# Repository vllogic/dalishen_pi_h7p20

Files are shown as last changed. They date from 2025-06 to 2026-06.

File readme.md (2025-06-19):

# 一、简介
#### &emsp;&emsp;大力神派是一款真●开源的FPGA开发板，在设计初期即以`Git`的方式公开项目进度及软硬件资料，期待与志同道合的同学们共同掌握FPGA应用方法，成长为全栈电子工程师。<br/>
#### &emsp;&emsp;在五毛钱单片机大行其道的今天，大力神派完全摒弃简易外设，仅针对USB2.0高速、RGMII千兆以太网、MIPI<sup>1</sup> 三个应用方向。通过板载下载器、USB Sniffer等功能实现开发、工具两用化。
* [1] 硬件接口预留，需FPGA原厂提供Demo

# 二、特色功能
#### &emsp;&emsp;下载器、开发板一体，割断JTAG相关短接点后，下载器可独立使用，支持京微齐力最新版本Fuxi及其绝大多数芯片
#### &emsp;&emsp;支持顶对顶连接20元包邮的`EZ-USB CY7A68013A板`，下载`examples/dalishen_pi_h7p20.ataradov.usb_sniffer`固件，即可变成USB2.0协议分析仪

# 三、板载芯片介绍
### [京微齐力 H7P20N0L128-M3H1](https://hercules-micro.com/index/index/core?id=16)
* 20K Logic cells
* LUT6架构
* 1152Kb EMB
* 内置ARM Cortex-M3 268MHz主频
* 2304KB SRAM
* 合封128Mb pSRAM
* LQFP128封装

### [爱科微 AIC8800FC](https://www.aicsemi.com/)
* 用于高速下载器/调试器
* 预留对外接口，限定3.3V电平

### YT8531C
* RGMII千兆PHY

### USB3343
* ULPI USB2.0高速PHY

# 四、接口介绍
### EZ-USB CY7A68013A对接口
* 用于连接EZ-USB CY7A68013A板，20元左右 [购买连接](https://item.taobao.com/item.htm?id=620955124878)

### MIPI DSI 40P连接器
* 用于连接5.0寸720*1280液晶显示屏，型号`D500C930SV0`带触摸，65元 [购买连接](https://item.taobao.com/item.htm?id=707705009617)
* 注意：MIPI接口当前仅预留，需后续开发支持

### MIPI CSI 24P连接器
* 用于连接OV5640 MIPI摄像头，规格`*-23AF`20元左右 [购买连接](https://item.taobao.com/item.htm?id=816198271497)
* 注意：MIPI接口当前仅预留，需后续开发支持

# 五、硬件
* 绘制中，尚未打样及测试
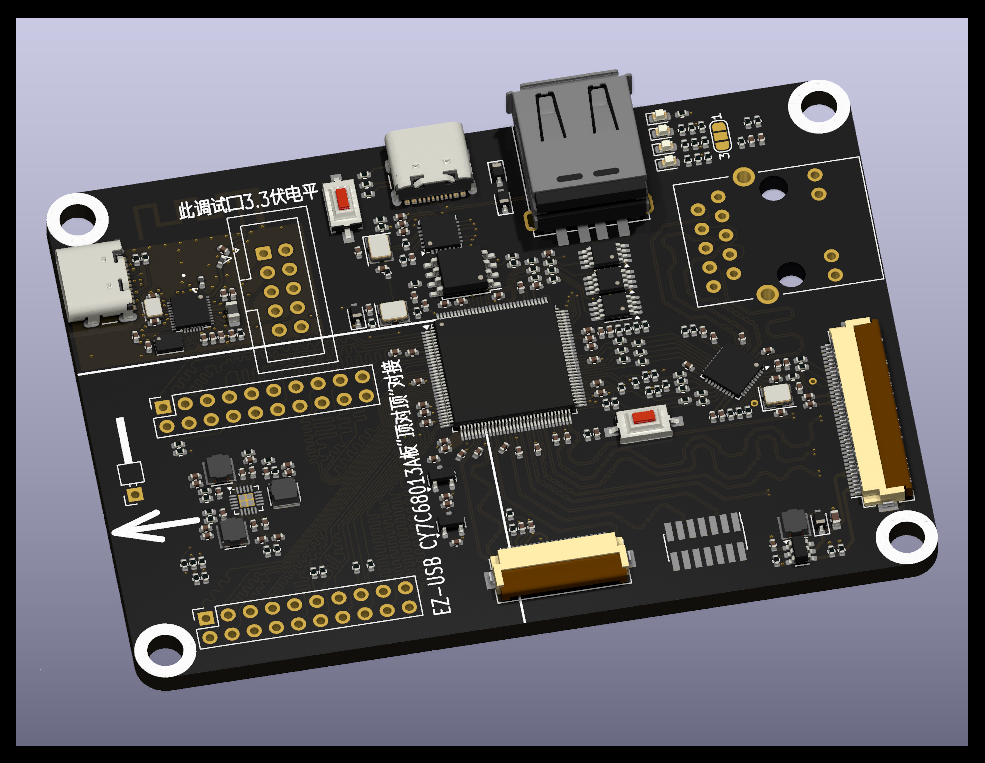
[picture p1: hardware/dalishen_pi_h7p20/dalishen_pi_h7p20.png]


# 六、例程
* [详细说明](./examples/readme.md)

# 七、交流群
* QQ群：635683631

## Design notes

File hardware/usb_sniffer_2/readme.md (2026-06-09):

___
# English
# I. Introduction
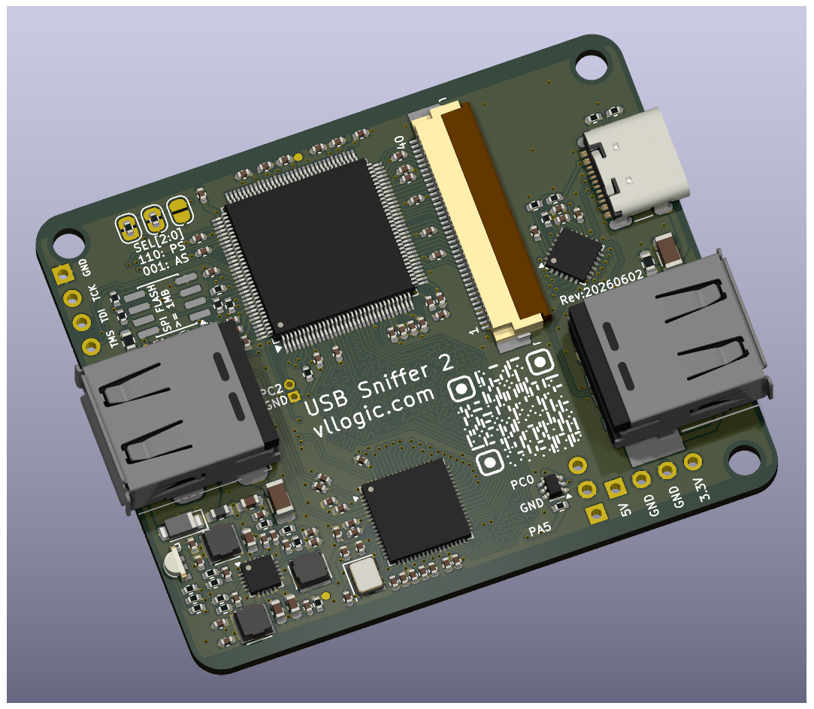
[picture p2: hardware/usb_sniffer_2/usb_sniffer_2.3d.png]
3D
* 
* Hardware design format: KiCad 9.0.6
* The CH32H417 serves as a USB 3.0 forwarder, with a unidirectional communication speed of up to 400MB/s, breaking the speed bottleneck of the 68013.
* 10 pairs of LVDS are broken out via an FFC connector, making it convenient to use as a USB 3.0 + FPGA expansion board.
* Default is PS mode, with reserved SPI FLASH pads. It supports adjustment to AS mode to facilitate secondary development.
# II. Main Components
1. [HME H7P20N0L128-M3H1](https://hercules-micro.com/index/index/core?id=16)
2. [WCH CH32H417WEU6](https://www.wch-ic.com/products/CH32H417.html)
3. [Microchip USB3343-CP-TR](https://www.microchip.com/en-us/product/usb3343)
# III. Schematic
* [Full PDF](https://www.google.com/search?q=./usb_sniffer_2.pdf)
___
# 中文
## 一、简介
* 3D
* 硬件图纸格式：Kicad 9.0.6
* CH32H417作为USB3.0转发器，单向通信速率可达400MB/S，解除68013的速率瓶颈
* 通过FFC连接器引出10对LVDS，方便作为USB3.0 + FPGA拓展板
* 默认PS模式，预留SPI FLASH焊盘，支持调整为AS模式，方便二次开发
## 二、主要器件
1. [HME H7P20N0L128-M3H1](https://hercules-micro.com/index/index/core?id=16)
2. [WCH CH32H417WEU6](https://www.wch-ic.com/products/CH32H417.html)
3. [Microchip USB3343-CP-TR](https://www.microchip.com/en-us/product/usb3343)
## 三、原理图
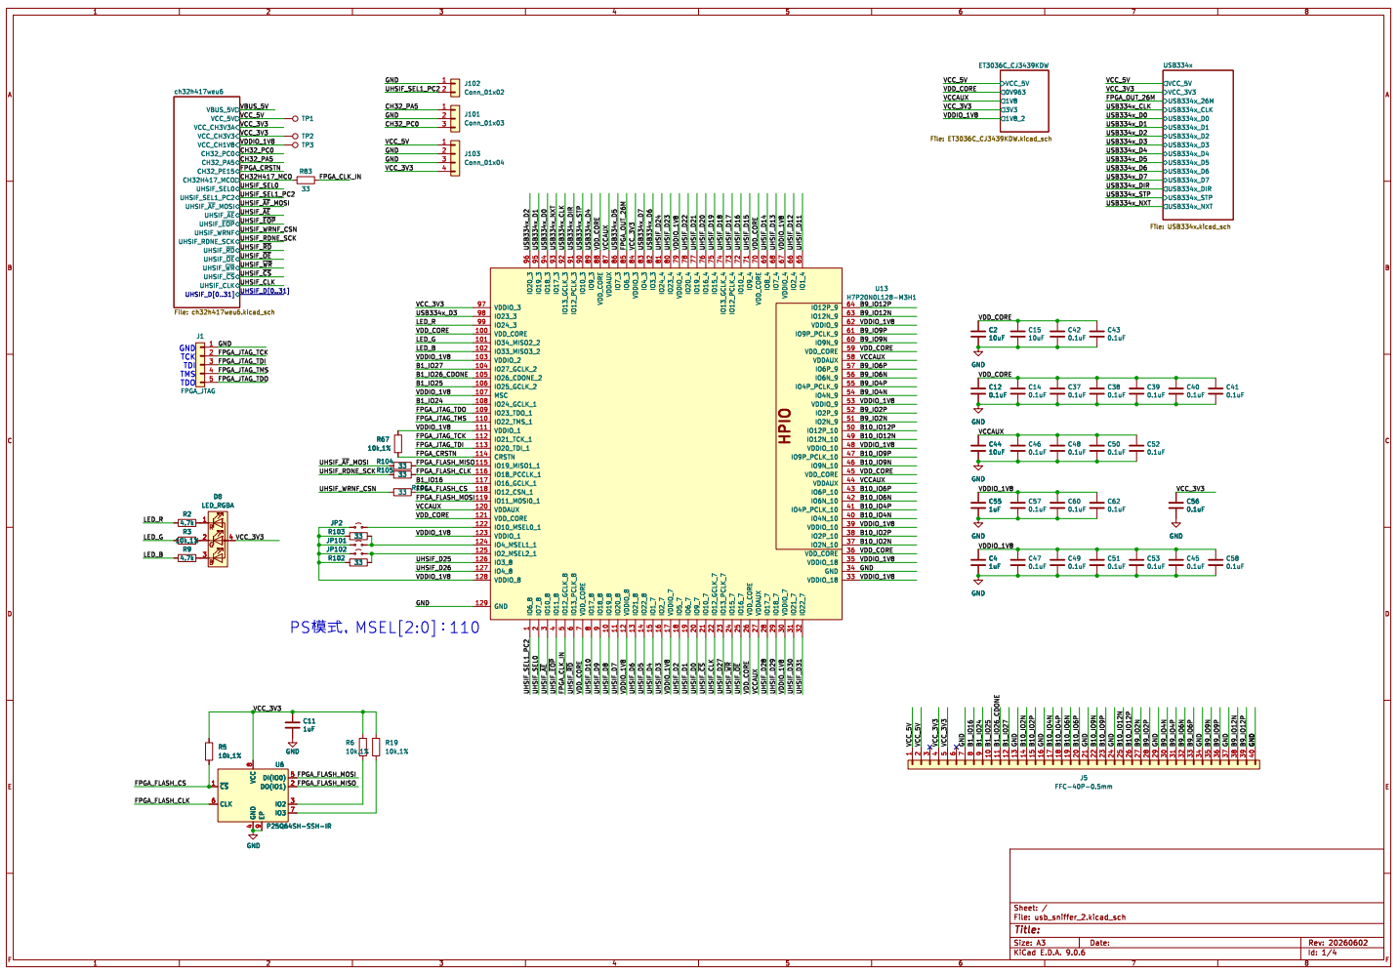
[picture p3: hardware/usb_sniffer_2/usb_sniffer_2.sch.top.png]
* 
* [完整PDF](./usb_sniffer_2.pdf)
___

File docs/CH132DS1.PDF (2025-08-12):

# CH132 数据手册

V2.2

概述

CH132 是 ULPI 接口的高速 USB 收发器芯片（USB PHY、High Speed Transceiver)，兼容 USB 2.0

协议规范和 UTMI+ Low Pin Interface（ULPI）1.1 协议规范。支持 USB2.0 高速 480Mbps、全速 12Mbps

和低速 1.5Mbps 数据发送和接收，可用于为具有 ULPI 接口的 MCU 或 FPGA 扩展 USB 主机口或者设备口。

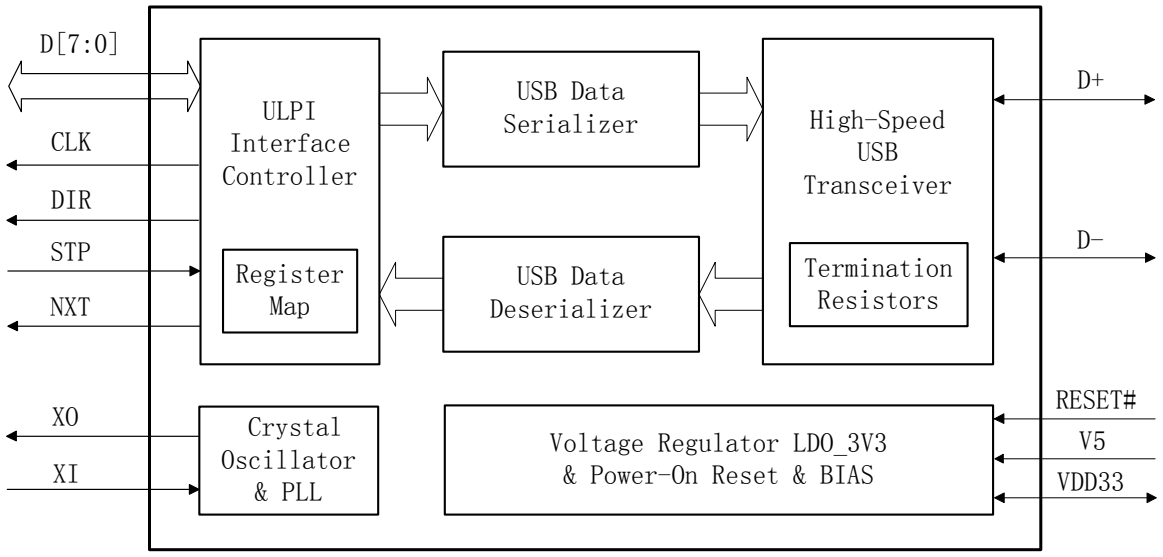
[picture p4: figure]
ULPI Interface Controller; Register Map; USB Data Serializer; USB Data Deserializer; High-Speed USB Transceiver; Termination Resistors; NXT; STP; DIR; CLK; Voltage Regulator LDO_3V3 & Power-On Reset & BIAS; Crystal Oscillator & PLL; RESET# V5 VDD33

特点

- 兼容 USB 2.0 协议规范
- 兼容 UTMI+ Low Pin Interface（ULPI）1.1 协议规范
- 12 Pin 的 ULPI 接口，1.8V～3.3V IO 电平，60MHz 时钟
- 支持 USB host 主机和 USB device 设备
- 支持 USB 高速 High Speed、全速 Full Speed 和低速 Low Speed
- 支持 3 线或 6 线的全速或低速串行模式
- 支持 D+和 D-信号线交换模式
- 内置 3.3V 低压差线性稳压器，支持 3.3V 或 5V 供电输入
- 内置上电复位电路、内置时钟振荡器和 PLL
- 内置阻抗匹配电阻，内置振荡电容，外围电路精简
- 支持 ULPI 输入时钟和输出时钟模式
- USB 引脚具有 6KV 增强 ESD 性能
- 工业级温度范围：-40～85℃
- 提供 QFN24 和 QFN32 等多种封装形式

## 第 1 章 引脚信息

## 1.1 引脚排列

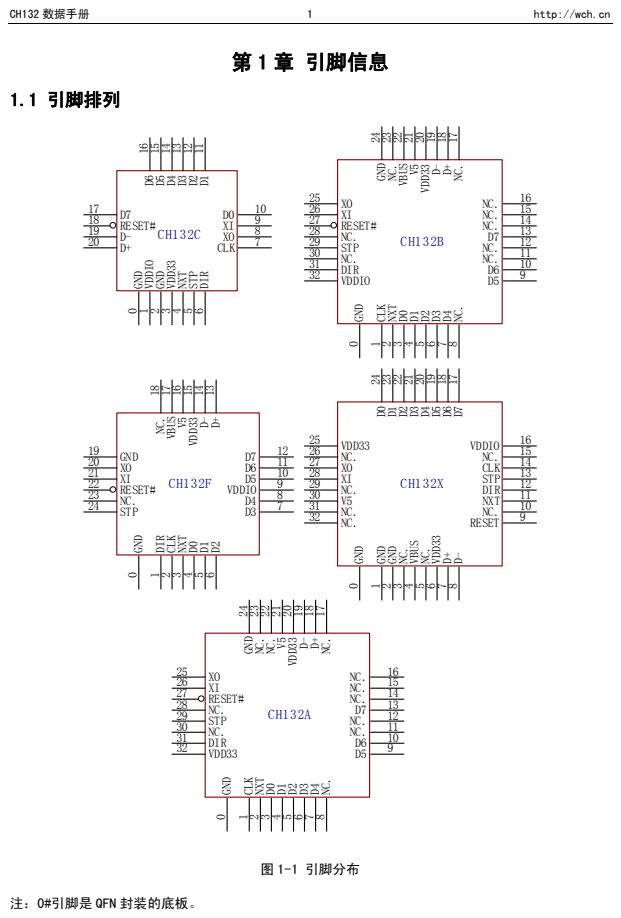
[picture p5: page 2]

CH132 数据手册 | 2 | http://wch.cn

## 1.2 封装

表 1-1 封装说明

封装形式 | 塑体宽度 | 引脚节距 | 封装说明 | 订货型号
QFN20C_2x2 | 2*2mm | | 0.32mm | 12.6mil | WCH 四边无引线 20 脚 | CH132C
QFN24_4x4 | 4*4mm | | 0.5mm | 19.7mil | 四边无引线 24 脚 | CH132F
QFN32_5x5 | 5*5mm | | 0.5mm | 19.7mil | 四边无引线 32 脚 | CH132B
QFN32_5x5 | 5*5mm | | 0.5mm | 19.7mil | 四边无引线 32 脚 | CH132A
QFN32_5x5 | 5*5mm | | 0.5mm | 19.7mil | 四边无引线 32 脚 | CH132X

注：CH132B 基于 CH132A 升级，增加了 VDDIO 引脚，向前兼容 CH132A 引脚。

新设计可用 CH132C/F/B/X，优选小体积的 CH132C。

## 1.3 引脚描述

表 1-2 引脚定义

引脚号 | 引脚 名称 | 类型 | 功能描述
132C | 132F | 132A | 132B | 132X
20 | 13 | 18 | 18 | 7 | D+ | USB | USB2.0 高速差分信号线 DP
19 | 14 | 19 | 19 | 8 | D- | USB | USB2.0 高速差分信号线 DM
- | - | 1 | - | - | CLK | O | ULPI 60MHz 时钟信号输出
7 | 2 | - | 1 | 14 | CLK | I/O | ULPI 60MHz 时钟信号输出或 60MHz 时钟信号输入
4 | 3 | 2 | 2 | 11 | NXT | O | ULPI Next 信号输出
6 | 1 | 31 | 31 | 12 | DIR | O | ULPI Direction 信号输出
5 | 24 | 29 | 29 | 13 | STP | I | ULPI Stop 信号输入，内置可控上拉电流
10 | 4 | 3 | 3 | 24 | D0 | I/O | ULPI 双向数据线 DATA0，内置弱下拉电阻
11 | 5 | 4 | 4 | 23 | D1 | I/O | ULPI 双向数据线 DATA1，内置弱下拉电阻
12 | 6 | 5 | 5 | 22 | D2 | I/O | ULPI 双向数据线 DATA2，内置弱下拉电阻
13 | 7 | 6 | 6 | 21 | D3 | I/O | ULPI 双向数据线 DATA3，内置弱下拉电阻
14 | 8 | 7 | 7 | 20 | D4 | I/O | ULPI 双向数据线 DATA4，内置弱下拉电阻
15 | 10 | 9 | 9 | 19 | D5 | I/O | ULPI 双向数据线 DATA5，内置弱下拉电阻
16 | 11 | 10 | 10 | 18 | D6 | I/O | ULPI 双向数据线 DATA6，内置弱下拉电阻
17 | 12 | 13 | 13 | 17 | D7 | I/O | ULPI 双向数据线 DATA7，内置弱下拉电阻
- | - | 26 | - | - | XI | IL | 晶振输入端，外接 12MHz 晶体一端，或外部时钟输入

CH132 数据手册 | 3 | http://wch.cn
9 | 21 | - | 26 | 27 | XI | IL | 晶振输入端，外接 12MHz 晶体一端，或外部时钟输入， 或短接 GND 则选择从 CLK 引脚输入 ULPI 时钟模式
8 | 20 | 25 | 25 | 28 | XO | OL | 晶振反相输出端，需外接 12MHz 晶体另一端
18 | 22 | 27 | 27 | - | RESET# | I | 复位信号输入，低电平有效，内置上拉电阻
- | - | - | - | 9 | RESET | I | 复位信号输入，高电平有效，内置下拉电阻
- | 17 | - | 22 | 4 | VBUS | I | VBUS 检测输入，高电平有效，内置上拉电阻， 部分型号或批号不支持 VBUS，建议悬空或短接 VDD33
- | 16 | 21 | 21 | 30 | V5 | P | 5V 或 3.3V 电源输入，外接 1uF～10uF 退耦电容
- | 15 | 20 | 20 | 6 | VDD33 | P | LDO 输出及 3.3V 电源输入，外接 0.1uF 并联 1uF～10uF 退耦电容
3 | - | 32 | - | 25 | VDD33 | P | 3.3V 电源输入
1 | 9 | - | 32 | 16 | VDDIO | P | ULPI 接口 I/O 信号电源电压，支持 1.8V、2.5V、3.3V 电压，外接 0.1uF 或 1uF 退耦电容
2 | 19 | 24 | 24 | 1, 2 | GND | P | 公共接地端，可选但建议连接 GND
0 | 0 | 0 | 0 | 0 | GND | P | 公共接地端（QFN 底板），必要连接
- | 18, 23 | 8, 11, 12, 14, 15, 16, 17, 22, 23, 28, 30 | 8, 11, 12, 14, 15, 16, 17, 23, 28, 30 | 3, 5, 10, 15, 26, 29, 31, 32 | NC. | - | 空脚或保留引脚，禁止连接

引脚类型：

(1) I：对于 CH132A 是 3.3V 信号输入，对于 CH132C/F/B/X 是 VDDIO 电压的信号输入。
(2) O：对于 CH132A 是 3.3V 信号输出，对于 CH132C/F/B/X 是 VDDIO 电压的信号输出。
(3) IL：额定 1.2V 电压的信号输入，支持 1.2V～1.4V 电压的信号输入。
(4) OL：额定 1.2V 电压的信号输出。
(5) P：电源或地。
(6) USB：USB 信号。

CH132 数据手册 | 4 | http://wch.cn

## 第 2 章 基本功能

## 2.1 时钟和复位

### 2.1.1 时钟源

CH132 需要 12MHz 时钟源，可以从 XI 引脚输入时钟并保持 XO 悬空，或者将外部 12MHz 晶体连接

在 XI 和 XO 引脚上通过内部振荡器产生时钟源。CH132 再通过 PLL 产生芯片所需的多个时钟：

- USB 低速数据传输使用的 1.5MHz 时钟
- USB 全速数据传输使用的 12MHz 时钟
- USB 高速数据传输使用的 480MHz 时钟
- ULPI 接口控制器使用的 60MHz 时钟
- 其它内部数据处理时需要的时钟

默认情况下为输出 ULPI 时钟模式，从 CLK 引脚向 ULPI 链接器 LINK 输出 60MHz 时钟。

CH132C/F/B/X 还支持输入 ULPI 时钟模式，上电复位期间，如果 CH132 检测到 XI 引脚短接 GND，

则 CLK 引脚为时钟输入，由 ULPI 链接器 LINK 提供 60MHz 时钟，CH132 再由此产生所需的各时钟。

### 2.1.2 上电复位

CH132 内置了上电复位模块，一般无需外部提供复位信号，当电源上电时，芯片内部 POR 上电复

位模块会产生上电复位时序，并延时 Trpor 以等待电源稳定。在运行过程中，当电源电压低于 Vlvr时，

芯片内部 LVR 低压复位模块会产生低压复位直到电压回升，并延时以等待电源稳定。图 2-1 为上电复

位过程以及低压复位过程。

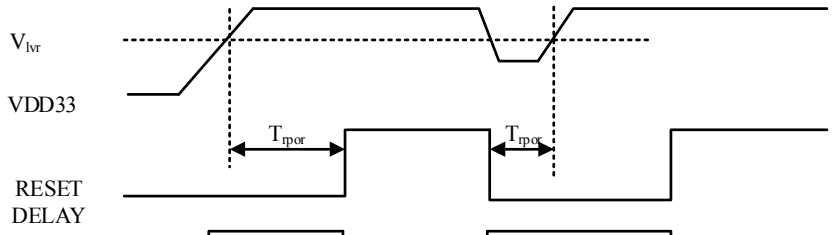
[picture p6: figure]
Vlvr; VDD33; RESET DELAY; Trpor

INTERNAL
RESET

图 2-1 上电复位

### 2.1.3 外部复位

外部复位输入引脚 RESET#内置约 24KΩ上拉电阻，如果外部需要对芯片进行复位，那么可以将该

引脚驱动为低电平（建议开漏驱动），复位的低电平脉宽至少 Twreset。建议不要再外接上拉电阻。

CH132X 的外部复位输入引脚 RESET 内置下拉电阻，驱动该引脚为高电平将复位芯片。

## 2.2 电源

CH132 数据手册 | 5 | http://wch.cn

CH132 内置了低压差线性稳压器 LDO。默认为 3.3V 电源，也支持 5V 电源。

对于 3.3V 供电系统，3.3V 电源同时输入 VDD33 引脚和 V5 引脚，用于内部模拟电路。

对于 5V 供电系统，5V 电源输入 V5 引脚，内部 LDO 在 VDD33 引脚产生 3.3V 电源用于内部模拟电

路。CH132C 没有 V5 引脚，不支持 5V 供电。

两种方式下，VDD33 和 V5 引脚都需要外接退耦电容，VDD33 建议 0.1uF 并联 10uF 或 4.7uF。

避免将 VBUS 的 5V 电源直接输入 V5 引脚，建议在 VBUS 与 V5 引脚之间加入过压保护电路。

对于 CH132C/F/B/X，VDDIO 引脚用于 I/O 电路供电，支持 1.8V、2.5V、3.3V 电压。对于 CH132A，

VDD33 引脚兼用于 I/O 电路供电，仅支持 3.3V 电压。

## 2.3 USB 收发器

CH132 的 USB 收发器承担了 USB 高速、全速和低速数据收发任务。收发器 Transceiver 包括进行

USB 高速、全速和低速数据发送必需的差分驱动电路，承担 USB 高速、全速和低速数据接收的差分和

单端接受器，探测高速总线活动性的电路，探测高速总线断开的电路。USB 端口内置了多种匹配电阻，

包括阻抗匹配电阻、设备上拉电阻、主机下拉电阻等。

关于寄存器和 USB 端口模式的详细关系可以见下表 2-1。

表 2-1 寄存器设置和端口模式关系

USB 端口模式 | 寄存器设置
XCVR SELECT[1:0] | TERM SELECT | OP MODE[1:0] | DP_ PULLDOWN | DM_ PULLDOWN
三态驱动 | xxb | x | 01b | x | x
主机 Chirp | 00b | 0 | 10b | 1 | 1
主机高速 | 00b | 0 | 00b | 1 | 1
主机全速 | x1b | 1 | 00b | 1 | 1
主机高速或全速挂起 | 01b | 1 | 00b | 1 | 1
主机高速或全速恢复 | 01b | 1 | 10b | 1 | 1
主机低速 | 10b | 1 | 00b | 1 | 1
主机低速挂起 | 10b | 1 | 00b | 1 | 1
主机低速恢复 | 10b | 1 | 10b | 1 | 1
主机发送 J 信号/K 信号 | 00b | 0 | 10b | 1 | 1
从机 Chirp | 00b | 1 | 10b | 0 | 0
从机高速 | 00b | 0 | 00b | 0 | 0
从机全速 | 01b | 1 | 00b | 0 | 0
从机高速或全速挂起 | 01b | 1 | 00b | 0 | 0
从机高速或全速恢复 | 01b | 1 | 10b | 0 | 0
从机发送 J 信号或 K 信号 | 00b | 0 | 10b | 0 | 0

## 2.4 ULPI 接口控制器

CH132 数据手册 | 6 | http://wch.cn

CH132 提供了兼容 ULPI（UTMI+ Low Pin Interface）1.1 协议的 12 Pin 接口，这个接口应该连

接到 ULPI 链接器 LINK 的 ULPI 接口上，链接器另一端是 USB 控制器。

此 ULPI 接口控制器具有以下功能：

- ULPI 协议兼容的接口和寄存器设置
- 允许通过 USB 主机或从机设备进行功能性控制
- 解析 USB 发送或接收的数据
- 确定 USB 数据发送、数据接收、中断和寄存器操作优先级
- 3 线串行模式
- 6 线串行模式

## 2.5 ULPI RX CMD 数据

表 2-2 RXCMD 数据位格式

位 | 名称 | 默认值 | 描述
[1:0] | LineState | 00b | 对应 UTMI+ LineState 两个信号： LineState[0]对应接收 DP 的单端数据， LineState[1]对应接收 DM 的单端数据
[3:2] | Reserved | 00b | 保留，总是 00
[5:4] | RxEvent | 00b | UTMI 事件信号编码：
数值 | RxActive | RxError | HostDisconnect
00 | 0 | 0 | 0
01 | 1 | 0 | 0
11 | 1 | 1 | 0
10 | X | X | 1
6 | Reserved | 0 | 保留，总是 0
7 | Reserved | 0 | 保留，数据需忽略

## 2.6 3 线和 6 线串行模式

CH132 提供了 3 线或 6 线串行模式，根据需要选择 3 线或 6 线接口的串行模式以传输全速或低速

USB 包。3 线串行模式接口映射如表 2-3 所示，6 线串行模式接口映射如表 2-4 所示。

进入或退出 3 线或 6 线串行模式可以参考 R8_INTF_CTRL 寄存器中关于 3PIN_FSLS_SERIAL 或

6PIN_FSLS_SERIAL 位的描述。

表 2-3 3 线串行接口 ULPI 映射表

信号 | 对应 ULPI 接口 | 方向 | 描述

CH132 数据手册 | 7 | http://wch.cn
信号 | 对应 ULPI 接口 | 方向 | 描述
TX_ENABLE | DATA0 | I | 模式选择，发送使能，高电平有效 0：接收数据； 1：发送数据
DAT | DATA1 | I/O | TX_ENABLE = 1 时，发送 DP 和 DM 的差分数据； TX_ENABLE = 0 时，接收 DP 和 DM 的差分数据
SE0 | DATA2 | I/O | TX_ENABLE = 1 时，发送 DP 和 DM 的 SE0 数据； TX_ENABLE = 0 时，接收 DP 和 DM 的 SE0 数据
Reserved | DATA3 | O, PD | 保留，CH132 引脚输出数据需忽略
Reserved[7:4] | DATA[7:4] | O, PD | 保留，CH132 引脚提供下拉电阻或输出低电平

表 2-4 6 线串行接口 ULPI 映射表

信号 | 对应 ULPI 接口 | 方向 | 描述
TX_ENABLE | DATA0 | I | 发送使能，高电平有效
TX_DAT | DATA1 | I | 发送 DP 和 DM 的差分数据。
TX_SE0 | DATA2 | I | 发送 DP 和 DM 的 SE0 数据。
Reserved | DATA3 | O, PD | 保留，CH132 引脚输出数据需忽略
RX_DP | DATA4 | O | 接收 DP 的单端数据
RX_DM | DATA5 | O | 接收 DM 的单端数据
RX_RCV | DATA6 | O | 接收 DP 和 DM 的差分数据
Reserved | DATA7 | O, PD | 保留，CH132 引脚提供下拉电阻或输出低电平

CH132 数据手册 | 8 | http://wch.cn

## 第 3 章 ULPI 寄存器

## 3.1 寄存器描述

本手册中在对寄存器进行描述时可能使用了下列缩写：

寄存器位属性 | 属性描述
RO | 只读属性，数据由硬件生成和改变。
WO | 只写属性（不可读，读值不确定）
RW | 可读，可写。

CH132 系列芯片 ULPI 接口操作相关寄存器描述，默认基于 CH132B 和 CH132C/F/X。其它型号例

如 CH132A，如果存在部分不同则特别加注。本手册不适用于 CH132H。

表 3-1 CH132 ULPI 寄存器表

名称 | 地址（6 bit） | 描述 | 复位值
Read | Write | Set | Clear
R8_VENDOR_ID_L | 0x00 | - | - | - | 厂商 ID 寄存器的低字节 | 0x86 [注 10]
R8_VENDOR_ID_H | 0x01 | - | - | - | 厂商 ID 寄存器的高字节 | 0x1A [注 11]
R8_PRODUCT_ID_L | 0x02 | - | - | - | 产品 ID 寄存器的低字节 | 0x32 [注 12]
R8_PRODUCT_ID_H | 0x03 | - | - | - | 产品 ID 寄存器的高字节 | 0x01 [注 13]
R8_FUNC_CTRL | 0x04–0x06 | 0x04 | 0x05 | 0x06 | 功能控制寄存器 | 0x41
R8_INTF_CTRL | 0x07–0x09 | 0x07 | 0x08 | 0x09 | 接口控制寄存器 | 0x00
R8_OTG_CTRL | 0x0A–0x0C | 0x0A | 0x0B | 0x0C | OTG 控制寄存器 | 0x06
R8_USB_INTR_EN_R | 0x0D–0x0F | 0x0D | 0x0E | 0x0F | USB 上升中断使能寄存器 | 0x01
R8_USB_INTR_EN_F | 0x10–0x12 | 0x10 | 0x11 | 0x12 | USB 下降中断使能寄存器 | 0x01
R8_USB_INTR_STAT | 0x13 | - | - | - | USB 中断状态寄存器 | 0x00
R8_USB_INTR_L | 0x14 | - | - | - | USB 中断锁存寄存器 | 0x00
R8_SCRATCH | 0x16–0x18 | 0x16 | 0x17 | 0x18 | 测试寄存器 | 0x00
R8_USB_IO_SWAP | 0x39–0x3B | 0x39 | 0x3A | 0x3B | USB I/O 引脚交换寄存器 | 0x00 [注 14]
| 其它 | | | | 保留 | 0x00

（1）R：Read，可读寄存器，如果没有对应的 W/S/C 则说明是只读寄存器。

（2）W：Write，寄存器写入，操作时新的数据将直接覆盖此寄存器原有的数据。

（3）S：Set，寄存器按位置 1，操作时新的数据将与此寄存器原数据按位或运算后写入。

（4）C：Clear，寄存器按位清 0，操作时新的数据将与此寄存器原数据按位与运算后写入。

注 10、注 11、注 12、注 13：对于 CH132A 为 0x00。

注 14：CH132A 不支持此寄存器。

建议：每次上电或复位后向 R8_FUNC_CTRL 和 R8_OTG_CTRL 寄存器中设置目标参数，不管原值；

无需操作和使用 R8_USB_INTR_*各寄存器，可以用 RXCMD 中的 RxEvent/LineState 状态实现。

CH132 数据手册 | 9 | http://wch.cn

功能控制寄存器（R8_FUNC_CTRL, Address R = 04h/05h/06h,W = 04h,S = 05h,C = 06h）

位 | 名称 | 访问 | 描述 | 复位值
7 | Reserved | RO | 保留 | 0
6 | SUSPENDM | RW | 芯片挂起： 进入低功耗模式，低有效。ULPI 链接器可以通过 STP 退 出低功耗模式。当芯片退出低功耗模式自动置 1 此位。 0：低功耗模式； 1：正常。 | 1
5 | RESET | RW | 内部复位： 高有效。此复位不复位 ULPI 接口和寄存器。 当复位结束后，芯片将解除 DIR 并自动清零此位。 0：正常； 1：使能复位。 | 0
[4:3] | OP MODE | RW | 操作模式：选择传输过程中的位编码方式。 00：正常； 01：不驱动； 10：关闭位插入和 NRZI 编码； 11：保留 | 00b
2 | TERM SELECT | RW | 端口电阻选项： 控制端口上拉下拉电阻和高速传输匹配电阻，取决于 XCVR SELECT、OP MODE、DP_PULLDOWN 和 DM_PULLDOWN。 详见表 2-1 | 0
[1:0] | XCVR SELECT | RW | 收发器速度选择： 00：使能高速收发器； 01：使能全速收发器； 10：使能低速收发器； 11：使能全速收发器，收发低速包（自动加全速包前缀） | 01b

接口控制寄存器（R8_INTF_CTRL, Address R = 07h/08h/09h,W = 07h,S = 08h,C = 09h）

位 | 名称 | 访问 | 描述 | 复位值
7 | INTF_PROT_DIS | RW | 关闭接口保护： 当 ULPI 链接器不向 STP 和 DATA[7:0]输出时，控制芯片内 置的 ULPI 接口保护电路。 0：使能 ULPI 接口保护电路，STP 提供弱上拉。 1：关闭 ULPI 保护电路，关闭 STP 的弱上拉 | 0
[6:2] | Reserved | RO | 保留 | 00000b
1 | 3PIN_FSLS_SERIAL | RW | 3 线全速低速串行模式： 将 ULPI 接口变为 3 位串行接口，在退出 3 线串行模式时芯 | 0

CH132 数据手册 | 10 | http://wch.cn
| | | 片自动清零此位。 0：关闭 3 线串行模式，全速低速包通过 ULPI 并口传输； 1：使能 3 线串行模式，全速低速包通过 3 线接口传输
0 | 6PIN_FSLS_SERIAL | RW | 6 线全速低速串行模式： 将 ULPI 接口变为 6 位串行接口，在退出 6 线串行模式时芯 片自动清零此位。 0：关闭 6 线串行模式，全速低速包通过 ULPI 并口传输； 1：使能 6 线串行模式，全速低速包通过 6 线接口传输 | 0

OTG 控制寄存器（R8_OTG_CTRL, Address R = 0Ah/0Bh/0Ch,W = 0Ah,S = 0Bh,C = 0Ch）

位 | 名称 | 访问 | 描述 | 复位值
[7:3] | Reserved | RO | 保留 | 00000b
2 | DM_PULLDOWN | RW | 使能 DM 的主机下拉电阻： 0：关闭 DM 的下拉电阻； 1：使能 DM 的下拉电阻 | 1
1 | DP_PULLDOWN | RW | 使能 DP 的主机下拉电阻： 0：关闭 DP 的下拉电阻； 1：使能 DP 的下拉电阻 | 1
0 | Reserved | RO | 保留 | 0

USB 上升中断使能寄存器（R8_USB_INTR_EN_R, Address R = 0Dh/0Eh/0Fh,W = 0Dh,S = 0Eh,C = 0Fh）

位 | 名称 | 访问 | 描述 | 复位值
[7:1] | Reserved | RO | 保留 | 0000000b
0 | HOST_DISCON_R | RW | 主机端口断开中断使能： 使能当 HOST_DISCON 从 0 到 1，即断开时产生中断 | 1

USB 下降中断使能寄存器（R8_USB_INTR_EN_F, Address R = 10h/11h/12h,W = 10h,S = 11h,C = 12h）

位 | 名称 | 访问 | 描述 | 复位值
[7:1] | Reserved | RO | 保留 | 0000000b
0 | HOST_DISCON_F | RW | 主机端口断开中断使能： 使能当 HOST_DISCON 从 1 到 0，即连接时产生中断 | 1

USB 中断状态寄存器（R8_USB_INTR_STAT, Address R = 13h）

位 | 名称 | 访问 | 描述 | 复位值

CH132 数据手册 | 11 | http://wch.cn
位 | 名称 | 访问 | 描述 | 复位值
[7:1] | Reserved | RO | 保留 | 0000000b
0 | HOST_DISCON | RO | 主机端口断开状态： 提供 UTMI+主机端口断开状态值。 0：已连接，主机端口检测到 USB 设备； 1：已断开，没有检测到 USB 设备连接。 只支持高速 USB 断开检测，不支持全速和低速断开检测 | 0

USB 中断锁存寄存器（R8_USB_INTR_L, Address R = 14h）

位 | 名称 | 访问 | 描述 | 复位值
[7:1] | Reserved | RO | 保留 | 0000000b
0 | HOST_DISCON | RO | 锁存主机端口断开状态： 当一个未屏蔽的 HOST_DISCON 事件发生时，此位置 1，读 取时自动清零 | 0

测试寄存器（R8_SCARTCH, Address R = 16h）

位 | 名称 | 访问 | 描述 | 复位值
[7:0] | SCARTCH | RW | 测试使用的寄存器，可读可写，不影响芯片功能 | 00000000b

USB I/O 引脚交换寄存器（R8_USB_IO_SWAP, Address R = 39h/3Ah/3Bh,W = 39h,S = 3Ah,C = 3Bh）

位 | 名称 | 访问 | 描述 | 复位值
[7:2] | Reserved | RO | 保留 | 000000b
1 | USB_IO_SWAP | RW | 交换 USB 信号引脚使能： 0：不交换 D+和 D-引脚； 1：交换 D+和 D-引脚 | 0
0 | Reserved | RO | 保留 | 0

CH132 数据手册 | 12 | http://wch.cn

## 第 4 章 参数

### 4.1 绝对最大值（临界或者超过绝对最大值将可能导致芯片工作不正常甚至损坏）

名称 | 参数说明 | 最小值 | 最大值 | 单位
TA | 工作时的环境温度 | -40 | 85 | ℃
TS | 储存时的环境温度 | -55 | 150 | ℃
V5 | LDO 输入电源电压（V5 引脚接电源，GND 引脚接地） | -0.4 | 5.5 | V
VDD33 | 3.3V 电源电压（VDD33 引脚接电源，GND 引脚接地） | -0.4 | 3.8 | V
VDDIO | VDDIO 引脚的 ULPI 接口 I/O 电源电压 | -0.4 | 3.8 | V
VUSB | USB 信号引脚上的电压 | -0.4 | VDD33+0.4 | V
VIO | 其它输入或者输出引脚上的电压（不含 XI 和 XO） | -0.4 | VDD33+0.4 VDDIO+0.4 | V
VXI | XI 引脚上的电压 | -0.3 | 1.5 | V
VESD | USB 引脚上的 HBM 人体模型 ESD 耐压 | 6K | | V

### 4.2 电气参数（测试条件：TA=25℃，V5=VDD33=3.3V，VDDIO=3.3V，不含 USB 信号引脚）

名称 | 参数说明 | 最小值 | 典型值 | 最大值 | 单位
V5 | CH132F/B/X | LDO 输入电源电压， 启用内部 LDO | 3.8 | 5.0 | 5.25 | V
| CH132A | | 4.5 | 5.0 | 5.25
| 外供电源电压 | 无需内部 LDO | 3.15 | 3.3 | 3.45
VDD33 | LDO 输出电压 | 启用内部 LDO | 3.15 | 3.3 | 3.45 | V
| 外供 3.3V 电压 | 无需内部 LDO | 3.15 | 3.3 | 3.45
VDDIO | ULPI 接口 I/O 信号电源电压 | | 1.7 | 3.3 | 3.6 | V
ILDO | 内部电源调节器 LDO 对外负载能力 | | | | 30 | mA
ICC | 高速 USB 传输时的工作电流 | | | 27 | | mA
ICC0 | 高速空闲状态下的工作电流 | | | 19 | | mA
ISLP | 低功耗模式的电源电流（主要是内部 LDO） | | | 0.13 | 0.4 | mA
VILXI | XI 引脚低电平输入电压 | | 0 | | 0.3 | V
VIHXI | XI 引脚高电平输入电压 | | 0.9 | | 1.2 | V
RPD | D7～D0 引脚的下拉电阻 | | 50 | 70 | 100 | KΩ
Vlvr | VDD33 电源低压复位的电压门限 | | 2.5 | 2.9 | 3.15 | V

CH132 数据手册 | 13 | http://wch.cn

VDDIO=3.3V

VIL33 | ULPI 接口 I/O 引脚低电平输入电压 | 0 | | 0.8 | V
VIH33 | ULPI 接口 I/O 引脚高电平输入电压 | 1.9 | | VDDIO | V
VOL33 | I/O 引脚低电平输出电压 @吸入 12mA 电流 | | 0.4 | 0.6 | V
VOH33 | I/O 引脚高电平输出电压 @输出 12mA 电流 | VDDIO-0.6 | VDDIO-0.4 | | V
IPU33 | STP 引脚的上拉电流 | 20 | 40 | 80 | uA

VDDIO=1.8V

VIL18 | ULPI 接口 I/O 引脚低电平输入电压 | 0 | | 0.5 | V
VIH18 | ULPI 接口 I/O 引脚高电平输入电压 | 1.2 | | VDDIO | V
VOL18 | I/O 引脚低电平输出电压 @吸入 5mA 电流 | | 0.4 | 0.6 | V
VOH18 | I/O 引脚高电平输出电压 @输出 5mA 电流 | VDDIO-0.6 | VDDIO-0.4 | | V
IPU18 | STP 引脚的上拉电流 | 7 | 15 | 30 | uA

### 4.3 时序参数（测试条件：TA=25℃，V5=VDD33=3.3V，VDDIO=3.3V）

名称 | 参数说明 | 最小值 | 典型值 | 最大值 | 单位
Fxi | XI 输入时钟频率、XI 外接晶体频率 | 11.995 | 12 | 12.005 | MHz
Dutyxi | XI 输入时钟的占空比 | 35 | 50 | 65 | %
Fstart | 初始状态下 ULPI 的 CLK 时钟频率 | 55 | 60 | 65 | MHz
Fsteady | 稳定状态下 ULPI 的 CLK 时钟频率 | 59.97 | 60 | 60.03 | MHz
Dutycko | ULPI 的 CLK 时钟的占空比 | 45 | 50 | 55 | %
Tsteady | XI 或 CLK 输入时钟稳定到 PLL 稳定的时间 | | 0.5 | 1.5 | mS
Tstart | 退出低功耗模式到 PLL 稳定的时间 | | 2 | 4 | mS
Trpor | 电源上电或低压复位到正常工作的时间 | 10 | 14 | 17 | mS
Twreset | RESET#引脚输入复位的低电平脉宽 | 2 | | | uS
| RESET 引脚输入复位的高电平脉宽 | 2 | | | uS
Trreset | 引脚输入复位到正常工作的时间 | 10 | 13 | 15 | mS

输出 ULPI 时钟模式

TSC | STP 输入建立时间 | | 6 | nS
THC | STP 输入保持时间 | 0 | | nS
TSD | 数据 D0～D7 输入建立时间 | | 6 | nS

CH132 数据手册 | 14 | http://wch.cn
THD | 数据 D0～D7 输入保持时间 | 0 | | nS
TDC | DIR 或 NXT 输出有效的延时 | 0.8 | 6 | nS
TDD | 数据 D0～D7 输出有效的延时 | 0.8 | 8 | nS

输入 ULPI 时钟模式

TSC | STP 输入建立时间 | | 2.5 | nS
THC | STP 输入保持时间 | 1 | | nS
TSD | 数据 D0～D7 输入建立时间 | | 2.5 | nS
THD | 数据 D0～D7 输入保持时间 | 1 | | nS
TDC | DIR 或 NXT 输出有效的延时 | 1.5 | 6.5 | nS
TDD | 数据 D0～D7 输出有效的延时 | 1.5 | 7 | nS

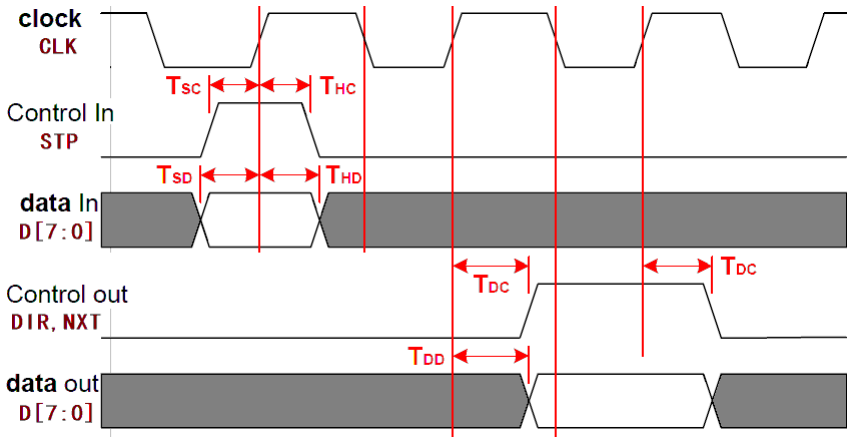
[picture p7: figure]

## 第 5 章 封装

## 5.1 QFN20C_2x2

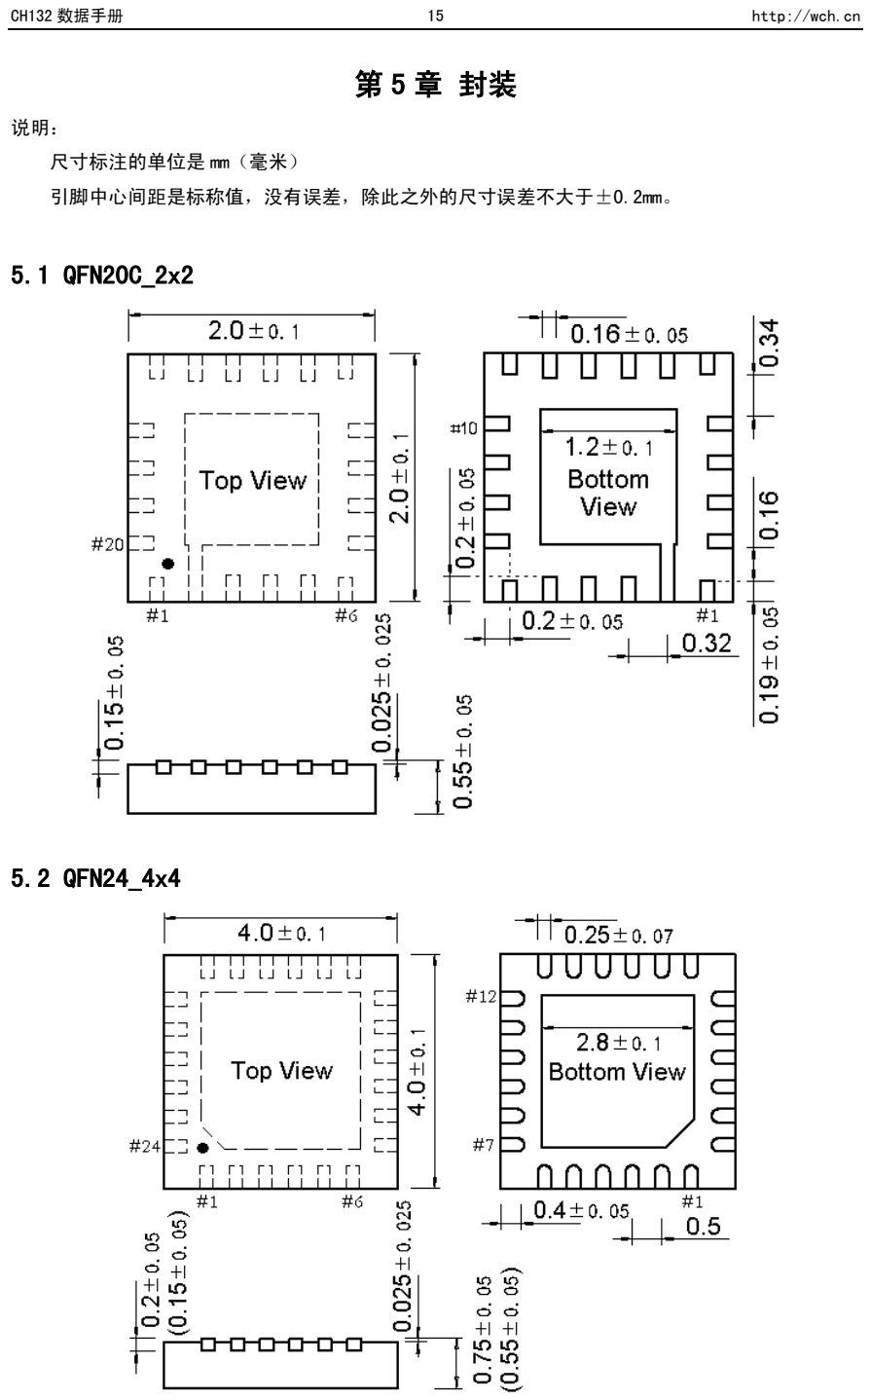
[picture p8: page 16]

CH132 数据手册 | 15 | http://wch.cn

说明：

尺寸标注的单位是 mm（毫米）

引脚中心间距是标称值，没有误差，除此之外的尺寸误差不大于±0.2mm。

## 5.2 QFN24_4x4

CH132 数据手册 | 16 | http://wch.cn

## 5.3 QFN32_5x5

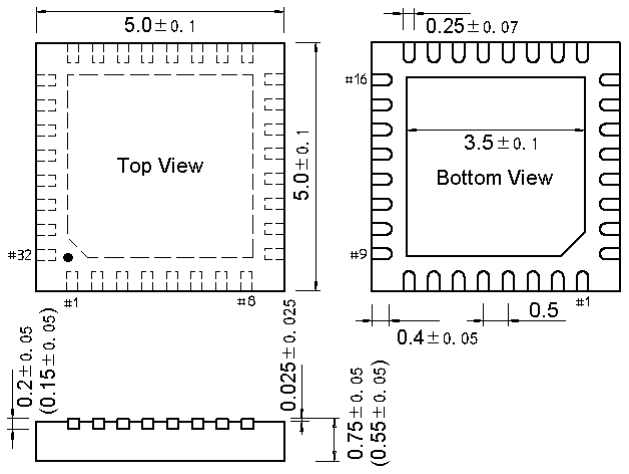
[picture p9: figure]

## 第 6 章 应用

## 6.1 最小系统

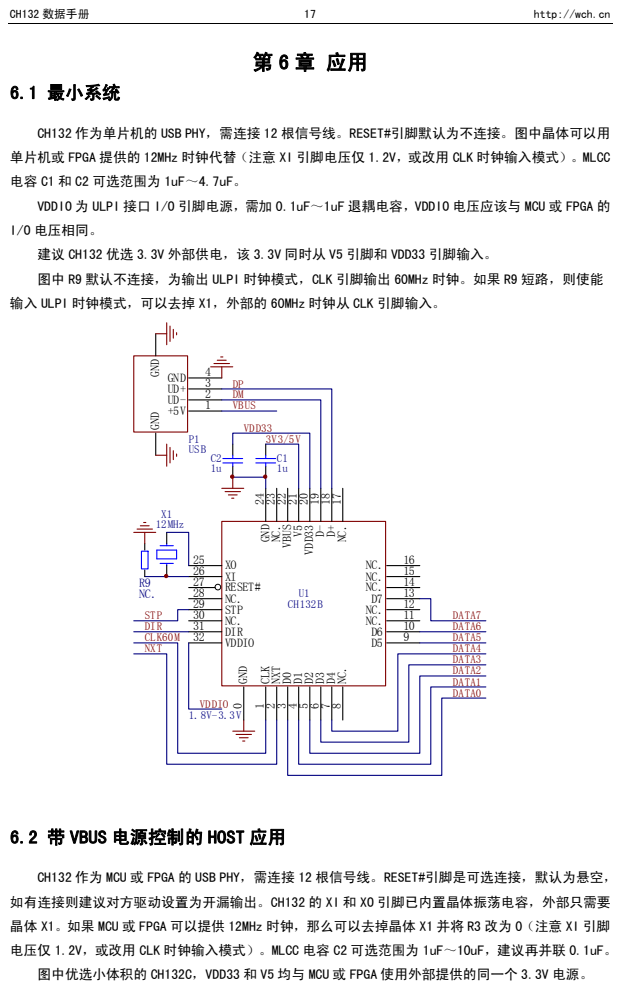
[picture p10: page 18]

CH132 作为单片机的 USB PHY，需连接 12 根信号线。RESET#引脚默认为不连接。图中晶体可以用
单片机或 FPGA 提供的 12MHz 时钟代替（注意 XI 引脚电压仅 1.2V，或改用 CLK 时钟输入模式）。MLCC
电容 C1 和 C2 可选范围为 1uF～4.7uF。
VDDIO 为 ULPI 接口 I/O 引脚电源，需加 0.1uF～1uF 退耦电容，VDDIO 电压应该与 MCU 或 FPGA 的
I/O 电压相同。
建议 CH132 优选 3.3V 外部供电，该 3.3V 同时从 V5 引脚和 VDD33 引脚输入。
图中 R9 默认不连接，为输出 ULPI 时钟模式，CLK 引脚输出 60MHz 时钟。如果 R9 短路，则使能
输入 ULPI 时钟模式，可以去掉 X1，外部的 60MHz 时钟从 CLK 引脚输入。

6.2 带 VBUS 电源控制的 HOST 应用

CH132 作为 MCU 或 FPGA 的 USB PHY，需连接 12 根信号线。RESET#引脚是可选连接，默认为悬空，
如有连接则建议对方驱动设置为开漏输出。CH132 的 XI 和 XO 引脚已内置晶体振荡电容，外部只需要
晶体 X1。如果 MCU 或 FPGA 可以提供 12MHz 时钟，那么可以去掉晶体 X1 并将 R3 改为 0（注意 XI 引脚
电压仅 1.2V，或改用 CLK 时钟输入模式）。MLCC 电容 C2 可选范围为 1uF～10uF，建议再并联 0.1uF。
图中优选小体积的 CH132C，VDD33 和 V5 均与 MCU 或 FPGA 使用外部提供的同一个 3.3V 电源。

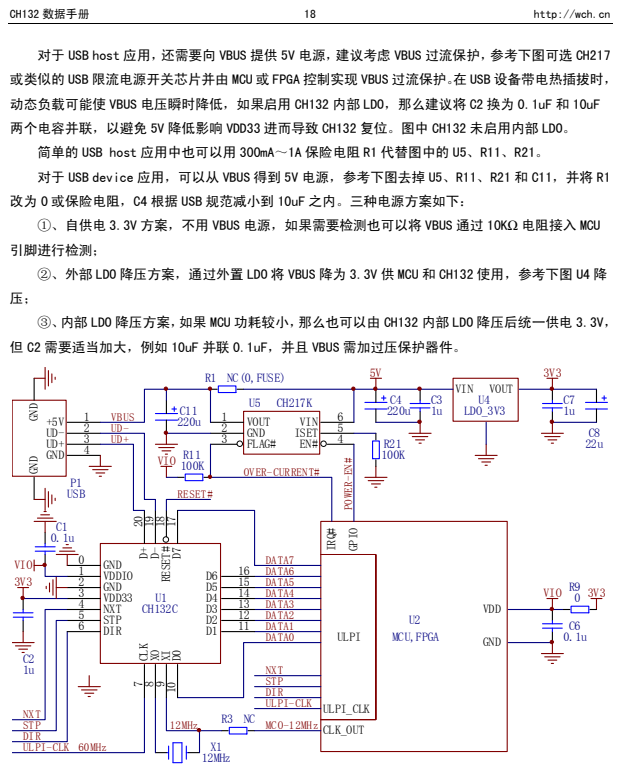
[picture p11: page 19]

对于 USB host 应用，还需要向 VBUS 提供 5V 电源，建议考虑 VBUS 过流保护，参考下图可选 CH217
或类似的 USB 限流电源开关芯片并由 MCU 或 FPGA 控制实现 VBUS 过流保护。在 USB 设备带电热插拔时，
动态负载可能使 VBUS 电压瞬时降低，如果启用 CH132 内部 LDO，那么建议将 C2 换为 0.1uF 和 10uF
两个电容并联，以避免 5V 降低影响 VDD33 进而导致 CH132 复位。图中 CH132 未启用内部 LDO。
简单的 USB host 应用中也可以用 300mA～1A 保险电阻 R1 代替图中的 U5、R11、R21。
对于 USB device 应用，可以从 VBUS 得到 5V 电源，参考下图去掉 U5、R11、R21 和 C11，并将 R1
改为 0 或保险电阻，C4 根据 USB 规范减小到 10uF 之内。三种电源方案如下：
①、自供电 3.3V 方案，不用 VBUS 电源，如果需要检测也可以将 VBUS 通过 10KΩ 电阻接入 MCU
引脚进行检测；
②、外部 LDO 降压方案，通过外置 LDO 将 VBUS 降为 3.3V 供 MCU 和 CH132 使用，参考下图 U4 降
③、内部 LDO 降压方案，如果 MCU 功耗较小，那么也可以由 CH132 内部 LDO 降压后统一供电 3.3V，
但 C2 需要适当加大，例如 10uF 并联 0.1uF，并且 VBUS 需加过压保护器件。

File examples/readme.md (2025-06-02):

# 例程目录

## 一、ataradov.usb_sniffer
* 状态：未测试
* 简介：实现USB2.0 480M逻辑分析仪
* 来源：[usb-sniffer](https://github.com/ataradov/usb-sniffer)
* 版权：`BSD-3-Clause license`
* 移植者：`Vllogic`
* 硬件版本：无要求
* 硬件变动：需焊好排母，并顶对顶接上`EZ-USB CY7C68013A`板

## 二、ultraembedded.core_usb_cdc
* 状态：未测试
* 简介：实现USB2.0 480M CDC设备，通过`USB3343`芯片
* 来源：[core_usb_cdc](https://github.com/ultraembedded/core_usb_cdc)
* 版权：`LGPL-2.1 license`
* 移植者：`Vllogic`
* 硬件版本：无要求
* 硬件变动：无

## 三、udp_over_rgmii
* 状态：未测试
* 简介：基于千兆以太网的UDP测试
* 来源：`TODO`
* 版权：`TODO`
* 移植者：`Vllogic`
* 硬件版本：无要求
* 硬件变动：无

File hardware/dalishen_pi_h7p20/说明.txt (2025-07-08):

1. 由于JTAG口在LQFP128封装上无法作为IO使用，故移除SE0，J, K状态电路

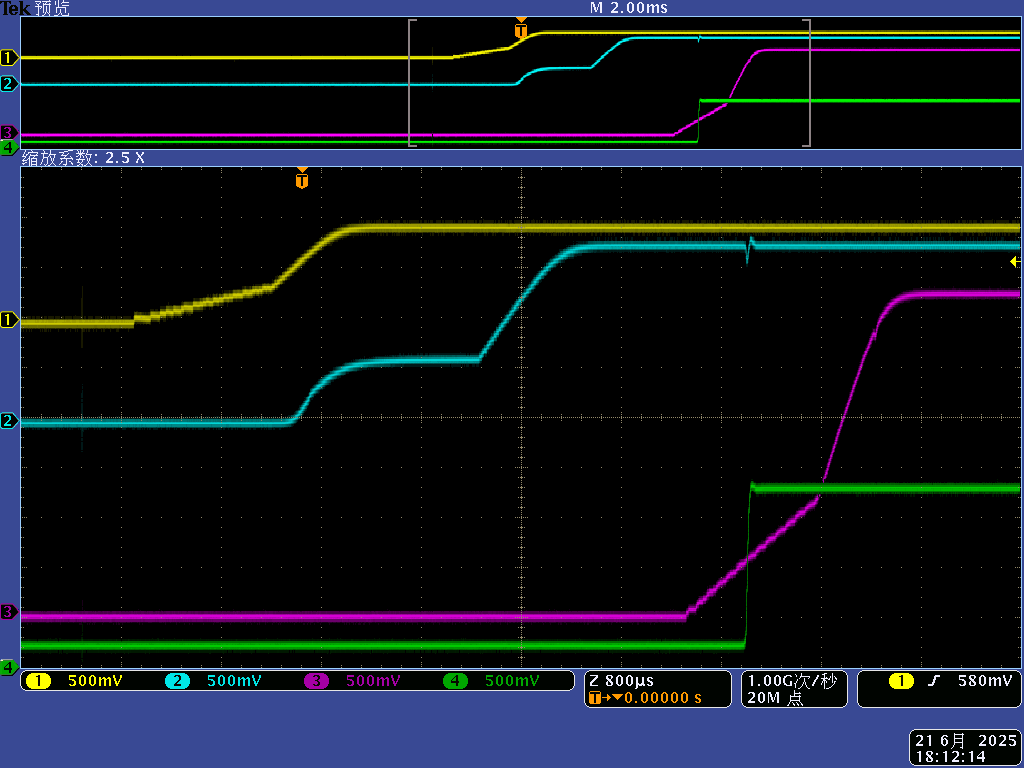
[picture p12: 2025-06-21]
hardware/usb_sniffer_h7p20/上电时序.png

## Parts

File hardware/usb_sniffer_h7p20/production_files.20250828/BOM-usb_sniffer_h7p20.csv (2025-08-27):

Comment | Designator | Footprint | LCSC | Quantity
Trigger | J6 | PinHeader_1x02_P2.54mm_Vertical |  | 1
0.1uF | C50 | C_0402_1005Metric |  | 1
5.1k,1% | R13 | R_0402_1005Metric |  | 1
33k,1% | R38 | R_0402_1005Metric |  | 1
4.7k,1% | R9 | R_0402_1005Metric |  | 1
0.1uF | C53 | C_0402_1005Metric |  | 1
0.1uF | C18 | C_0402_1005Metric |  | 1
10uF | C25 | C_0402_1005Metric |  | 1
20k,1% | R35 | R_0402_1005Metric |  | 1
0.1uF | C41 | C_0402_1005Metric |  | 1
USB_C_Receptacle_USB2.0_16P | J4 | USB_C_Receptacle_16P |  | 1
TestPoint | TP15 | PinHeader_1x01_P1.00mm_Vertical |  | 1
GSV332-MR | U2 | MSOP-8_3x3mm_P0.65mm |  | 1
1uF | C38 | C_0402_1005Metric |  | 1
TestPoint | TP16 | TestPoint_Pad_D0.3mm |  | 1
LED_ABGR | D3 | LED_RGB_Everlight_EASV3015RGBA0_Horizontal |  | 1
0.1uF | C51 | C_0402_1005Metric |  | 1
4.7k | R17 | R_0402_1005Metric |  | 1
150k,1% | R32 | R_0402_1005Metric |  | 1
0.1uF | C52 | C_0402_1005Metric |  | 1
NC | C54 | C_0402_1005Metric |  | 1
CY7C68013A-56LTX | U7 | QFN-56-1EP_8x8mm_P0.5mm_EP4.5x5.2mm |  | 1
TestPoint | TP21 | TestPoint_Pad_D0.3mm |  | 1
0.1uF | C61 | C_0402_1005Metric |  | 1
8.06k,1% | R30 | R_0402_1005Metric |  | 1
TestPoint | TP18 | TestPoint_Pad_D0.3mm |  | 1
0.1uF | C60 | C_0402_1005Metric |  | 1
1uF | C36 | C_0402_1005Metric |  | 1
24M | Y2 | OSC_3225 |  | 1
10k,1% | R12 | R_0402_1005Metric |  | 1
10uF | C13 | C_0402_1005Metric |  | 1
20k,1% | R40 | R_0402_1005Metric |  | 1
24C32 | U8 | SOP-8_3.9x4.9mm_P1.27mm |  | 1
4.7uH,MPL2012S4R7MHT | L3 | L_0805_2012Metric |  | 1
H7P20N0L128-M3H1 | U1 | LQFP-128_14x14mm_P0.4mm_pad |  | 1
20k,1% | R37 | R_0402_1005Metric |  | 1
10uF | C37 | C_0402_1005Metric |  | 1
220pF | C23 | C_0402_1005Metric |  | 1
0.1uF | C59 | C_0402_1005Metric |  | 1
0.1uF | C43 | C_0402_1005Metric |  | 1
0.1uF | C3 | C_0402_1005Metric |  | 1
33k,1% | R33 | R_0402_1005Metric |  | 1
USB_C_Receptacle_USB2.0_16P | J2 | USB_C_Receptacle_16P |  | 1
CJ3439KDW | U9 | SOT-363_SC-70-6 |  | 1
10k,1% | R5 | R_0402_1005Metric |  | 1
4.7k | R23 | R_0402_1005Metric |  | 1
TestPoint | TP17 | TestPoint_Pad_D0.3mm |  | 1
0.1uF | C14 | C_0402_1005Metric |  | 1
USB_A | J3 | USB-AF_YIJIAN |  | 1
0.1uF | C58 | C_0402_1005Metric |  | 1
10uF | C27 | C_0402_1005Metric |  | 1
10uF | C12 | C_0402_1005Metric |  | 1
10uF | C22 | C_0402_1005Metric |  | 1
1uF | C6 | C_0402_1005Metric |  | 1
4.7k,1% | R8 | R_0402_1005Metric |  | 1
0.1uF | C28 | C_0402_1005Metric |  | 1
10uF | C20 | C_0402_1005Metric |  | 1
0.1uF | C15 | C_0402_1005Metric |  | 1
TestPoint | TP20 | TestPoint_Pad_D0.3mm |  | 1
1uF | C9 | C_0402_1005Metric |  | 1
GSV332-MR | U3 | MSOP-8_3x3mm_P0.65mm |  | 1
0.1uF | C49 | C_0402_1005Metric |  | 1
1uF | C26 | C_0402_1005Metric |  | 1
4.7k | R16 | R_0402_1005Metric |  | 1
0.1uF | C34 | C_0402_1005Metric |  | 1
1uF | C10 | C_0402_1005Metric |  | 1
0.1uF | C47 | C_0402_1005Metric |  | 1
0.1uF | C46 | C_0402_1005Metric |  | 1
P25Q64SH-SSH-IR | U6 | SOP-8_3.9x4.9mm_P1.27mm |  | 1
0.1uF | C42 | C_0402_1005Metric |  | 1
10uF | C24 | C_0402_1005Metric |  | 1
SMD0805B100TFT | F1 | Fuse_0805_2012Metric |  | 1
TestPoint | TP2 | PinHeader_1x01_P1.00mm_Vertical |  | 1
5.1k,1% | R26 | R_0402_1005Metric |  | 1
NC | C56 | C_0402_1005Metric |  | 1
10uF | C39 | C_0402_1005Metric |  | 1
CESD5V0D5 | D1 | D_SOD-523 |  | 1
33k,1% | R39 | R_0402_1005Metric |  | 1
0.1uF | C44 | C_0402_1005Metric |  | 1
1.5uH | L5 | L_NR2520xx |  | 1
10k,1% | R6 | R_0402_1005Metric |  | 1
0.1uF | C8 | C_0402_1005Metric |  | 1
5.1k,1% | R3 | R_0402_1005Metric |  | 1
0.1uF | C55 | C_0402_1005Metric |  | 1
10uF | C17 | C_0402_1005Metric |  | 1
10k,1% | R20 | R_0402_1005Metric |  | 1
TestPoint | TP4 | PinHeader_1x01_P1.00mm_Vertical |  | 1
5.1k,1% | R25 | R_0402_1005Metric |  | 1
4.7uH,MPL2012S4R7MHT | L2 | L_0805_2012Metric |  | 1
5.1k,1% | R4 | R_0402_1005Metric |  | 1
220pF | C21 | C_0402_1005Metric |  | 1
FPGA_JTAG | J1 | PinHeader_1x05_P2.54mm_Vertical |  | 1
4.7k | R22 | R_0402_1005Metric |  | 1
0.1uF | C45 | C_0402_1005Metric |  | 1
10k,1% | R28 | R_0402_1005Metric |  | 1
1uF | C2 | C_0402_1005Metric |  | 1
470 | R7 | R_0402_1005Metric |  | 1
USB3343 | U5 | QFN-24-1EP_4x4mm_P0.5mm_EP2.6x2.6mm |  | 1
0.1uF | C33 | C_0402_1005Metric |  | 1
EA3036C | U11 | QFN-20-1EP_3x3mm_P0.4mm_EP1.65x1.65mm |  | 1
5.1k,1% | R18 | R_0402_1005Metric |  | 1
TestPoint | TP14 | PinHeader_1x01_P1.00mm_Vertical |  | 1
12pF | C31 | C_0402_1005Metric |  | 1
10uF | C62 | C_0402_1005Metric |  | 1
TestPoint | TP1 | PinHeader_1x01_P1.00mm_Vertical |  | 1
TestPoint | TP5 | TestPoint_Pad_D0.3mm |  | 1
0.1uF | C29 | C_0402_1005Metric |  | 1
0.1uF | C16 | C_0402_1005Metric |  | 1
10k,1% | R19 | R_0402_1005Metric |  | 1
0.1uF | C4 | C_0402_1005Metric |  | 1
NC | C19 | C_0402_1005Metric |  | 1
4.7k | R15 | R_0402_1005Metric |  | 1
TestPoint | TP3 | PinHeader_1x01_P1.00mm_Vertical |  | 1
1uF | C11 | C_0402_1005Metric |  | 1
0.1uF | C57 | C_0402_1005Metric |  | 1
TestPoint | TP6 | TestPoint_Pad_D0.3mm |  | 1
0.1uF | C48 | C_0402_1005Metric |  | 1
GSV332-MR | U4 | MSOP-8_3x3mm_P0.65mm |  | 1
0.1uF | C35 | C_0402_1005Metric |  | 1
10k,1% | R24 | R_0402_1005Metric |  | 1
5.1k,1% | R2 | R_0402_1005Metric |  | 1
33k,1% | R21 | R_0402_1005Metric |  | 1
12pF | C32 | C_0402_1005Metric |  | 1
220pF | C30 | C_0402_1005Metric |  | 1
10k,1% | R31 | R_0402_1005Metric |  | 1
10k,1% | R34 | R_0402_1005Metric |  | 1
TestPoint | TP7 | TestPoint_Pad_D0.75mm |  | 1
FFC-40P-0.5mm,NC | J5 | TE_4-1734839-0_1x40-1MP_P0.5mm_Horizontal |  | 1
SolderJumper_2_Bridged | JP2 | SolderJumper-2_P1.3mm_Bridged_RoundedPad1.0x1.5mm |  | 1
SolderJumper_2_Open | JP4 | SolderJumper-2_P1.3mm_Open_RoundedPad1.0x1.5mm |  | 1
TestPoint | TP12 | TestPoint_Pad_D0.75mm |  | 1
TestPoint | TP11 | TestPoint_Pad_D0.75mm |  | 1
TestPoint | TP13 | TestPoint_Pad_D0.75mm |  | 1
TestPoint | TP19 | TestPoint_Pad_D0.75mm |  | 1
TestPoint | TP9 | TestPoint_Pad_D0.75mm |  | 1
TestPoint | TP10 | TestPoint_Pad_D0.75mm |  | 1
TestPoint | TP8 | TestPoint_Pad_D0.75mm |  | 1
SolderJumper_2_Open | JP3 | SolderJumper-2_P1.3mm_Open_RoundedPad1.0x1.5mm |  | 1
0.1uF | C1 | C_0402_1005Metric |  | 1

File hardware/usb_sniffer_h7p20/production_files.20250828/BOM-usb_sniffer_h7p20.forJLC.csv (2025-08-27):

Comment | Designator | Footprint | LCSC | Quantity
Trigger | J6 | PinHeader_1x02_P2.54mm_Vertical |  | 1
0.1uF | C50 | 0402 |  | 1
5.1k,1% | R13 | 0402 |  | 1
33k,1% | R38 | 0402 |  | 1
4.7k,1% | R9 | 0402 |  | 1
0.1uF | C53 | 0402 |  | 1
0.1uF | C18 | 0402 |  | 1
10uF | C25 | 0402 |  | 1
20k,1% | R35 | 0402 |  | 1
0.1uF | C41 | 0402 |  | 1
USB_C_Receptacle_USB2.0_16P | J4 | USB_C_Receptacle_16P |  | 1
TestPoint | TP15 | PinHeader_1x01_P1.00mm_Vertical |  | 1
GSV332-MR | U2 | MSOP-8_3x3mm_P0.65mm |  | 1
1uF | C38 | 0402 |  | 1
TestPoint | TP16 | TestPoint_Pad_D0.3mm |  | 1
LED_ABGR | D3 | LED_RGB_Everlight_EASV3015RGBA0_Horizontal |  | 1
0.1uF | C51 | 0402 |  | 1
4.7k | R17 | 0402 |  | 1
150k,1% | R32 | 0402 |  | 1
0.1uF | C52 | 0402 |  | 1
NC | C54 | 0402 |  | 1
CY7C68013A-56LTX | U7 | QFN-56-1EP_8x8mm_P0.5mm_EP4.5x5.2mm |  | 1
TestPoint | TP21 | TestPoint_Pad_D0.3mm |  | 1
0.1uF | C61 | 0402 |  | 1
8.06k,1% | R30 | 0402 |  | 1
TestPoint | TP18 | TestPoint_Pad_D0.3mm |  | 1
0.1uF | C60 | 0402 |  | 1
1uF | C36 | 0402 |  | 1
24M | Y2 | OSC_3225 |  | 1
10k,1% | R12 | 0402 |  | 1
10uF | C13 | 0402 |  | 1
20k,1% | R40 | 0402 |  | 1
24C32 | U8 | SOP-8_3.9x4.9mm_P1.27mm |  | 1
4.7uH,MPL2012S4R7MHT | L3 | L_0805_2012Metric |  | 1
H7P20N0L128-M3H1 | U1 | LQFP-128_14x14mm_P0.4mm_pad |  | 1
20k,1% | R37 | 0402 |  | 1
10uF | C37 | 0402 |  | 1
220pF | C23 | 0402 |  | 1
0.1uF | C59 | 0402 |  | 1
0.1uF | C43 | 0402 |  | 1
0.1uF | C3 | 0402 |  | 1
33k,1% | R33 | 0402 |  | 1
USB_C_Receptacle_USB2.0_16P | J2 | USB_C_Receptacle_16P |  | 1
CJ3439KDW | U9 | SOT-363_SC-70-6 |  | 1
10k,1% | R5 | 0402 |  | 1
4.7k | R23 | 0402 |  | 1
TestPoint | TP17 | TestPoint_Pad_D0.3mm |  | 1
0.1uF | C14 | 0402 |  | 1
USB_A | J3 | USB-AF_YIJIAN |  | 1
0.1uF | C58 | 0402 |  | 1
10uF | C27 | 0402 |  | 1
10uF | C12 | 0402 |  | 1
10uF | C22 | 0402 |  | 1
1uF | C6 | 0402 |  | 1
4.7k,1% | R8 | 0402 |  | 1
0.1uF | C28 | 0402 |  | 1
10uF | C20 | 0402 |  | 1
0.1uF | C15 | 0402 |  | 1
TestPoint | TP20 | TestPoint_Pad_D0.3mm |  | 1
1uF | C9 | 0402 |  | 1
GSV332-MR | U3 | MSOP-8_3x3mm_P0.65mm |  | 1
0.1uF | C49 | 0402 |  | 1
1uF | C26 | 0402 |  | 1
4.7k | R16 | 0402 |  | 1
0.1uF | C34 | 0402 |  | 1
1uF | C10 | 0402 |  | 1
0.1uF | C47 | 0402 |  | 1
0.1uF | C46 | 0402 |  | 1
P25Q64SH-SSH-IR | U6 | SOP-8_3.9x4.9mm_P1.27mm |  | 1
0.1uF | C42 | 0402 |  | 1
10uF | C24 | 0402 |  | 1
SMD0805B100TFT | F1 | Fuse_0805_2012Metric |  | 1
TestPoint | TP2 | PinHeader_1x01_P1.00mm_Vertical |  | 1
5.1k,1% | R26 | 0402 |  | 1
NC | C56 | 0402 |  | 1
10uF | C39 | 0402 |  | 1
CESD5V0D5 | D1 | D_SOD-523 |  | 1
33k,1% | R39 | 0402 |  | 1
0.1uF | C44 | 0402 |  | 1
1.5uH | L5 | L_NR2520xx |  | 1
10k,1% | R6 | 0402 |  | 1
0.1uF | C8 | 0402 |  | 1
5.1k,1% | R3 | 0402 |  | 1
0.1uF | C55 | 0402 |  | 1
10uF | C17 | 0402 |  | 1
10k,1% | R20 | 0402 |  | 1
TestPoint | TP4 | PinHeader_1x01_P1.00mm_Vertical |  | 1
5.1k,1% | R25 | 0402 |  | 1
4.7uH,MPL2012S4R7MHT | L2 | L_0805_2012Metric |  | 1
5.1k,1% | R4 | 0402 |  | 1
220pF | C21 | 0402 |  | 1
FPGA_JTAG | J1 | PinHeader_1x05_P2.54mm_Vertical |  | 1
4.7k | R22 | 0402 |  | 1
0.1uF | C45 | 0402 |  | 1
10k,1% | R28 | 0402 |  | 1
1uF | C2 | 0402 |  | 1
470 | R7 | 0402 |  | 1
USB3343 | U5 | QFN-24-1EP_4x4mm_P0.5mm_EP2.6x2.6mm |  | 1
0.1uF | C33 | 0402 |  | 1
EA3036C | U11 | QFN-20-1EP_3x3mm_P0.4mm_EP1.65x1.65mm |  | 1
5.1k,1% | R18 | 0402 |  | 1
TestPoint | TP14 | PinHeader_1x01_P1.00mm_Vertical |  | 1
12pF | C31 | 0402 |  | 1
10uF | C62 | 0402 |  | 1
TestPoint | TP1 | PinHeader_1x01_P1.00mm_Vertical |  | 1
TestPoint | TP5 | TestPoint_Pad_D0.3mm |  | 1
0.1uF | C29 | 0402 |  | 1
0.1uF | C16 | 0402 |  | 1
10k,1% | R19 | 0402 |  | 1
0.1uF | C4 | 0402 |  | 1
NC | C19 | 0402 |  | 1
4.7k | R15 | 0402 |  | 1
TestPoint | TP3 | PinHeader_1x01_P1.00mm_Vertical |  | 1
1uF | C11 | 0402 |  | 1
0.1uF | C57 | 0402 |  | 1
TestPoint | TP6 | TestPoint_Pad_D0.3mm |  | 1
0.1uF | C48 | 0402 |  | 1
GSV332-MR | U4 | MSOP-8_3x3mm_P0.65mm |  | 1
0.1uF | C35 | 0402 |  | 1
10k,1% | R24 | 0402 |  | 1
5.1k,1% | R2 | 0402 |  | 1
33k,1% | R21 | 0402 |  | 1
12pF | C32 | 0402 |  | 1
220pF | C30 | 0402 |  | 1
10k,1% | R31 | 0402 |  | 1
10k,1% | R34 | 0402 |  | 1
TestPoint | TP7 | TestPoint_Pad_D0.75mm |  | 1
FFC-40P-0.5mm,NC | J5 | TE_4-1734839-0_1x40-1MP_P0.5mm_Horizontal |  | 1
SolderJumper_2_Bridged | JP2 | SolderJumper-2_P1.3mm_Bridged_RoundedPad1.0x1.5mm |  | 1
SolderJumper_2_Open | JP4 | SolderJumper-2_P1.3mm_Open_RoundedPad1.0x1.5mm |  | 1
TestPoint | TP12 | TestPoint_Pad_D0.75mm |  | 1
TestPoint | TP11 | TestPoint_Pad_D0.75mm |  | 1
TestPoint | TP13 | TestPoint_Pad_D0.75mm |  | 1
TestPoint | TP19 | TestPoint_Pad_D0.75mm |  | 1
TestPoint | TP9 | TestPoint_Pad_D0.75mm |  | 1
TestPoint | TP10 | TestPoint_Pad_D0.75mm |  | 1
TestPoint | TP8 | TestPoint_Pad_D0.75mm |  | 1
SolderJumper_2_Open | JP3 | SolderJumper-2_P1.3mm_Open_RoundedPad1.0x1.5mm |  | 1
0.1uF | C1 | 0402 |  | 1

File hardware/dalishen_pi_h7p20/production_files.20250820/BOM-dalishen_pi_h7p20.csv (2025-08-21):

Comment | Designator | Footprint | LCSC | Quantity
10uF | C30 | C_0402_1005Metric |  | 1
47k | R1003 | R_0402_1005Metric |  | 1
NC | R7 | R_0402_1005Metric |  | 1
33 | R86 | R_0402_1005Metric |  | 1
SW_DIP_x03 | SW3 | SW_DIP_SPSTx03_Slide_6.7x9.18mm_W8.61mm_P2.54mm_LowProfile |  | 1
2.49k | R16 | R_0402_1005Metric |  | 1
2.49k | R55 | R_0402_1005Metric |  | 1
0.1uF | C52 | C_0402_1005Metric |  | 1
0R | C78 | C_0402_1005Metric |  | 1
1.5uH | L4 | L_NR2520xx |  | 1
0.1uF | C10 | C_0402_1005Metric |  | 1
0.1uF | C21 | C_0402_1005Metric |  | 1
4.7k | R41 | R_0402_1005Metric |  | 1
33 | R75 | R_0402_1005Metric |  | 1
LED_GREEN | D3 | LED_0603_1608Metric |  | 1
0.1uF | C20 | C_0402_1005Metric |  | 1
NC | C79 | C_0402_1005Metric |  | 1
10k,1% | R5 | R_0402_1005Metric |  | 1
10uF | C47 | C_0402_1005Metric |  | 1
5.1k | R1002 | R_0402_1005Metric |  | 1
XC6206-2.8 | U5 | SOT-23 |  | 1
0R | L1001 | L_0402_1005Metric |  | 1
5.1k | R69 | R_0402_1005Metric |  | 1
33 | R8 | R_0402_1005Metric |  | 1
1uF | C13 | C_0402_1005Metric |  | 1
1uF | C34 | C_0402_1005Metric |  | 1
RJ45_HR911130A | J10 | RJ45_HR911130A |  | 1
33 | R9 | R_0402_1005Metric |  | 1
SW_Push | SW2 | SW-3x6mm_Hxx_SMD |  | 1
10uF | C68 | C_0402_1005Metric |  | 1
1uF | C71 | C_0402_1005Metric |  | 1
5.1k | R21 | R_0402_1005Metric |  | 1
10uH | L1 | L_NR3015 |  | 1
Conn_02x05_Odd_Even | J1 | PinHeader_2x05_P1.27mm_Vertical_SMD |  | 1
0.1uF | C6 | C_0402_1005Metric |  | 1
1uF | C73 | C_0402_1005Metric |  | 1
20k,1% | R29 | R_0402_1005Metric |  | 1
0.1uF | C64 | C_0402_1005Metric |  | 1
OV5640 | J7 | Hirose_FH12-24S-0.5SH_1x24-1MP_P0.50mm_Horizontal |  | 1
NC | X1 | OSC_3225 |  | 1
0.1uF | C11 | C_0402_1005Metric |  | 1
220pF | C28 | C_0402_1005Metric |  | 1
1uF | C50 | C_0402_1005Metric |  | 1
YT8531C | U1 | QFN-40-1EP_5x5mm_P0.4mm_EP3.6x3.6mm |  | 1
1uF | C1012 | C_0402_6mil |  | 1
1.5uH | L3 | L_NR2520xx |  | 1
0.1uF | C48 | C_0402_1005Metric |  | 1
NC | R52 | R_0402_1005Metric |  | 1
8.06k | R89 | R_0402_1005Metric |  | 1
XC6206-1.5 | U8 | SOT-23 |  | 1
2.49k | R56 | R_0402_1005Metric |  | 1
33 | R74 | R_0402_1005Metric |  | 1
4.3pF | C14 | C_0402_6mil |  | 1
5.1k | R1001 | R_0402_1005Metric |  | 1
0 | R6 | R_0402_1005Metric |  | 1
10,1% | R65 | R_0402_1005Metric |  | 1
Antenna_Shield | AE1001 | Texas_SWRA117D_2.4GHz_Left |  | 1
0.1uF | C9 | C_0402_1005Metric |  | 1
5.1k | R62 | R_0402_1005Metric |  | 1
5.1k | R54 | R_0402_1005Metric |  | 1
USB_C_Receptacle_USB2.0_16P | J2 | USB_C_Receptacle_16P |  | 1
33 | R70 | R_0402_1005Metric |  | 1
USB_C_Receptacle_USB2.0_16P | J1001 | USB_C_Receptacle_GCT_USB4105-xx-A_16P_TopMnt_Horizontal |  | 1
5.1k | R68 | R_0402_1005Metric |  | 1
10k | R80 | R_0402_1005Metric |  | 1
10uF | C4 | C_0402_1005Metric |  | 1
5.1k | R40 | R_0402_1005Metric |  | 1
1N5819(S4) | D8 | D_SOD-323_BAT60 |  | 1
10uF | C27 | C_0402_1005Metric |  | 1
4.7uH,MPL2012S4R7MHT | L2 | L_0805_2012Metric |  | 1
33k,1% | R30 | R_0402_1005Metric |  | 1
5.1k | R48 | R_0402_1005Metric |  | 1
10uF | C31 | C_0402_1005Metric |  | 1
NC | C1002 | C_0402_1005Metric |  | 1
1uF | C40 | C_0402_1005Metric |  | 1
5.1k | R43 | R_0402_1005Metric |  | 1
10uF | C37 | C_0402_1005Metric |  | 1
0.1uF | C18 | C_0402_1005Metric |  | 1
10uF | C33 | C_0402_1005Metric |  | 1
33 | R87 | R_0402_1005Metric |  | 1
Conn_02x10_Odd_Even | CY_J2 | PinSocket_2x10_P2.54mm_Vertical |  | 1
33 | R83 | R_0402_1005Metric |  | 1
1uF | C70 | C_0402_1005Metric |  | 1
5.1k | R77 | R_0402_1005Metric |  | 1
0.1uF | C66 | C_0402_1005Metric |  | 1
NC | C1011 | C_0402_6mil |  | 1
5.1k | R61 | R_0402_1005Metric |  | 1
33 | R85 | R_0402_1005Metric |  | 1
26M | Y1 | OSC_2016 |  | 1
SW_Push | SW4 | SW-3x6mm_Hxx_SMD |  | 1
1uF | C1008 | C_0402_1005Metric |  | 1
10uF | C41 | C_0402_1005Metric |  | 1
SY7201ABC | U4 | SOT-23-6 |  | 1
5.1k | R50 | R_0402_1005Metric |  | 1
0.1uF | C63 | C_0402_1005Metric |  | 1
0.1uF | C59 | C_0402_1005Metric |  | 1
5.1k | R20 | R_0402_1005Metric |  | 1
0.1uF | C42 | C_0402_1005Metric |  | 1
0.1uF | C23 | C_0402_1005Metric |  | 1
NC | Y2 | OSC_3225 |  | 1
220pF | C25 | C_0402_1005Metric |  | 1
1uF | C16 | C_0402_1005Metric |  | 1
H7P20N0L128-M3H1 | U3 | LQFP-128_14x14mm_P0.4mm_pad |  | 1
33k,1% | R36 | R_0402_1005Metric |  | 1
5.1k | R42 | R_0402_1005Metric |  | 1
5.1k | R18 | R_0402_1005Metric |  | 1
TestPoint | TP1 | PinHeader_1x01_P1.00mm_Vertical |  | 1
0.1uF | C19 | C_0402_1005Metric |  | 1
0.1uF | C43 | C_0402_1005Metric |  | 1
26M, 10PPM | Y1001 | OSC_2016 |  | 1
33 | R11 | R_0402_1005Metric |  | 1
2.49k | R38 | R_0402_1005Metric |  | 1
LED_YELLOW | D4 | LED_0603_1608Metric |  | 1
10uF | C57 | C_0402_1005Metric |  | 1
10uF | C1009 | C_0402_1005Metric |  | 1
4.3pF | C12 | C_0402_6mil |  | 1
10uF | C58 | C_0402_1005Metric |  | 1
4.3pF | C1003 | C_0402_1005Metric |  | 1
10uF | C32 | C_0402_1005Metric |  | 1
5.1k | R47 | R_0402_1005Metric |  | 1
10uF | C1005 | C_0402_1005Metric |  | 1
0R | L1003 | L_0402_1005Metric |  | 1
AIC8800FC | U1001 | QFN-36-1EP_4x4mm_P0.35mm_EP2.5x2.5mm |  | 1
220pF | C35 | C_0402_1005Metric |  | 1
0.1uF | C62 | C_0402_1005Metric |  | 1
33k,1% | R34 | R_0402_1005Metric |  | 1
33 | R71 | R_0402_1005Metric |  | 1
33 | R72 | R_0402_1005Metric |  | 1
P25Q80H/P25Q64H/P25Q128HA | U1002 | USON-8-1EP_3x2mm_P0.5mm_EP1.6x02mm |  | 1
CJ3439KDW | U9 | SOT-363_SC-70-6 |  | 1
1uF | C75 | C_0402_1005Metric |  | 1
2.49k | R39 | R_0402_1005Metric |  | 1
10k,1% | R79 | R_0402_1005Metric |  | 1
0.1uF | C7 | C_0402_1005Metric |  | 1
10uF | C1010 | C_0402_6mil |  | 1
1.5uH | L5 | L_NR2520xx |  | 1
10,1% | R64 | R_0402_1005Metric |  | 1
4.7uH,MPL2012S4R7MHT | L1004 | L_0805_2012Metric |  | 1
5.1k | R49 | R_0402_1005Metric |  | 1
20k,1% | R35 | R_0402_1005Metric |  | 1
1uF | C46 | C_0402_1005Metric |  | 1
0.1uF | C45 | C_0402_1005Metric |  | 1
USB_A | J3 | USB-AF_YIJIAN |  | 1
2.49k | R57 | R_0402_1005Metric |  | 1
0.1uF | C53 | C_0402_1005Metric |  | 1
0.1uF | C15 | C_0402_1005Metric |  | 1
USB3343 | U20 | QFN-24-1EP_4x4mm_P0.5mm_EP2.6x2.6mm |  | 1
0.1uF | C17 | C_0402_1005Metric |  | 1
10k,1% | R15 | R_0402_1005Metric |  | 1
5.1k | R76 | R_0402_1005Metric |  | 1
10uF | C24 | C_0402_1005Metric |  | 1
0.1uF | C5 | C_0402_1005Metric |  | 1
1uF,50V | C69 | C_0603_1608Metric |  | 1
10uF | C26 | C_0402_1005Metric |  | 1
10k,1% | R44 | R_0402_1005Metric |  | 1
10k,1% | R90 | R_0402_1005Metric |  | 1
10k | R63 | R_0402_1005Metric |  | 1
SW_Push | SW1 | SW-3x6mm_Hxx_SMD |  | 1
P25Q64SH-SSH-IR | U7 | SOIC-8_P1.27mm_Common |  | 1
10uF | C44 | C_0402_1005Metric |  | 1
Conn_02x10_Odd_Even | CY_J1 | PinSocket_2x10_P2.54mm_Vertical |  | 1
1uF | C39 | C_0402_1005Metric |  | 1
TestPoint | TP2 | PinHeader_1x01_P1.00mm_Vertical |  | 1
1uF | C49 | C_0402_1005Metric |  | 1
1uF | C77 | C_0402_1005Metric |  | 1
NC | R53 | R_0402_1005Metric |  | 1
0.1uF | C55 | C_0402_1005Metric |  | 1
5.1k | R22 | R_0402_1005Metric |  | 1
0.1uF | C8 | C_0402_1005Metric |  | 1
10uF | C38 | C_0402_1005Metric |  | 1
1uF | C76 | C_0402_1005Metric |  | 1
1uF | C1007 | C_0402_1005Metric |  | 1
4.3pF | C1006 | C_0402_1005Metric |  | 1
20k,1% | R31 | R_0402_1005Metric |  | 1
0.1uF | C60 | C_0402_1005Metric |  | 1
0.1uF | C22 | C_0402_1005Metric |  | 1
NC | R51 | R_0402_1005Metric |  | 1
0.1uF | C61 | C_0402_1005Metric |  | 1
1uF | C72 | C_0402_1005Metric |  | 1
33 | R91 | R_0402_1005Metric |  | 1
0.1uF | C54 | C_0402_1005Metric |  | 1
150k,1% | R33 | R_0402_1005Metric |  | 1
5V | J6 | PinSocket_1x01_P2.54mm_Vertical |  | 1
1M | R78 | R_0402_1005Metric |  | 1
D500C930SV0 | J9 | Hirose_FH12-40S-0.5SH_1x40-1MP_P0.50mm_Horizontal |  | 1
0.1uF | C65 | C_0402_1005Metric |  | 1
0.1uF | C67 | C_0402_1005Metric |  | 1
NC | 2x5_2.54.1001 | IDC-Header_2x05_P2.54mm_Vertical |  | 1
5.1k | R46 | R_0402_1005Metric |  | 1
SW_Push | SW5 | SW-3x6mm_Hxx_SMD |  | 1
33 | R84 | R_0402_1005Metric |  | 1
33 | R73 | R_0402_1005Metric |  | 1
0 | R4 | R_0402_1005Metric |  | 1
10uF | C29 | C_0402_1005Metric |  | 1
LED_RED | D1 | LED_0603_1608Metric |  | 1
10k | R81 | R_0402_1005Metric |  | 1
2.49k | R45 | R_0402_1005Metric |  | 1
0.1uF | C56 | C_0402_1005Metric |  | 1
1uF | C1013 | C_0402_6mil |  | 1
NC | C2 | C_0402_1005Metric |  | 1
EA3036C | U6 | QFN-20-1EP_3x3mm_P0.4mm_EP1.65x1.65mm |  | 1
0.1uF | C51 | C_0402_1005Metric |  | 1
10k | R82 | R_0402_1005Metric |  | 1
0.1uF | C74 | C_0402_1005Metric |  | 1
10k,1% | R32 | R_0402_1005Metric |  | 1
10uF | C36 | C_0402_1005Metric |  | 1
LED_BLUE | D2 | LED_0603_1608Metric |  | 1
10k,1% | R19 | R_0402_1005Metric |  | 1
SolderJumper_2_Bridged | JP2 | SolderJumper-2_P1.3mm_Bridged2Bar_RoundedPad1.0x1.5mm |  | 1
SolderJumper_2_Bridged | JP6 | SolderJumper-2_P1.3mm_Bridged_RoundedPad1.0x1.5mm |  | 1
SolderJumper_2_Bridged | JP4 | SolderJumper-2_P1.3mm_Bridged_RoundedPad1.0x1.5mm |  | 1
SolderJumper_2_Bridged | JP7 | SolderJumper-2_P1.3mm_Bridged_RoundedPad1.0x1.5mm |  | 1
TestPoint | TP1005 | TestPoint_Pad_D0.75mm |  | 1
TestPoint | TP1006 | TestPoint_Pad_D0.75mm |  | 1
TestPoint | TP1001 | TestPoint_Pad_D0.75mm |  | 1
SolderJumper_2_Bridged | JP5 | SolderJumper-2_P1.3mm_Bridged_RoundedPad1.0x1.5mm |  | 1
TestPoint | TP1007 | TestPoint_Pad_D0.75mm |  | 1
SolderJumper_2_Bridged | JP3 | SolderJumper-2_P1.3mm_Bridged_RoundedPad1.0x1.5mm |  | 1
SolderJumper_2_Bridged | JP8 | SolderJumper-2_P1.3mm_Bridged_RoundedPad1.0x1.5mm |  | 1
SolderJumper_2_Bridged | JP9 | SolderJumper-2_P1.3mm_Bridged_RoundedPad1.0x1.5mm |  | 1
TestPoint | TP1003 | TestPoint_Pad_D0.75mm |  | 1
TestPoint | TP1002 | TestPoint_Pad_D0.75mm |  | 1
TestPoint | TP1004 | TestPoint_Pad_D0.75mm |  | 1

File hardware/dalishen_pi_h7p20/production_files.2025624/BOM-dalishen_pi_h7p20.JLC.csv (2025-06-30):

Comment | Designator | Footprint | LCSC | Quantity
10uF | C30 | 0402 |  | 1
47k | R1003 | 0402 |  | 1
NC | R7 | 0402 |  | 1
33 | R86 | 0402 |  | 1
SW_DIP_x03 | SW3 | SW_DIP_SPSTx03_Slide_6.7x9.18mm_W8.61mm_P2.54mm_LowProfile |  | 1
2.49k | R16 | 0402 |  | 1
2.49k | R55 | 0402 |  | 1
0.1uF | C52 | 0402 |  | 1
NC | C78 | 0402 |  | 1
1.5uH | L4 | L_NR3015 |  | 1
0.1uF | C10 | 0402 |  | 1
0.1uF | C21 | 0402 |  | 1
4.7k | R41 | 0402 |  | 1
33 | R75 | 0402 |  | 1
LED_GREEN | D3 | LED_0603_1608Metric |  | 1
0.1uF | C20 | 0402 |  | 1
NC | C79 | 0402 |  | 1
10k,1% | R5 | 0402 |  | 1
10uF | C47 | 0402 |  | 1
5.1k | R1002 | 0402 |  | 1
XC6206-2.8 | U5 | SOT-23 |  | 1
0R | L1001 | L_0402_1005Metric |  | 1
5.1k | R69 | 0402 |  | 1
33 | R8 | 0402 |  | 1
1uF | C13 | 0402 |  | 1
1uF | C34 | 0402 |  | 1
RJ45_HR911130A | J10 | RJ45_HR911130A |  | 1
10k,1% | R1 | 0402 |  | 1
33 | R9 | 0402 |  | 1
SW_Push | SW2 | SW-3x6mm_Hxx_SMD |  | 1
10uF | C68 | 0402 |  | 1
1uF | C71 | 0402 |  | 1
5.1k | R21 | 0402 |  | 1
10uH | L1 | L_NR3015 |  | 1
Conn_02x05_Odd_Even | J1 | PinHeader_2x05_P1.27mm_Vertical_SMD |  | 1
0.1uF | C6 | 0402 |  | 1
1uF | C73 | 0402 |  | 1
20k,1% | R29 | 0402 |  | 1
0.1uF | C64 | 0402 |  | 1
OV5640 | J7 | Hirose_FH12-24S-0.5SH_1x24-1MP_P0.50mm_Horizontal |  | 1
NC | X1 | OSC_3225 |  | 1
0.1uF | C11 | 0402 |  | 1
220pF | C28 | 0402 |  | 1
1uF | C50 | 0402 |  | 1
YT8531C | U1 | QFN-40-1EP_5x5mm_P0.4mm_EP3.6x3.6mm |  | 1
1uF | C1012 | 0402 |  | 1
1.5uH | L3 | L_NR3015 |  | 1
0.1uF | C48 | 0402 |  | 1
NC | R52 | 0402 |  | 1
8.06k | R89 | 0402 |  | 1
XC6206-1.5 | U8 | SOT-23 |  | 1
2.49k | R56 | 0402 |  | 1
33 | R74 | 0402 |  | 1
4.3pF | C14 | 0402 |  | 1
5.1k | R1001 | 0402 |  | 1
0 | R6 | 0402 |  | 1
4.7k | R3 | 0402 |  | 1
10,1% | R65 | 0402 |  | 1
Antenna_Shield | AE1001 | Texas_SWRA117D_2.4GHz_Left |  | 1
0.1uF | C9 | 0402 |  | 1
5.1k | R62 | 0402 |  | 1
33k | R2 | 0402 |  | 1
5.1k | R54 | 0402 |  | 1
USB_C_Receptacle_USB2.0_16P | J2 | USB_C_Receptacle_16P |  | 1
33 | R70 | 0402 |  | 1
USB_C_Receptacle_USB2.0_16P | J1001 | USB_C_Receptacle_GCT_USB4105-xx-A_16P_TopMnt_Horizontal |  | 1
5.1k | R68 | 0402 |  | 1
10k | R80 | 0402 |  | 1
10uF | C4 | 0402 |  | 1
5.1k | R40 | 0402 |  | 1
1N5819(S4) | D8 | D_SOD-323_BAT60 |  | 1
10uF | C27 | 0402 |  | 1
0.1uF | C1 | 0402 |  | 1
33k,1% | R30 | 0402 |  | 1
5.1k | R48 | 0402 |  | 1
10uF | C31 | 0402 |  | 1
NC | C1002 | 0402 |  | 1
1uF | C40 | 0402 |  | 1
5.1k | R43 | 0402 |  | 1
10uF | C37 | 0402 |  | 1
0.1uF | C18 | 0402 |  | 1
2.49k | R24 | 0402 |  | 1
10uF | C33 | 0402 |  | 1
33 | R87 | 0402 |  | 1
Conn_02x10_Odd_Even | CY_J2 | PinSocket_2x10_P2.54mm_Vertical |  | 1
33 | R83 | 0402 |  | 1
1uF | C70 | 0402 |  | 1
5.1k | R77 | 0402 |  | 1
0.1uF | C66 | 0402 |  | 1
NC | C1011 | 0402 |  | 1
5.1k | R61 | 0402 |  | 1
33 | R85 | 0402 |  | 1
26M | Y1 | OSC_2016 |  | 1
SW_Push | SW4 | SW-3x6mm_Hxx_SMD |  | 1
1uF | C1008 | 0402 |  | 1
10uF | C41 | 0402 |  | 1
SY7201ABC | U4 | SOT-23-6 |  | 1
5.1k | R50 | 0402 |  | 1
0.1uF | C63 | 0402 |  | 1
0.1uF | C59 | 0402 |  | 1
5.1k | R20 | 0402 |  | 1
0.1uF | C42 | 0402 |  | 1
0.1uF | C23 | 0402 |  | 1
NC | Y2 | OSC_3225 |  | 1
220pF | C25 | 0402 |  | 1
1uF | C16 | 0402 |  | 1
H7P20N0L128-M3H1 | U3 | LQFP-128_14x14mm_P0.4mm_pad |  | 1
33k,1% | R36 | 0402 |  | 1
5.1k | R42 | 0402 |  | 1
5.1k | R18 | 0402 |  | 1
TestPoint | TP1 | PinHeader_1x01_P1.00mm_Vertical |  | 1
0.1uF | C19 | 0402 |  | 1
0.1uF | C43 | 0402 |  | 1
26M, 10PPM | Y1001 | OSC_2016 |  | 1
33 | R11 | 0402 |  | 1
2.49k | R38 | 0402 |  | 1
LED_YELLOW | D4 | LED_0603_1608Metric |  | 1
10uF | C57 | 0402 |  | 1
10uF | C1009 | 0402 |  | 1
4.3pF | C12 | 0402 |  | 1
10uF | C58 | 0402 |  | 1
4.3pF | C1003 | 0402 |  | 1
10uF | C32 | 0402 |  | 1
5.1k | R47 | 0402 |  | 1
10uF | C1005 | 0402 |  | 1
0R | L1003 | L_0402_1005Metric |  | 1
AIC8800FC | U1001 | QFN-36-1EP_4x4mm_P0.35mm_EP2.5x2.5mm |  | 1
220pF | C35 | 0402 |  | 1
0.1uF | C62 | 0402 |  | 1
33k,1% | R34 | 0402 |  | 1
33 | R71 | 0402 |  | 1
33 | R72 | 0402 |  | 1
P25Q80H/P25Q64H/P25Q128HA | U1002 | USON-8-1EP_3x2mm_P0.5mm_EP1.6x02mm |  | 1
2.49k | R23 | 0402 |  | 1
CJ3439KDW | U9 | SOT-363_SC-70-6 |  | 1
1uF | C75 | 0402 |  | 1
2.49k | R39 | 0402 |  | 1
10k,1% | R79 | 0402 |  | 1
0.1uF | C7 | 0402 |  | 1
10uF | C1010 | 0402 |  | 1
1.5uH | L5 | L_NR3015 |  | 1
10,1% | R64 | 0402 |  | 1
4.7uH,MPL2012S4R7MHT | L1004 | L_0805_2012Metric |  | 1
5.1k | R49 | 0402 |  | 1
20k,1% | R35 | 0402 |  | 1
1uF | C46 | 0402 |  | 1
0.1uF | C45 | 0402 |  | 1
USB_A | J3 | USB-AF_YIJIAN |  | 1
2.49k | R57 | 0402 |  | 1
0.1uF | C53 | 0402 |  | 1
0.1uF | C15 | 0402 |  | 1
USB3343 | U20 | QFN-24-1EP_4x4mm_P0.5mm_EP2.6x2.6mm |  | 1
0.1uF | C17 | 0402 |  | 1
LM2903A-VR | U18 | MSOP-8_3x3mm_P0.65mm |  | 1
10k,1% | R15 | 0402 |  | 1
5.1k | R76 | 0402 |  | 1
10uF | C24 | 0402 |  | 1
0.1uF | C5 | 0402 |  | 1
1uF,50V | C69 | 0603 |  | 1
10uF | C26 | 0402 |  | 1
LM2903A-VR | U2 | MSOP-8_3x3mm_P0.65mm |  | 1
10k,1% | R44 | 0402 |  | 1
10k,1% | R90 | 0402 |  | 1
10k | R63 | 0402 |  | 1
SW_Push | SW1 | SW-3x6mm_Hxx_SMD |  | 1
P25Q64SH-SSH-IR | U7 | SOIC-8_P1.27mm_Common |  | 1
10uF | C44 | 0402 |  | 1
Conn_02x10_Odd_Even | CY_J1 | PinSocket_2x10_P2.54mm_Vertical |  | 1
1uF | C39 | 0402 |  | 1
TestPoint | TP2 | PinHeader_1x01_P1.00mm_Vertical |  | 1
1uF | C49 | 0402 |  | 1
1uF | C77 | 0402 |  | 1
NC | R53 | 0402 |  | 1
0.1uF | C55 | 0402 |  | 1
5.1k | R22 | 0402 |  | 1
0.1uF | C8 | 0402 |  | 1
2.49k | R27 | 0402 |  | 1
10uF | C38 | 0402 |  | 1
4.7k | R10 | 0402 |  | 1
1uF | C76 | 0402 |  | 1
1uF | C1007 | 0402 |  | 1
4.3pF | C1006 | 0402 |  | 1
20k,1% | R31 | 0402 |  | 1
0.1uF | C60 | 0402 |  | 1
0.1uF | C22 | 0402 |  | 1
NC | R51 | 0402 |  | 1
0.1uF | C61 | 0402 |  | 1
1uF | C72 | 0402 |  | 1
33 | R91 | 0402 |  | 1
0.1uF | C54 | 0402 |  | 1
2.49k | R25 | 0402 |  | 1
150k,1% | R33 | 0402 |  | 1
5V | J6 | PinHeader_1x01_P2.54mm_Horizontal |  | 1
1M | R78 | 0402 |  | 1
D500C930SV0 | J9 | Hirose_FH12-40S-0.5SH_1x40-1MP_P0.50mm_Horizontal |  | 1
0.1uF | C65 | 0402 |  | 1
0.1uF | C67 | 0402 |  | 1
2.49k | R28 | 0402 |  | 1
NC | 2x5_2.54.1001 | IDC-Header_2x05_P2.54mm_Vertical |  | 1
5.1k | R46 | 0402 |  | 1
SW_Push | SW5 | SW-3x6mm_Hxx_SMD |  | 1
33 | R84 | 0402 |  | 1
LM2903A-VR | U19 | MSOP-8_3x3mm_P0.65mm |  | 1
33 | R73 | 0402 |  | 1
0 | R4 | 0402 |  | 1
10uF | C29 | 0402 |  | 1
LED_RED | D1 | LED_0603_1608Metric |  | 1
10k | R81 | 0402 |  | 1
2.49k | R26 | 0402 |  | 1
2.49k | R45 | 0402 |  | 1
0.1uF | C56 | 0402 |  | 1
1uF | C1013 | 0402 |  | 1
NC | C2 | 0402 |  | 1
EA3036C | U6 | QFN-20-1EP_3x3mm_P0.4mm_EP1.65x1.65mm |  | 1
0.1uF | C51 | 0402 |  | 1
10k | R82 | 0402 |  | 1
0.1uF | C74 | 0402 |  | 1
10k,1% | R32 | 0402 |  | 1
10uF | C36 | 0402 |  | 1
LED_BLUE | D2 | LED_0603_1608Metric |  | 1
10k,1% | R19 | 0402 |  | 1
SolderJumper_2_Bridged | JP2 | SolderJumper-2_P1.3mm_Bridged2Bar_RoundedPad1.0x1.5mm |  | 1
SolderJumper_2_Bridged | JP6 | SolderJumper-2_P1.3mm_Bridged_RoundedPad1.0x1.5mm |  | 1
SolderJumper_2_Open | JP10 | SolderJumper-2_P1.3mm_Open_RoundedPad1.0x1.5mm |  | 1
SolderJumper_2_Bridged | JP4 | SolderJumper-2_P1.3mm_Bridged_RoundedPad1.0x1.5mm |  | 1
TestPoint | TP1005 | TestPoint_Pad_D0.75mm |  | 1
TestPoint | TP1006 | TestPoint_Pad_D0.75mm |  | 1
TestPoint | TP1001 | TestPoint_Pad_D0.75mm |  | 1
SolderJumper_2_Bridged | JP5 | SolderJumper-2_P1.3mm_Bridged_RoundedPad1.0x1.5mm |  | 1
TestPoint | TP1007 | TestPoint_Pad_D0.75mm |  | 1
SolderJumper_2_Bridged | JP3 | SolderJumper-2_P1.3mm_Bridged_RoundedPad1.0x1.5mm |  | 1
SolderJumper_2_Bridged | JP9 | SolderJumper-2_P1.3mm_Bridged_RoundedPad1.0x1.5mm |  | 1
TestPoint | TP1003 | TestPoint_Pad_D0.75mm |  | 1
SolderJumper_2_Open | JP1 | SolderJumper-2_P1.3mm_Open_RoundedPad1.0x1.5mm |  | 1
TestPoint | TP1002 | TestPoint_Pad_D0.75mm |  | 1
TestPoint | TP1004 | TestPoint_Pad_D0.75mm |  | 1

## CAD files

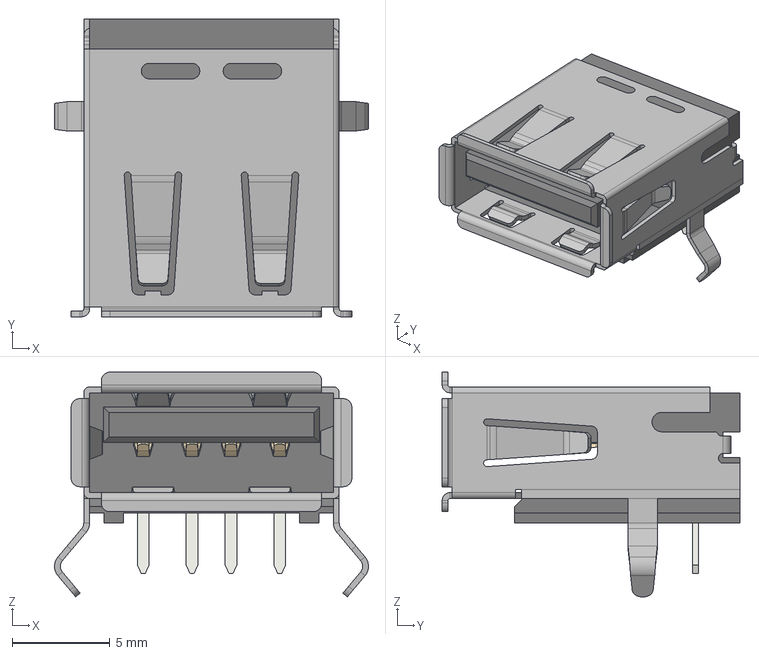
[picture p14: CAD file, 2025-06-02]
hardware/usb_sniffer_2/USB_A_Molex_67643_Horizontal.step
16.1 x 15.3 x 11.5 mm

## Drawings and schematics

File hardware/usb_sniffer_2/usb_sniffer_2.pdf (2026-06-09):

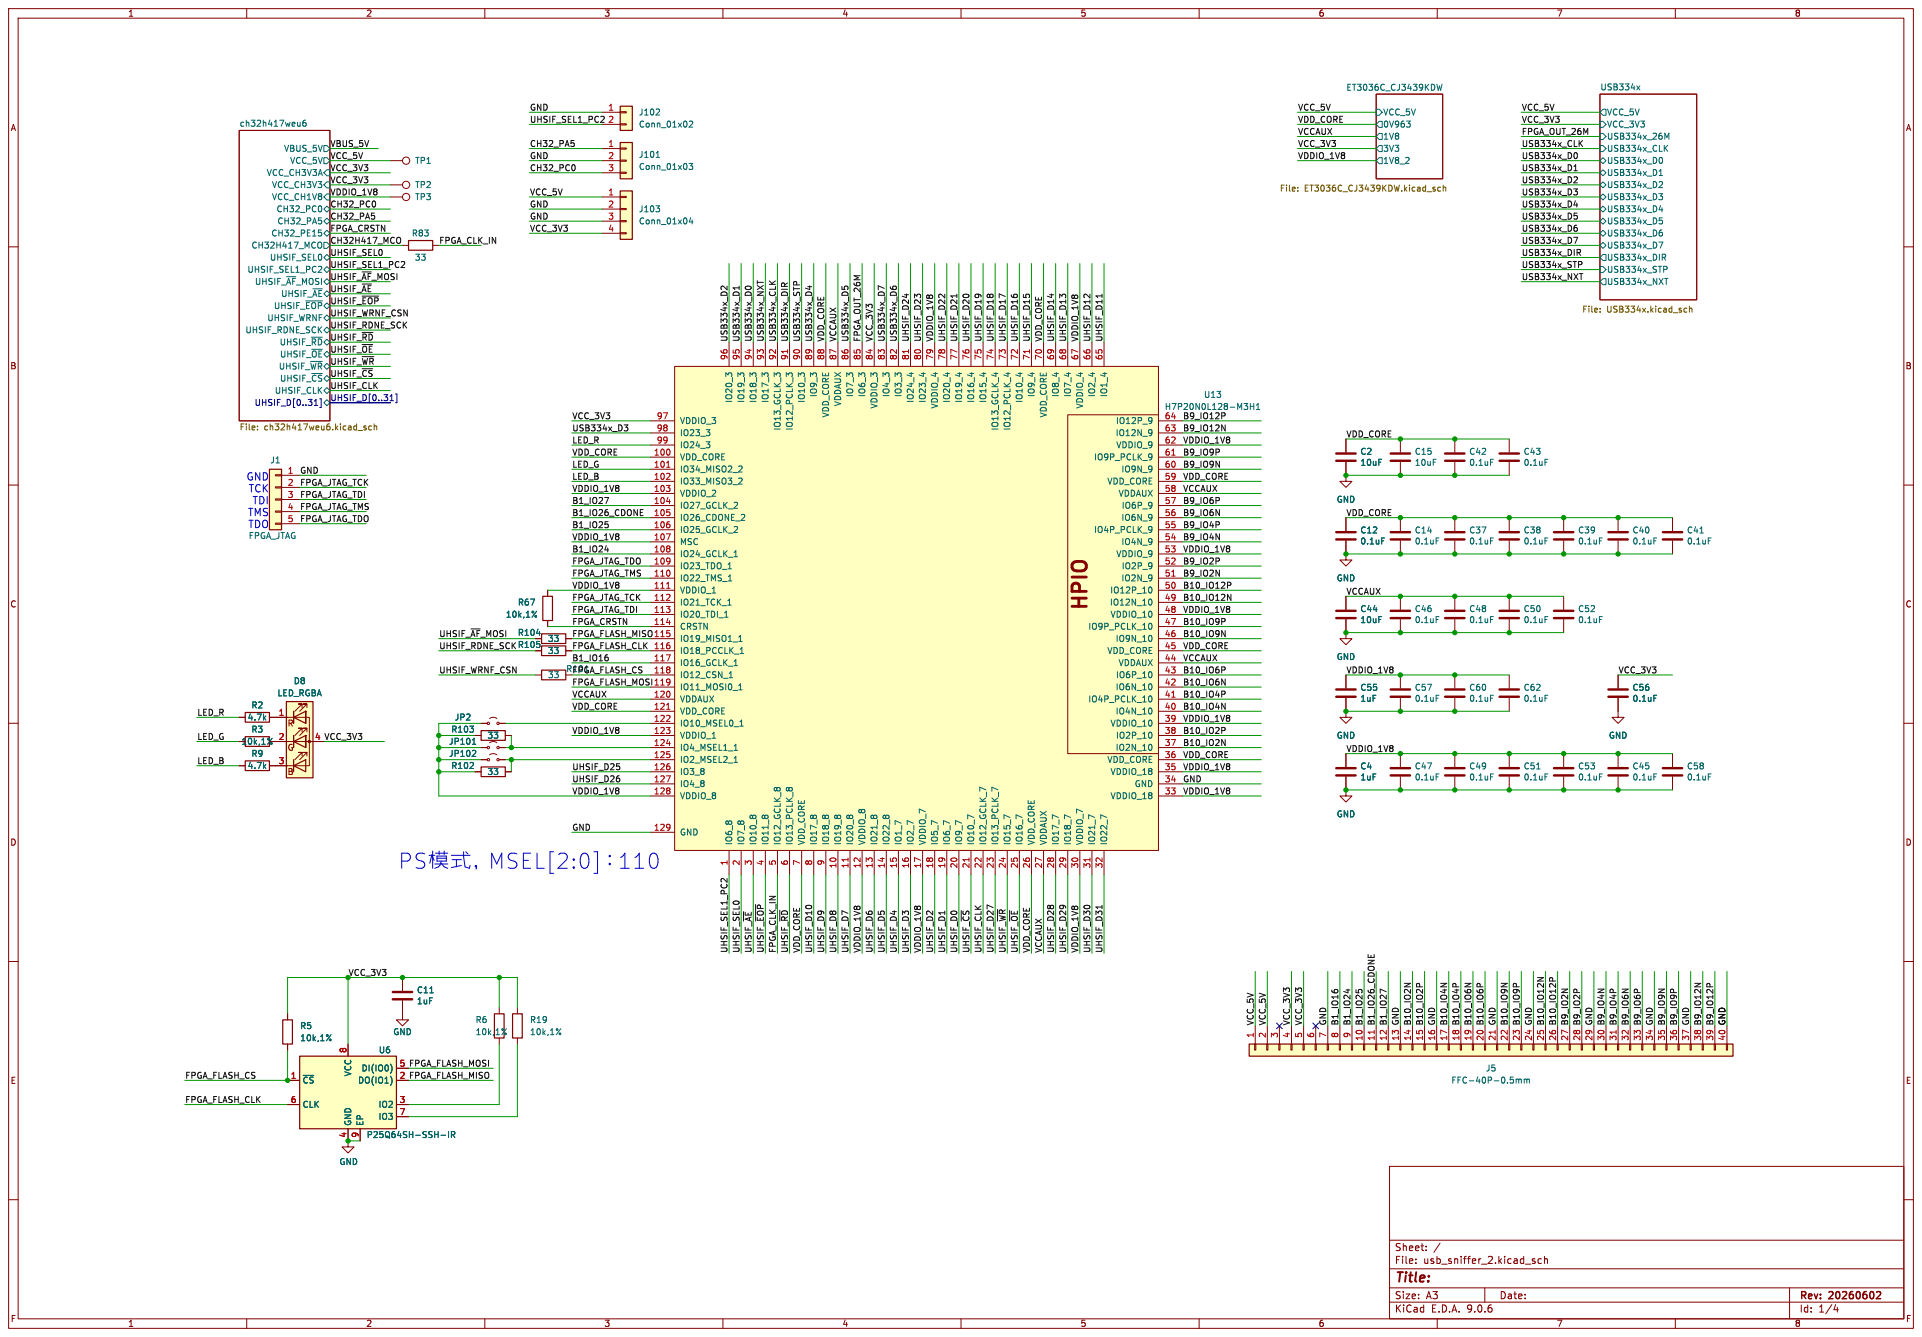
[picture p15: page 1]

Id: 1/4 Title: File: usb_sniffer_2.kicad_sch Sheet: /

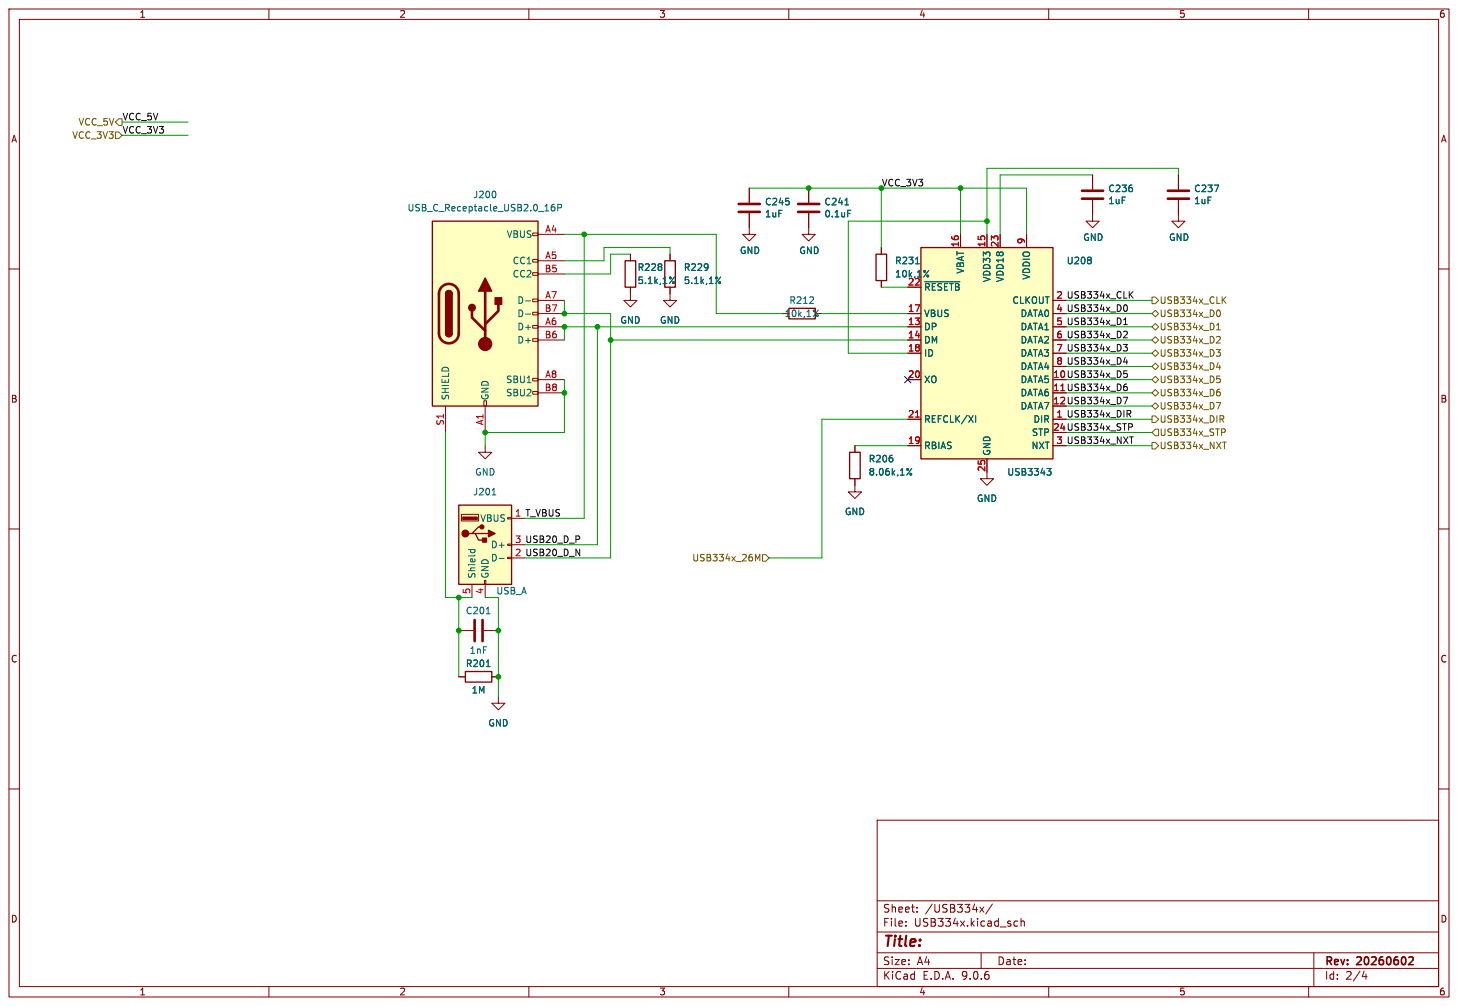
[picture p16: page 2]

9 CLKOUT 2 DATA0 4 DATA1 5 DATA2 6 DATA3 7 DATA4 8 DATA5 10 DATA6 11 DATA7 12 DIR 1 STP 24 NXT 3 GND

9 CLKOUT 2 DATA0 4 DATA1 5 DATA2 6 DATA3 7 DATA4 8 DATA5 10 DATA6 11 DATA7 12 DIR 1 STP 24 NXT 3 U208 USB3343 GND

Id: 2/4 Title: File: USB334x.kicad_sch Sheet: /USB334x/

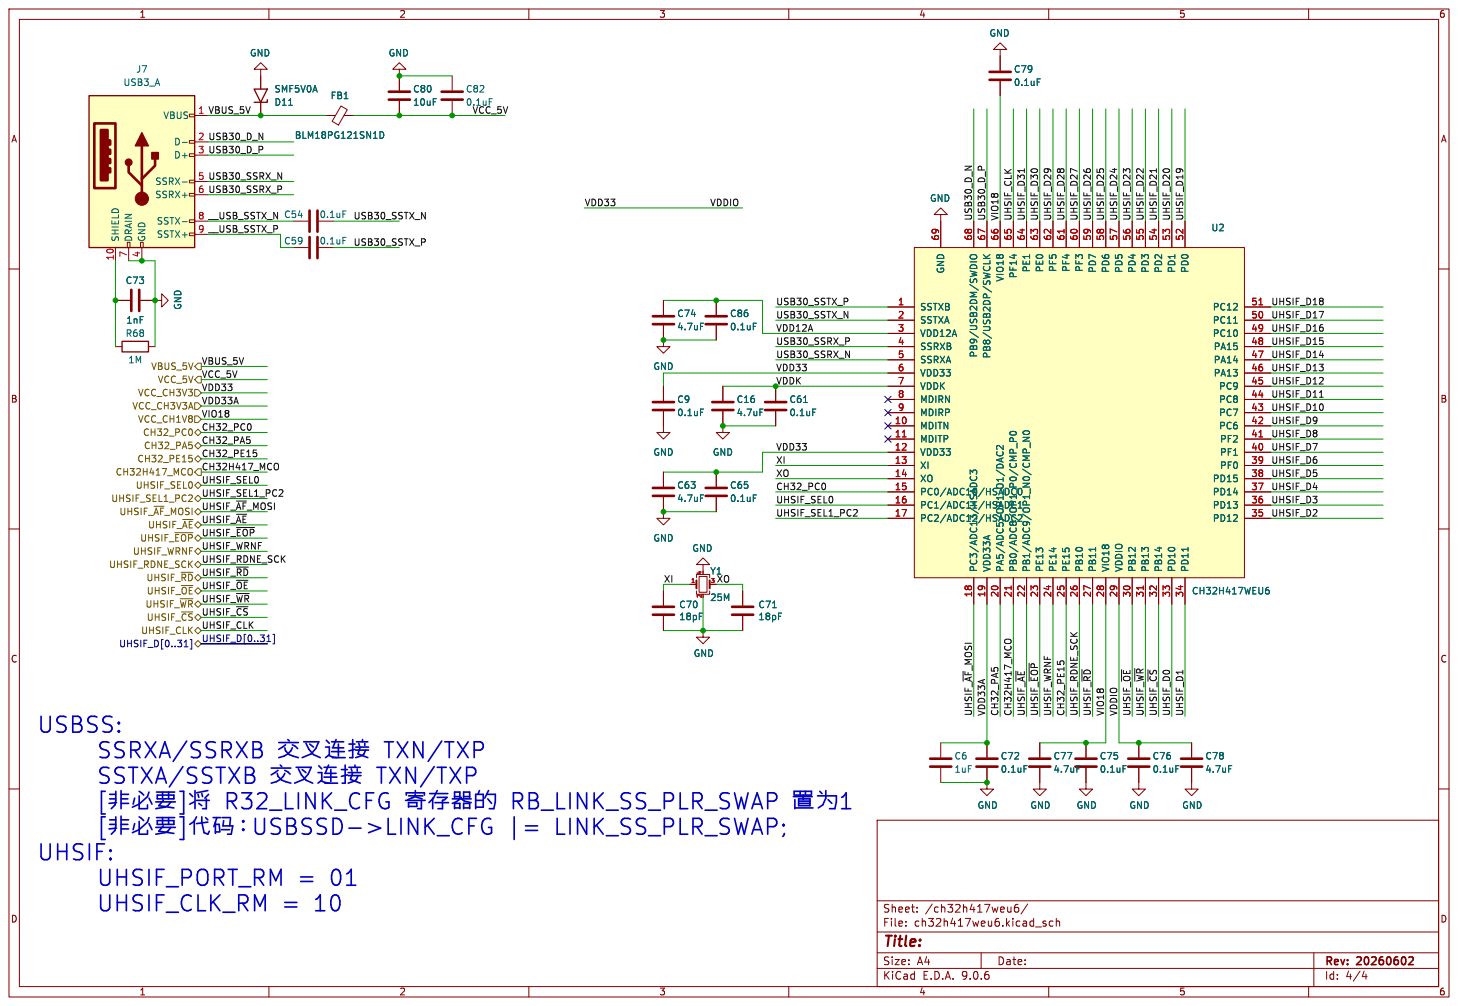
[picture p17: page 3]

4 VBUS 1 D- 2 D+ 3 SSRX- 5 SSRX+ 6 SSTX- 8 SSTX+ 9

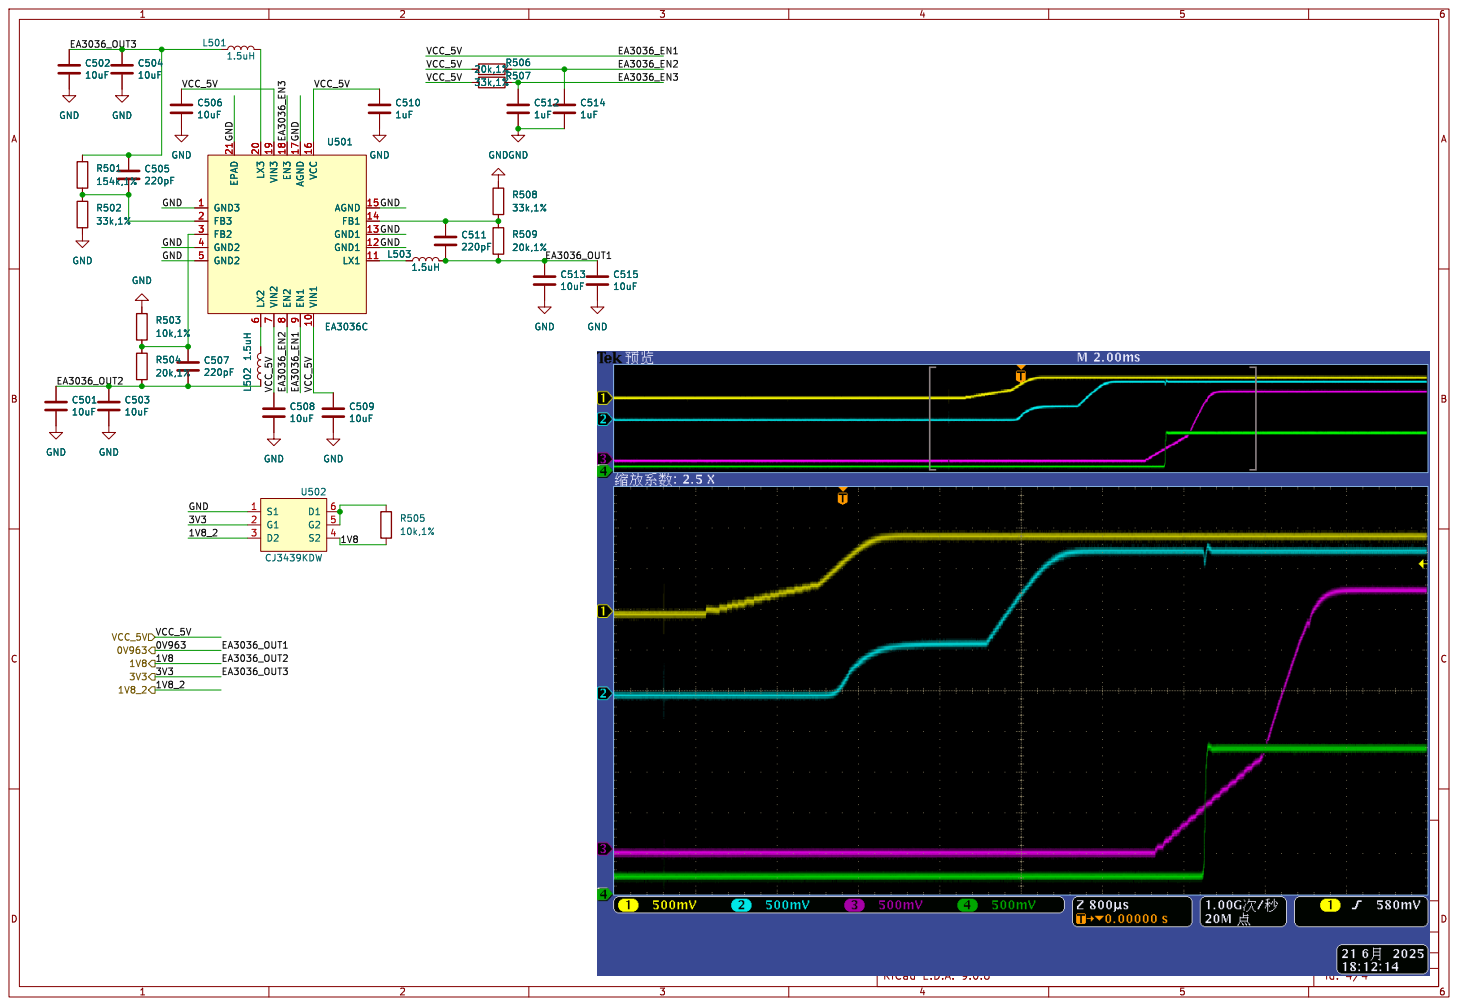
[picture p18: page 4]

Id: 4/4 Title: File: ET3036C_CJ3439KDW.kicad_sch Sheet: /ET3036C_CJ3439KDW/ L502 1.5uH

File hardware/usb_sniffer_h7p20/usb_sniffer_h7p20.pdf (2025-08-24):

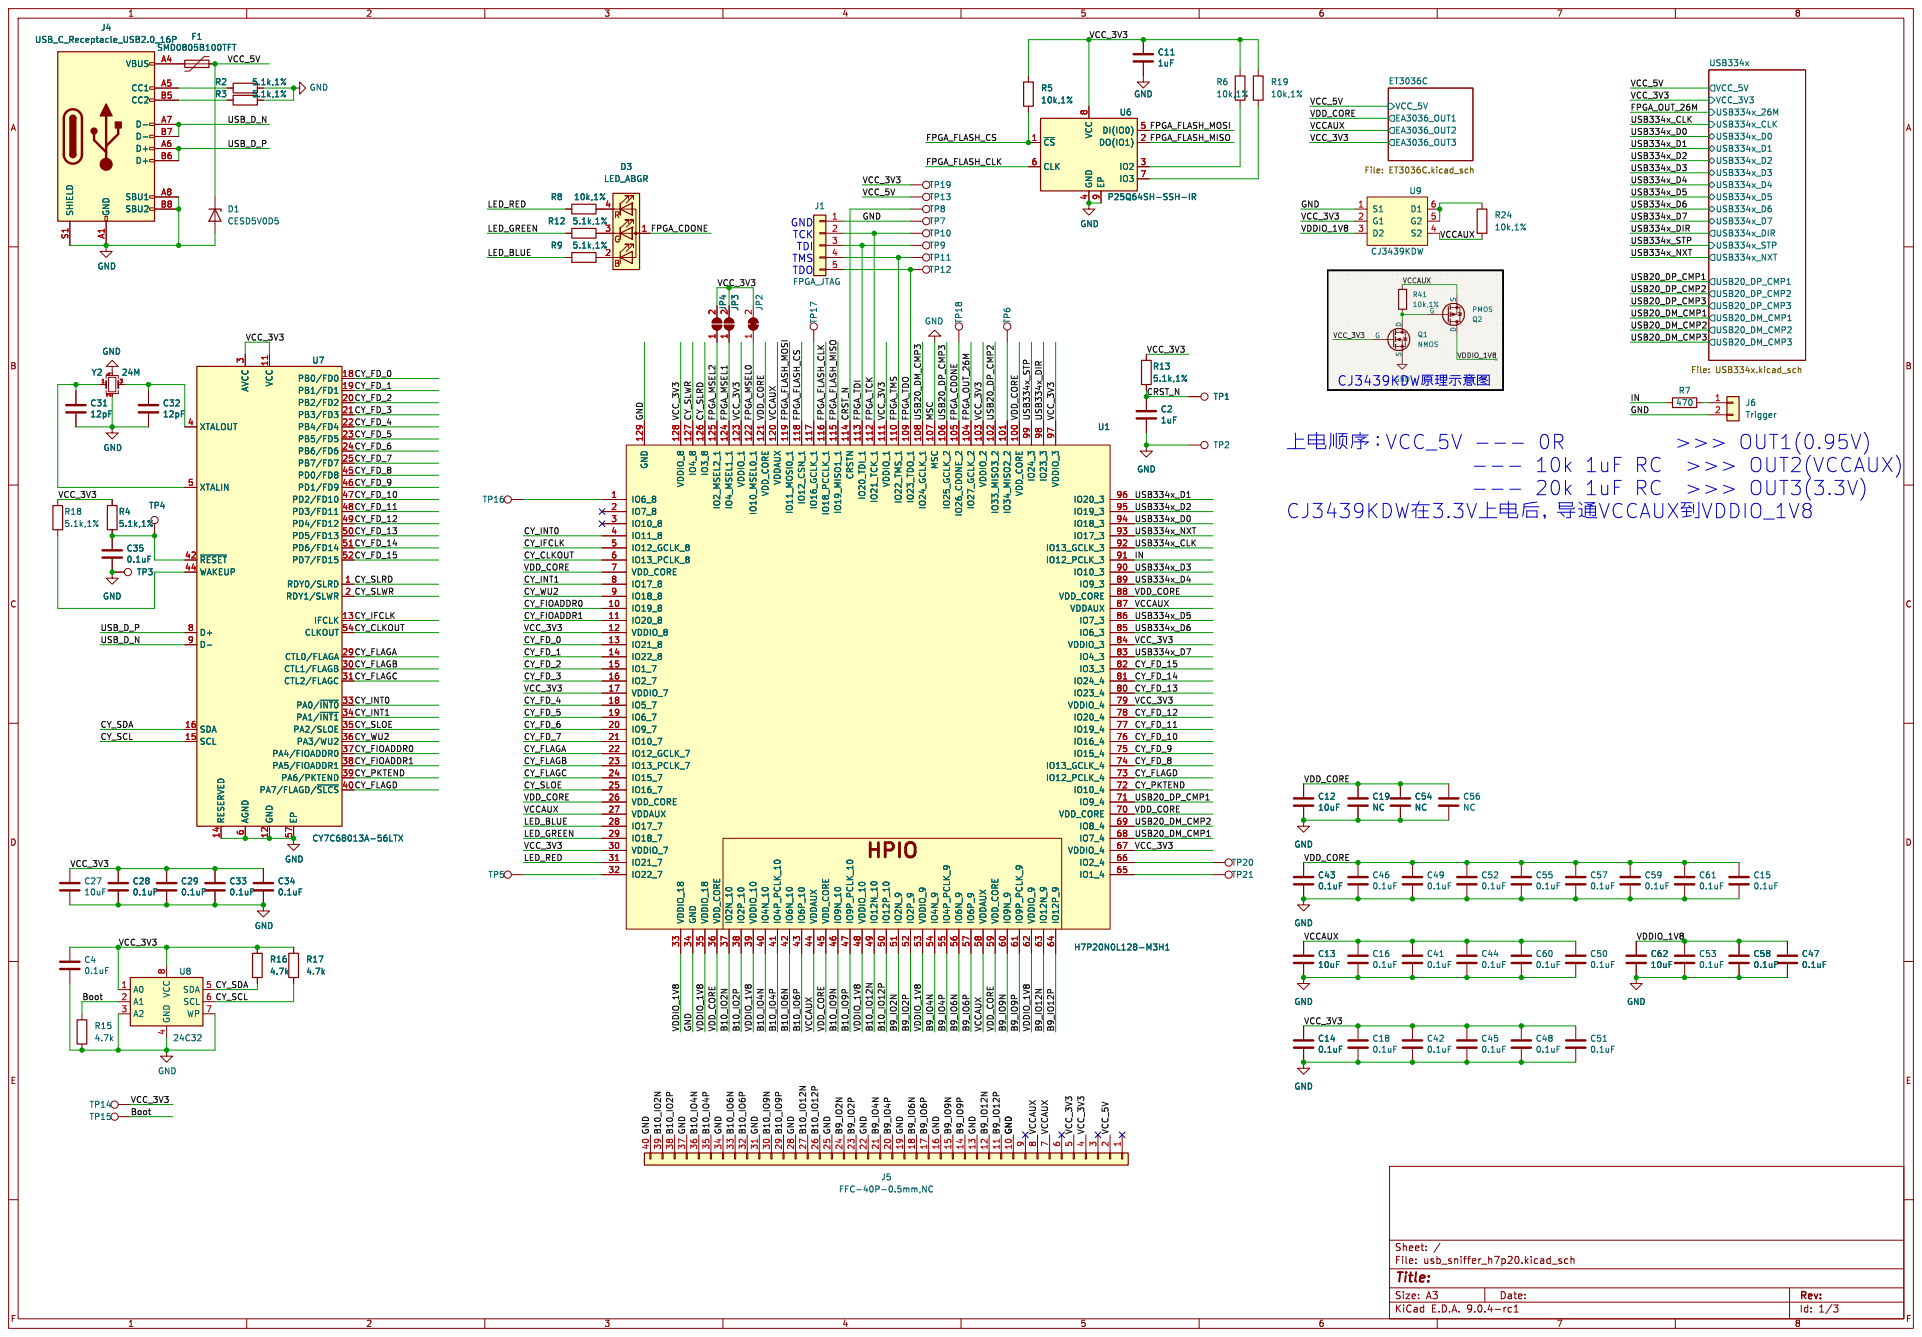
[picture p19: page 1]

6 VCC 11 GND 12 EP 57 PB0/FD0 18 PB1/FD1 19 PB2/FD2 20 PB3/FD3 21 PB4/FD4 22 PB5/FD5 23 PB6/FD6 24 PB7/FD7 25 PD0/FD8 45 PD1/FD9 46 PD2/FD10 47 PD3/FD11 48 PD4/FD12 49 PD5/FD13 50 PD6/FD14 51 PD7/FD15 52 RDY0/SLRD 1 RDY1/SLWR 2

IFCLK 13 CLKOUT 54 CTL0/FLAGA 29 CTL1/FLAGB 30 CTL2/FLAGC 31 PA0/~{INT0}33 PA1/~{INT1}34 PA2/SLOE 35 PA3/WU2 36 PA4/FIOADDR0 37 PA5/FIOADDR1 38 PA6/PKTEND 39 PA7/FLAGD/~{SLCS} 40

Id: 1/3 Title: File: usb_sniffer_h7p20.kicad_sch Sheet: /

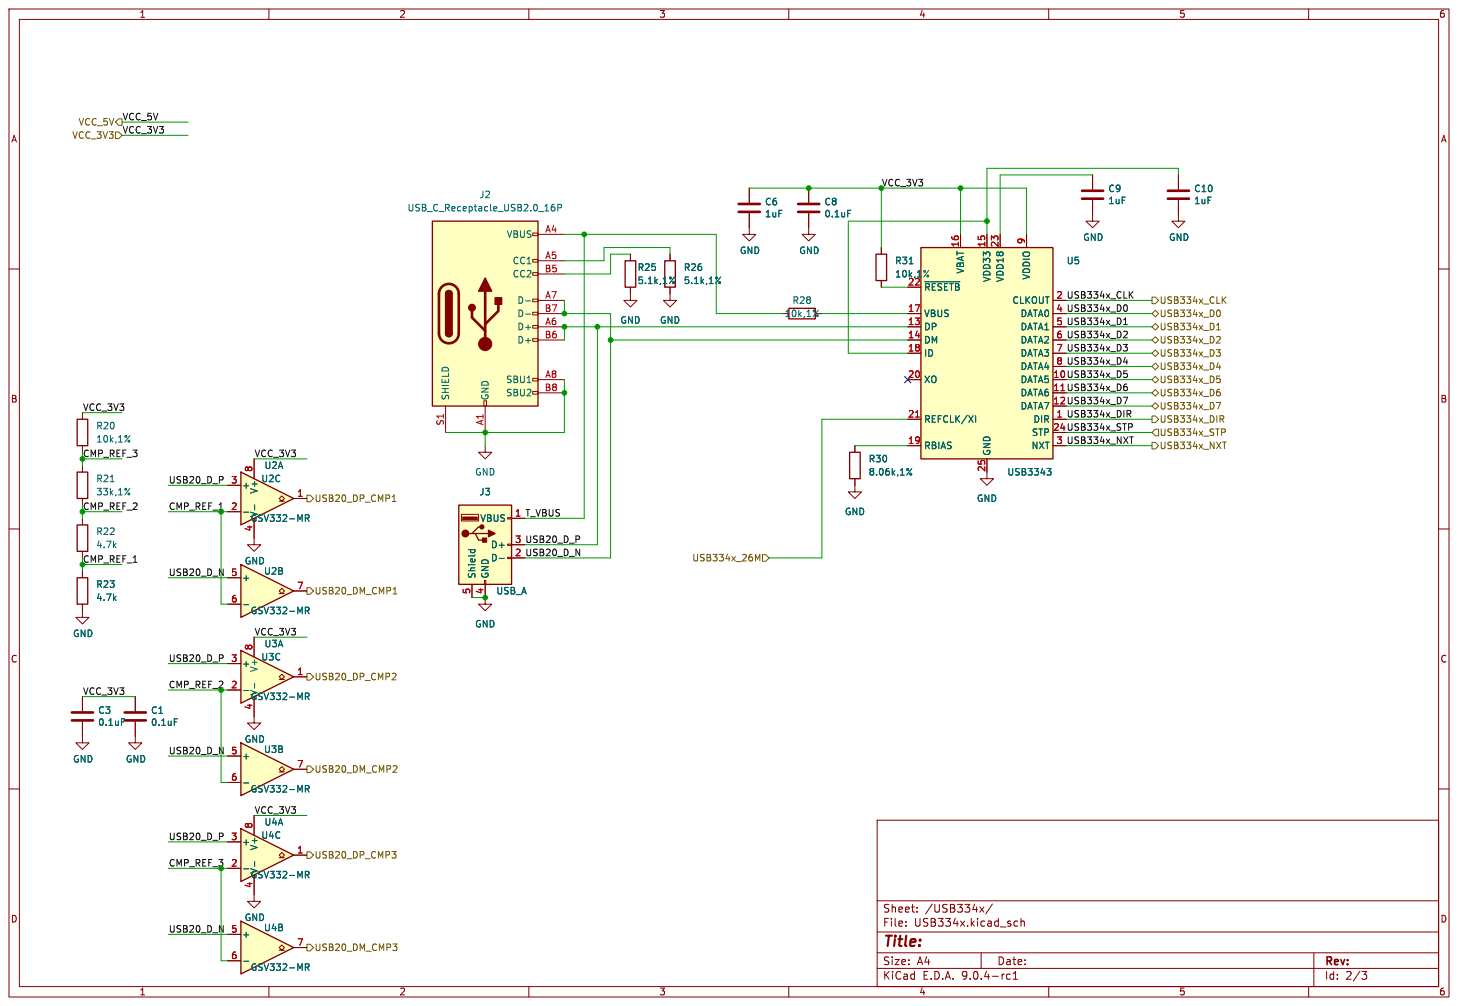
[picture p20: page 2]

Id: 2/3 Title: File: USB334x.kicad_sch Sheet: /USB334x/

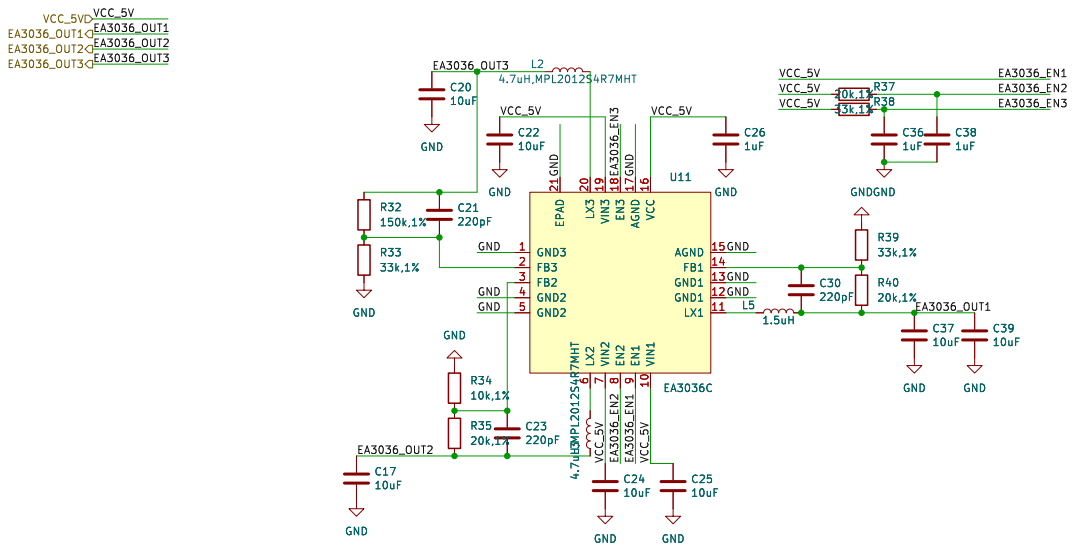
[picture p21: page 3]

Id: 3/3 Title: File: ET3036C.kicad_sch Sheet: /ET3036C/

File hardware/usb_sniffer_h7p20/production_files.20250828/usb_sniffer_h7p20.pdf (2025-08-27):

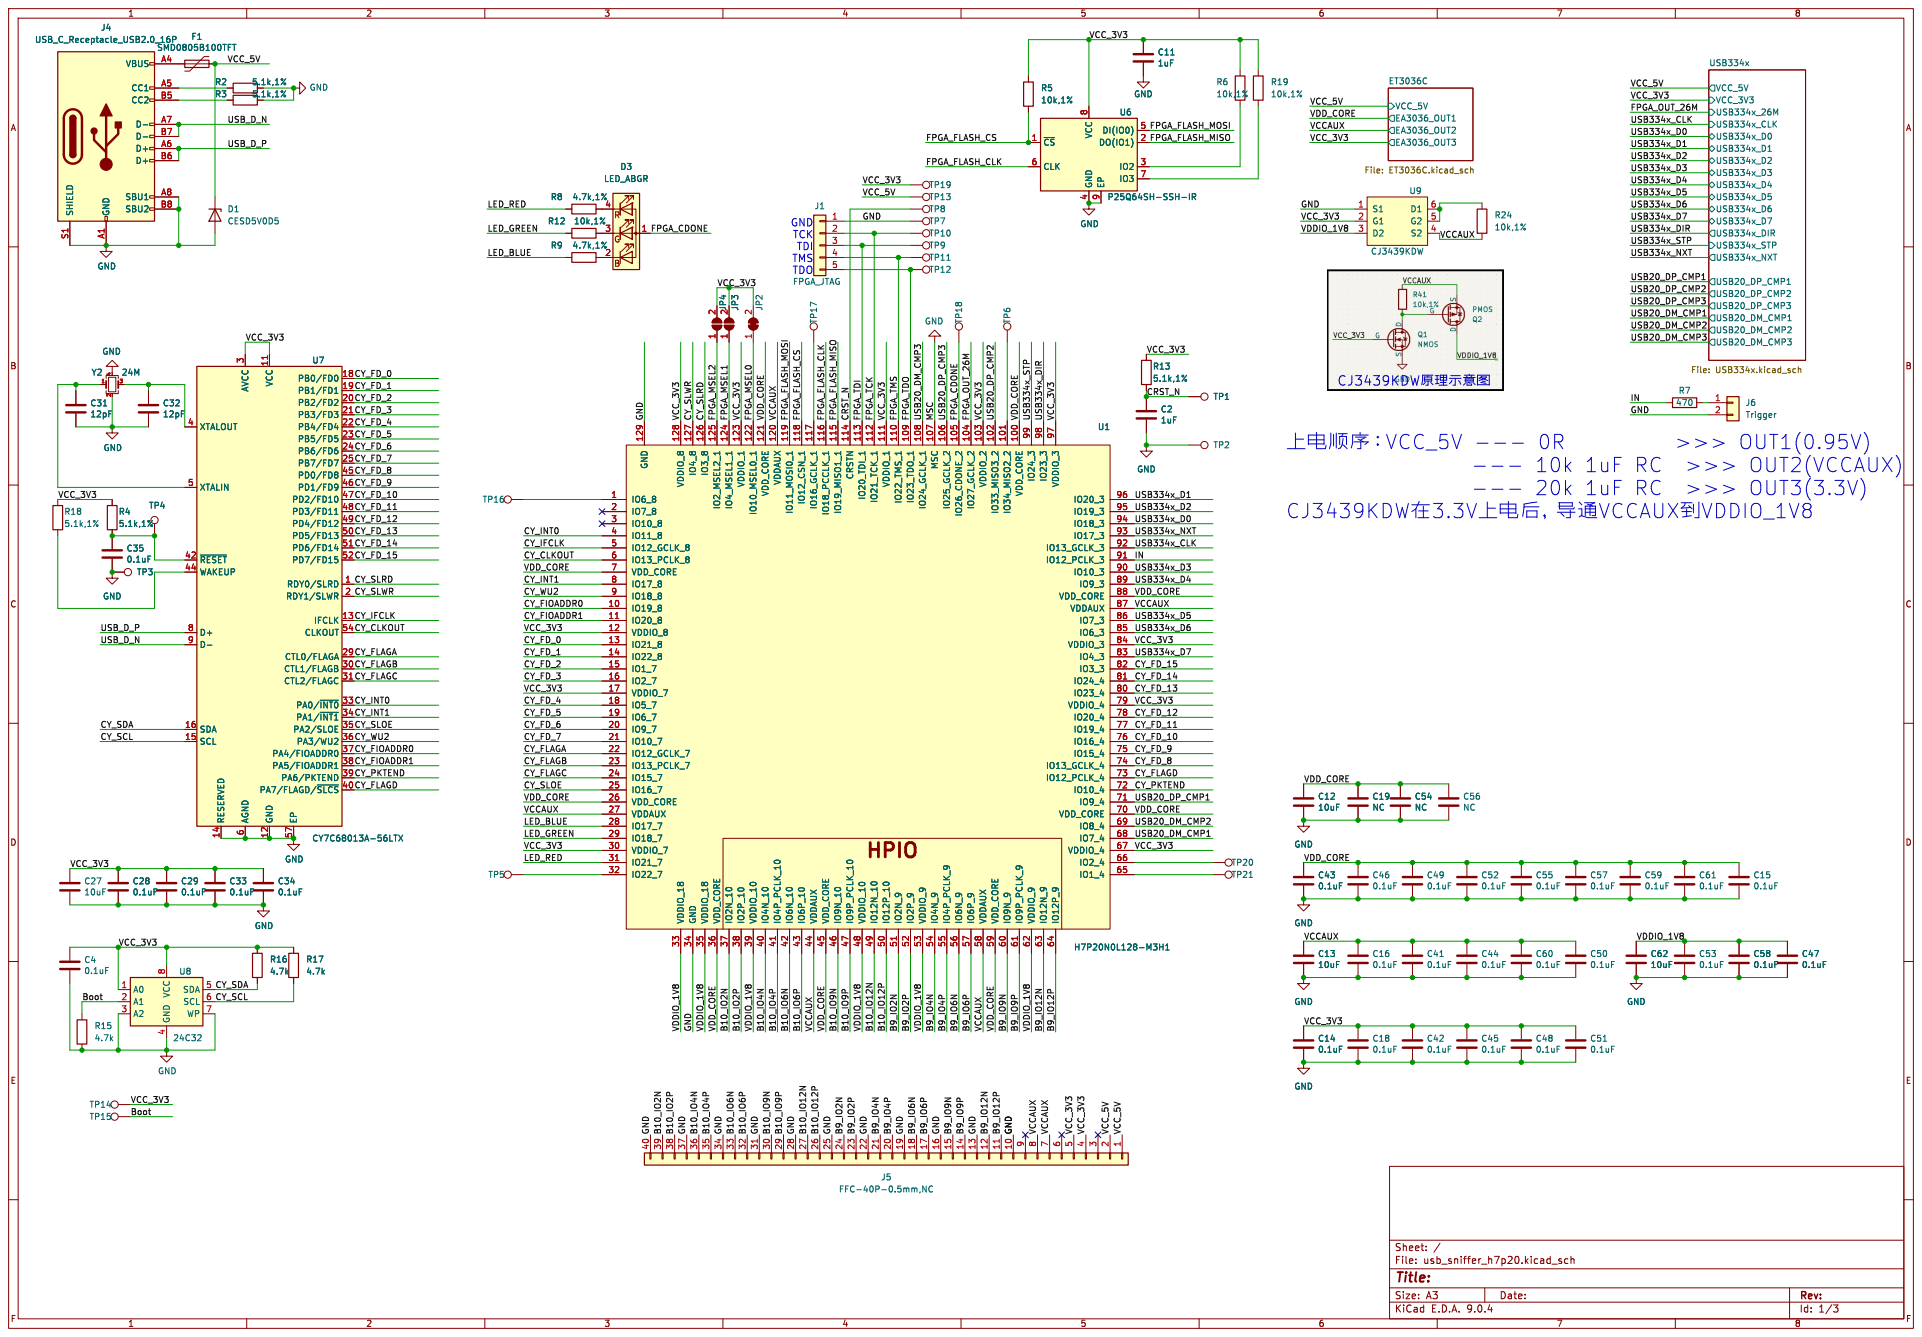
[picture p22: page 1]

VCCAUX VCCAUX VDD_CORE B10_IO9N B10_IO9P B10_IO12N B10_IO12P GND B9_IO2N B9_IO2P GND

6 VCC 11 GND 12 EP 57 PB0/FD0 18 PB1/FD1 19 PB2/FD2 20 PB3/FD3 21 PB4/FD4 22 PB5/FD5 23 PB6/FD6 24 PB7/FD7 25 PD0/FD8 45 PD1/FD9 46 PD2/FD10 47 PD3/FD11 48 PD4/FD12 49 PD5/FD13 50 PD6/FD14 51 PD7/FD15 52 RDY0/SLRD 1 RDY1/SLWR 2

IFCLK 13 CLKOUT 54 CTL0/FLAGA 29 CTL1/FLAGB 30 CTL2/FLAGC 31 PA0/~{INT0}33 PA1/~{INT1}34 PA2/SLOE 35 PA3/WU2 36 PA4/FIOADDR0 37 PA5/FIOADDR1 38 PA6/PKTEND 39 PA7/FLAGD/~{SLCS} 40

Id: 1/3 Title: File: usb_sniffer_h7p20.kicad_sch Sheet: /

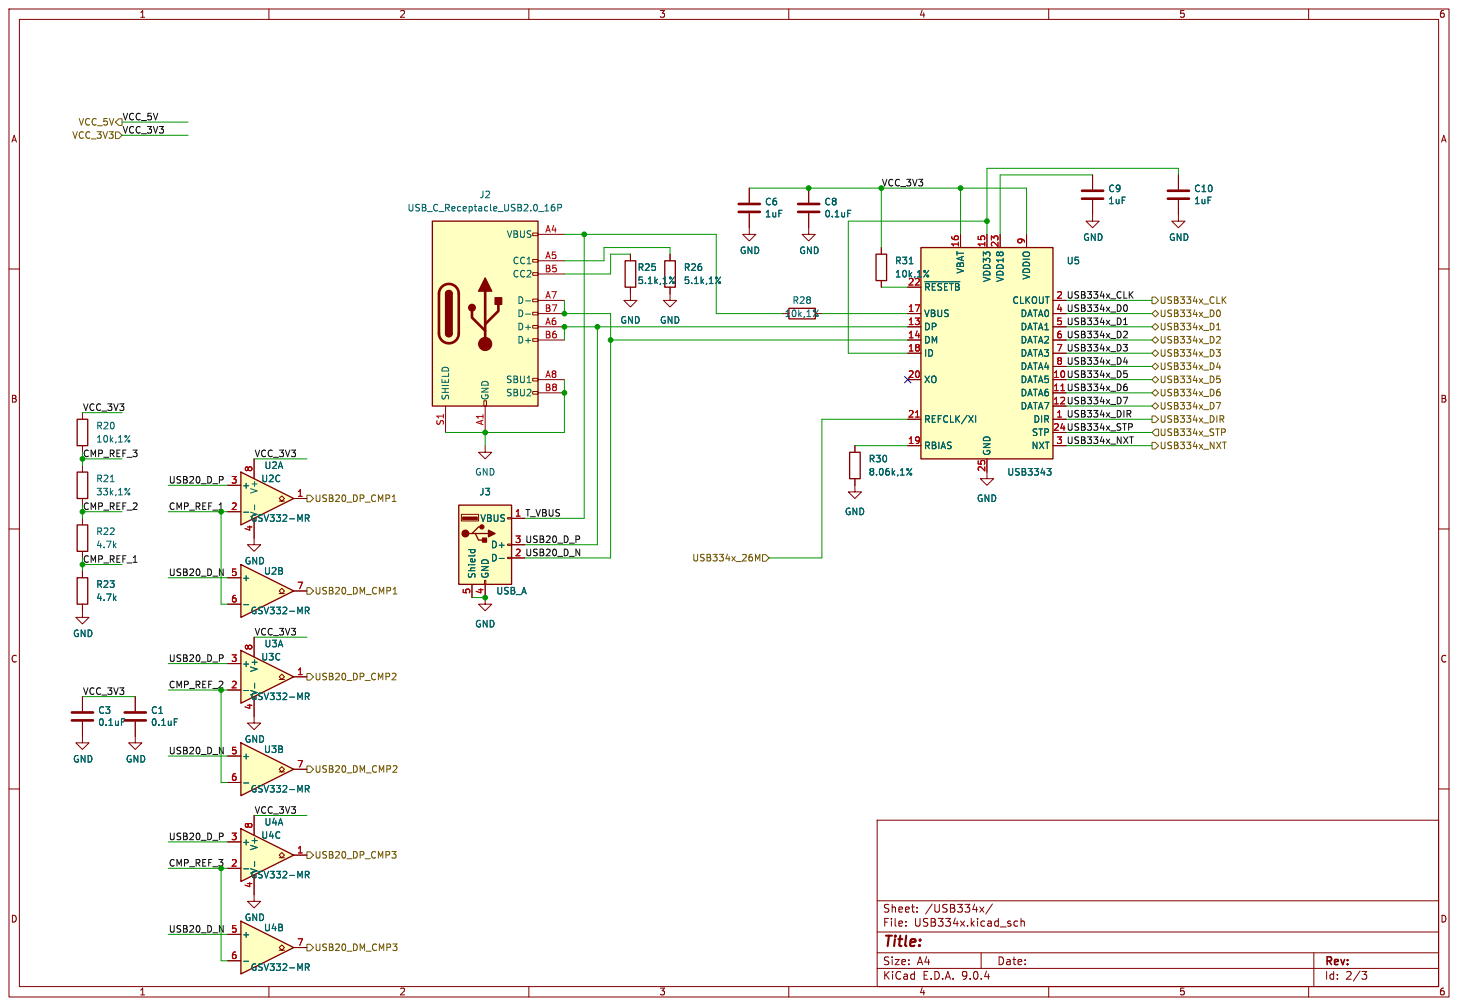
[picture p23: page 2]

Id: 2/3 Title: File: USB334x.kicad_sch Sheet: /USB334x/ GND


Id: 3/3 Title: File: ET3036C.kicad_sch Sheet: /ET3036C/

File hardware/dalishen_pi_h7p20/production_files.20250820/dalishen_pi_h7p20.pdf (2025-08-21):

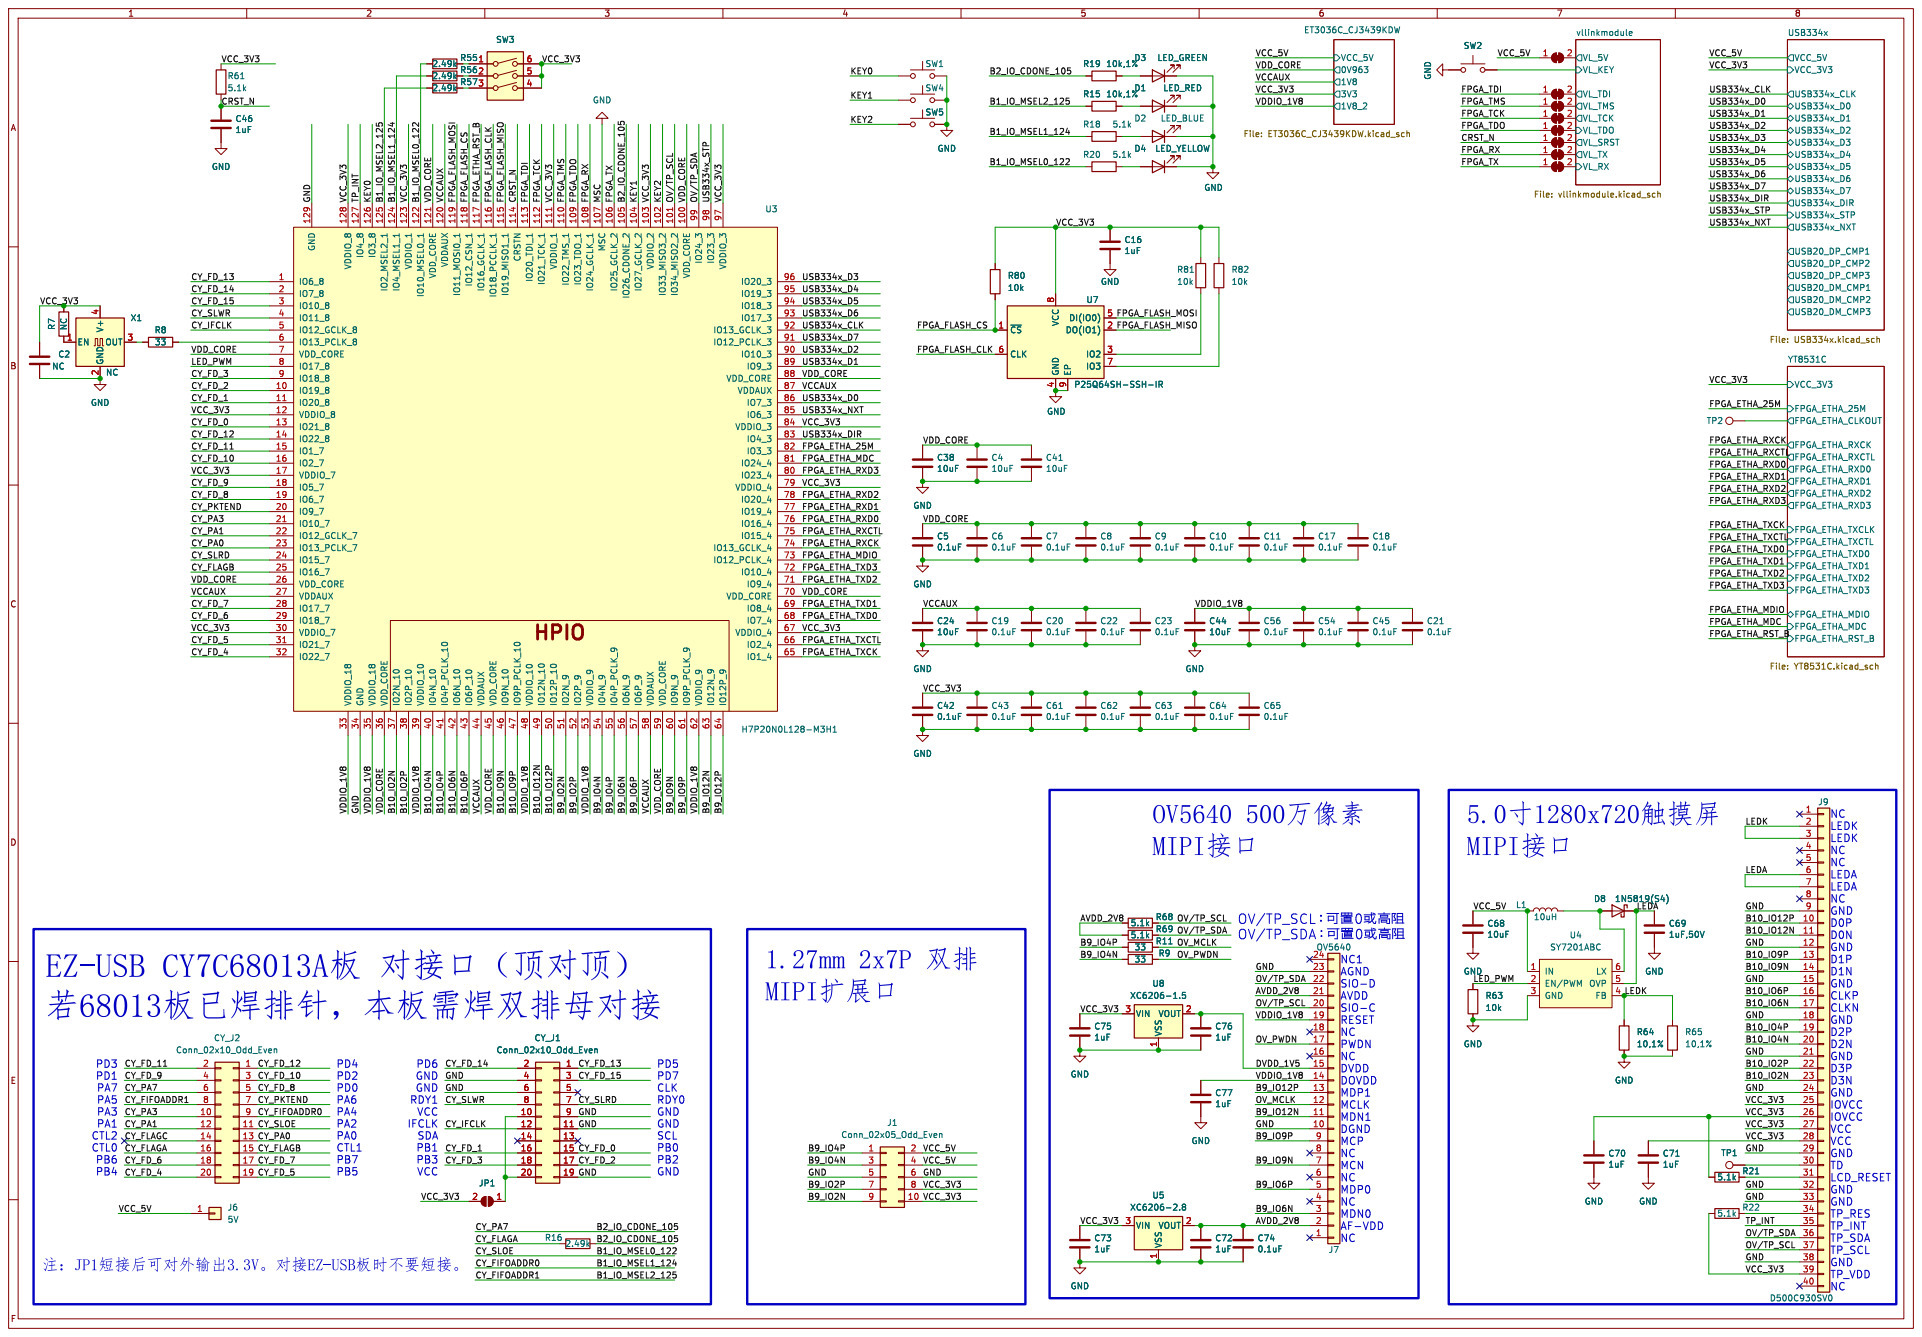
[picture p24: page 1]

B9_IO12P OV/TP_SCL VDDIO_1V8 OV/TP_SDA
AVDD_2V8 B9_IO12N OV_MCLK

EZ-USBþÿCY7C68013Ag• þÿ[ùc¥Sãÿ˜v[ù˜vÿ

IN 1 EN/PWM 2 GND 3

þÿlèÿJP1wíc¥TSï[ùY•“Qú3.3V0-

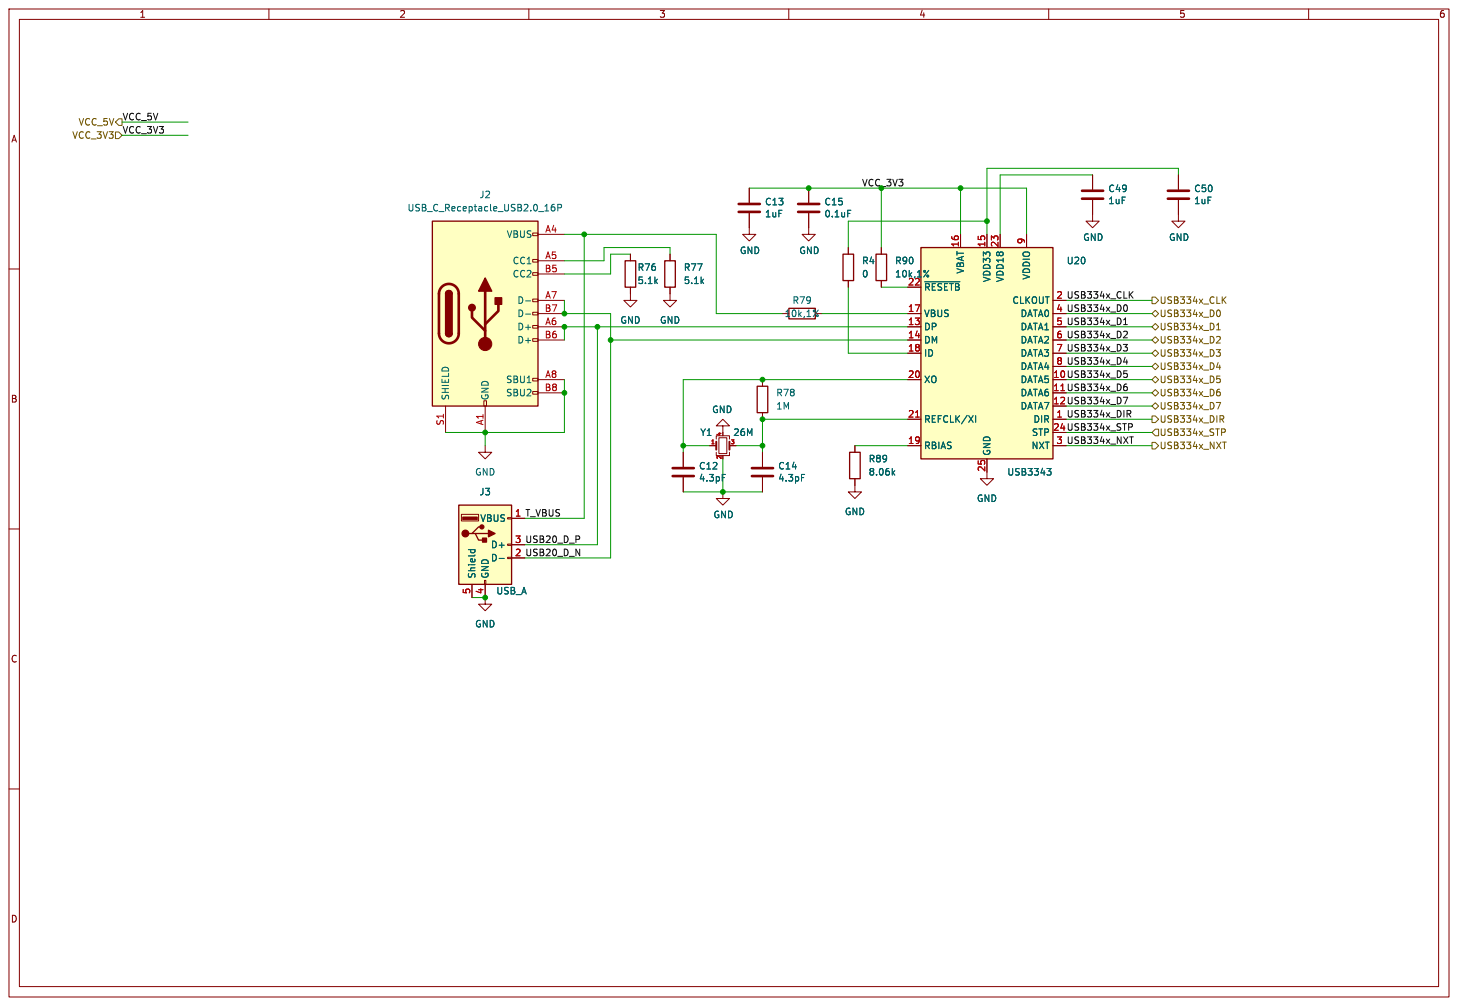
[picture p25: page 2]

9 CLKOUT 2 DATA0 4 DATA1 5 DATA2 6 DATA3 7 DATA4 8 DATA5 10 DATA6 11 DATA7 12 DIR 1 STP 24 NXT 3 U20 USB3343 GND GND

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

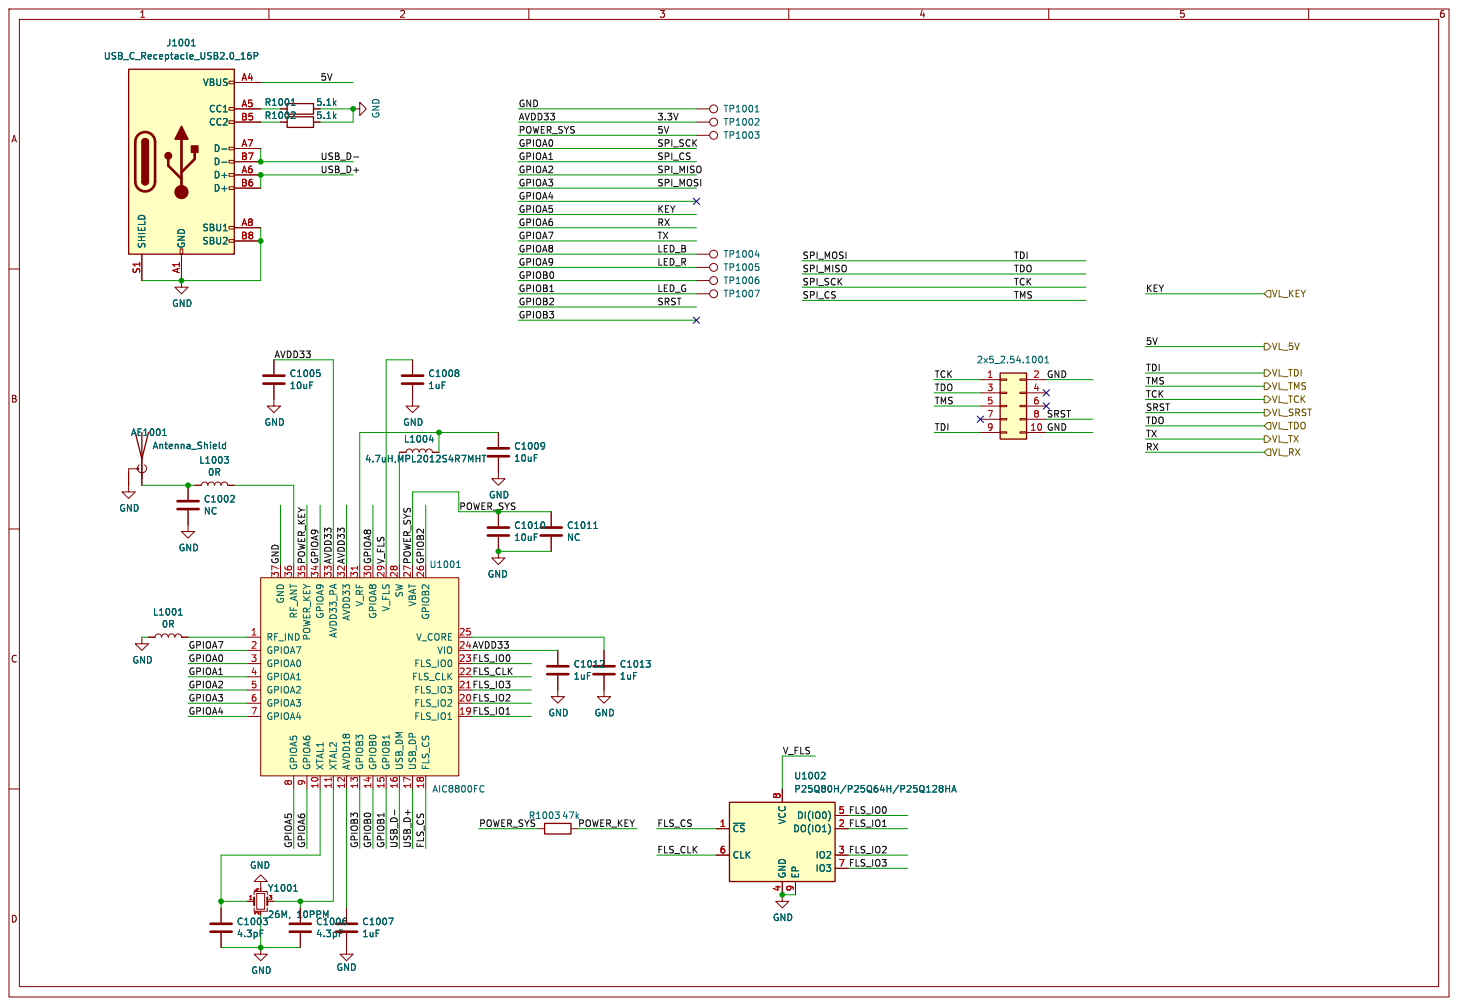
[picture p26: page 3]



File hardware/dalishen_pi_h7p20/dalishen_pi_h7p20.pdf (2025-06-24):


EZ-USBþÿCY7C68013Ag• þÿ[ùc¥Sãÿ˜v[ù˜vÿ





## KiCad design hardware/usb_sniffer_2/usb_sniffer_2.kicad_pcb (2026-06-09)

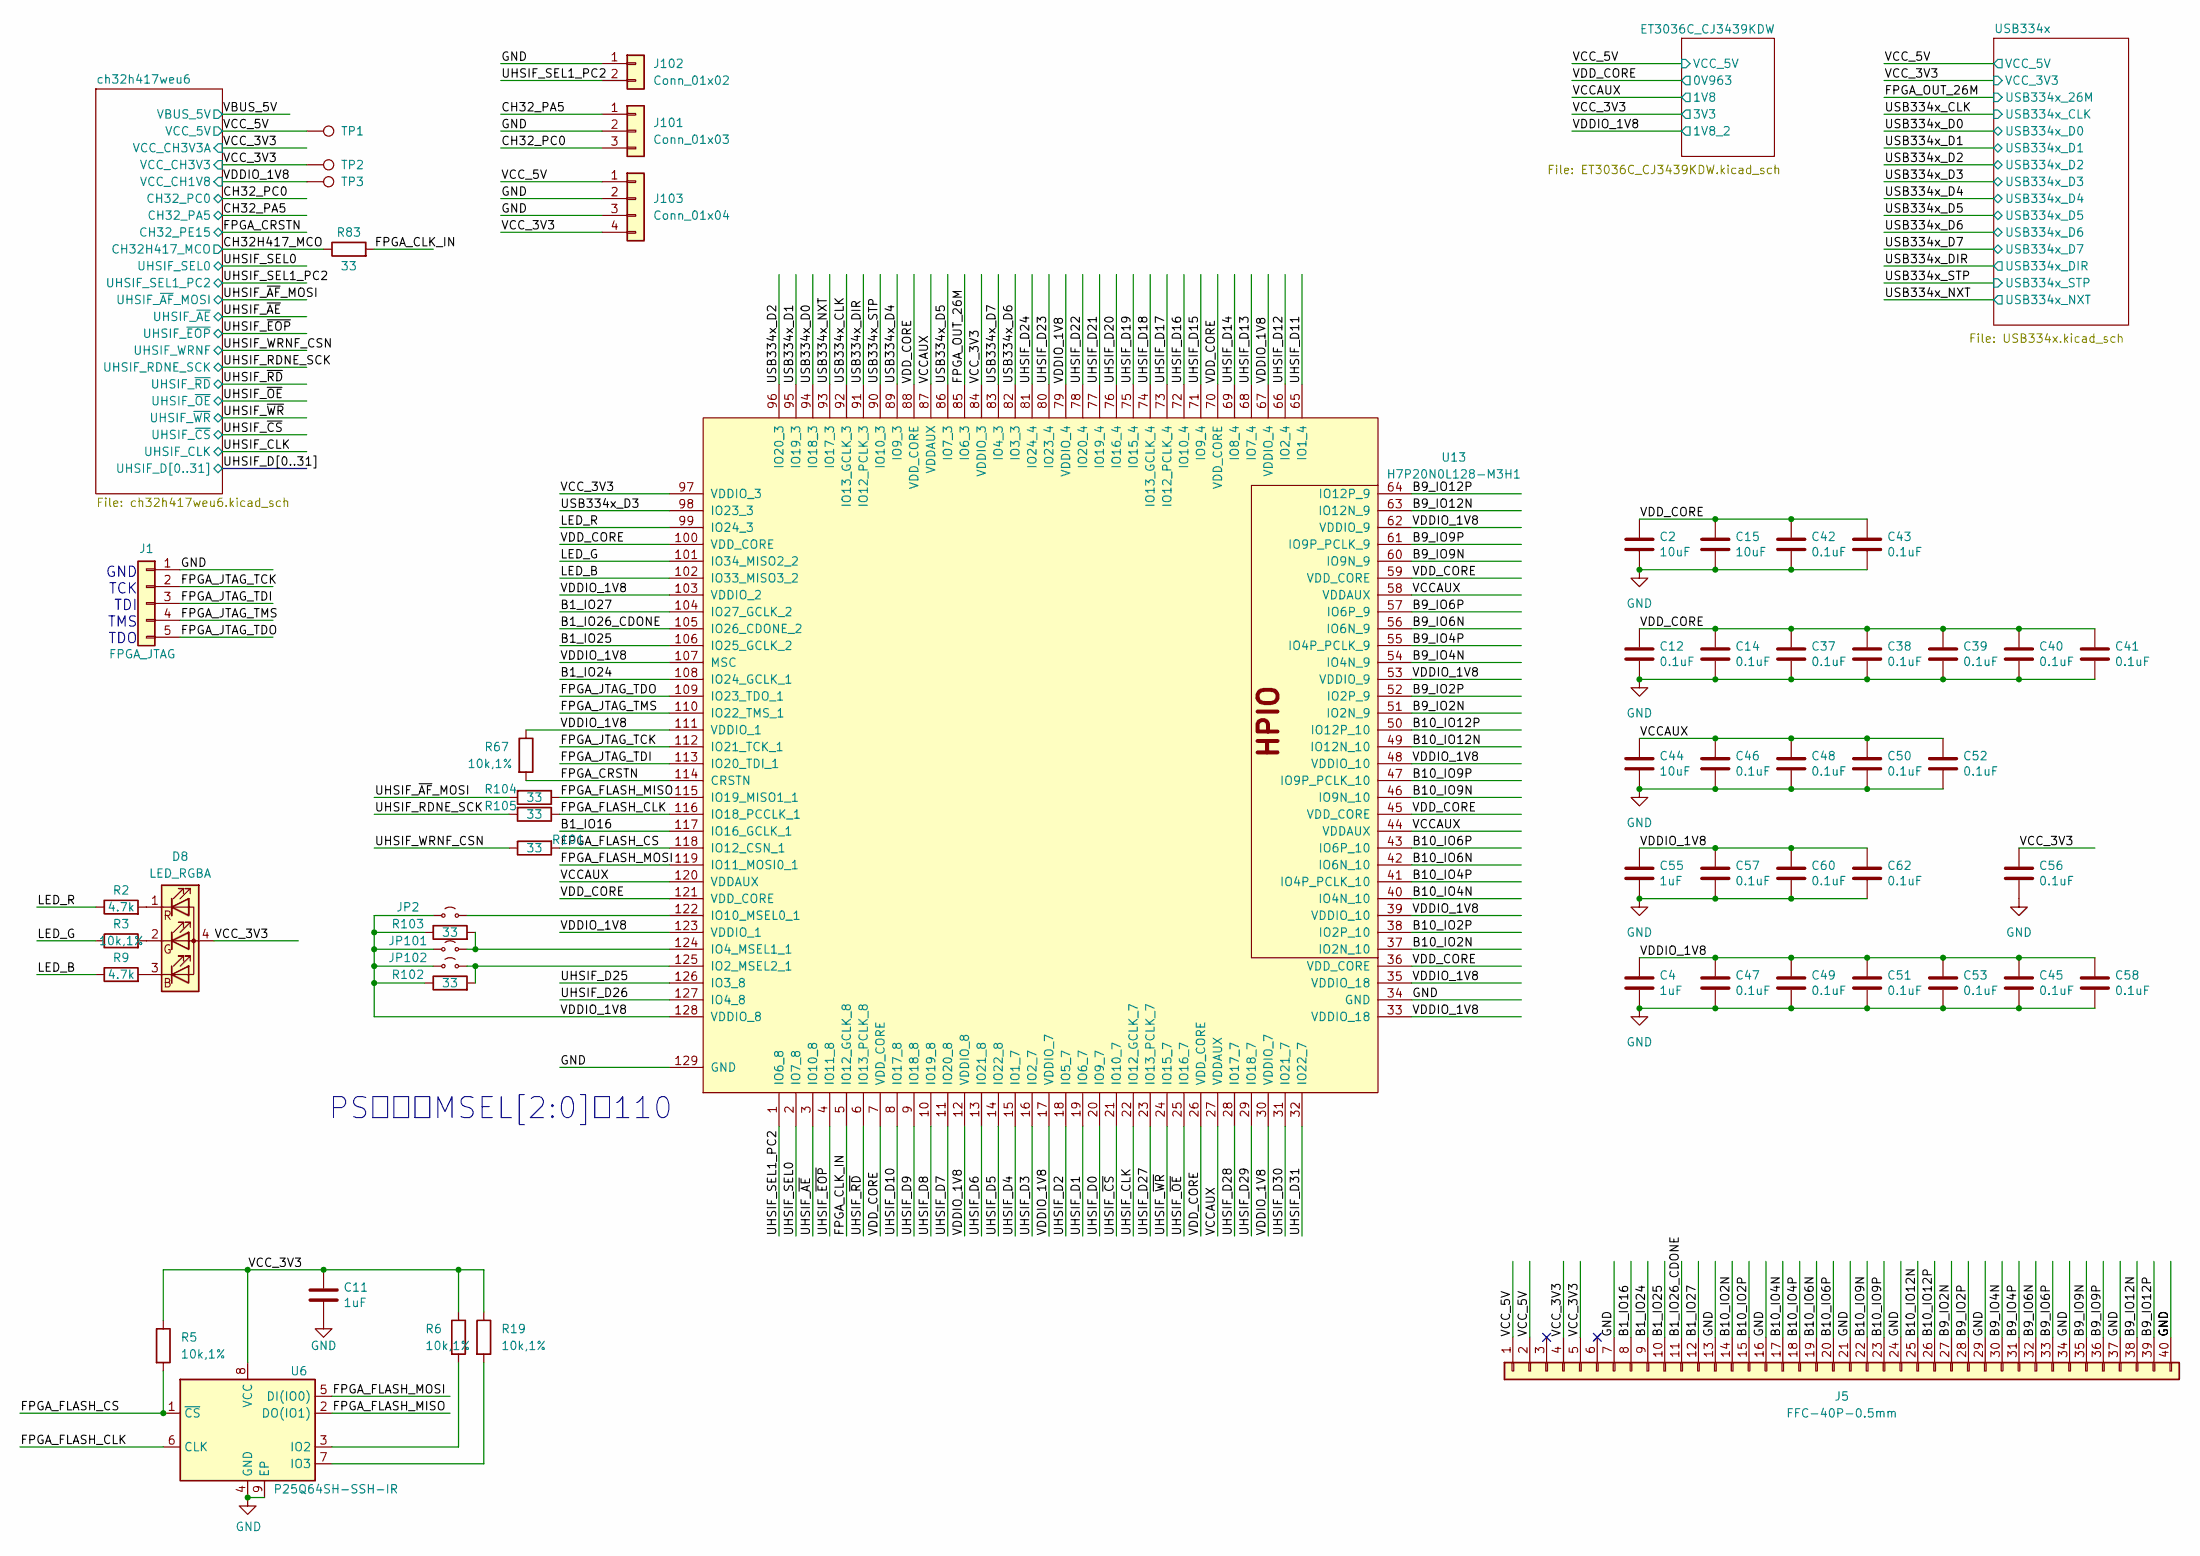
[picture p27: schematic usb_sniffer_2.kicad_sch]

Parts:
C2, C15, C44: 10uF; C_0402_1005Metric
C4, C11, C55: 1uF; C_0402_1005Metric
C12, C14, C37, C38, C39, C40, C41, C42, C43, C45, C46, C47, C48, C49, C50, C51, C52, C53, C56, C57, C58, C60, C62: 0.1uF; C_0402_1005Metric
D8: LED_RGBA; LED_RGB_Everlight_EASV3015RGBA0_Horizontal
J1: FPGA_JTAG; PinHeader_1x05_P2.54mm_Vertical
J5: FFC-40P-0.5mm; TE_4-1734839-0_1x40-1MP_P0.5mm_Horizontal
J101: Conn_01x03; PinHeader_1x03_P2.54mm_Vertical
J102: Conn_01x02; PinHeader_1x02_P1.27mm_Vertical
J103: Conn_01x04; PinHeader_1x04_P2.54mm_Vertical
JP2, JP101, JP102: Jumper_2_Small_Open; SolderJumper-2_P1.3mm_Open_RoundedPad1.0x1.5mm
R2, R9: 4.7k; R_0402_1005Metric
R3, R5, R6, R19, R67: 10k,1%; R_0402_1005Metric
R83, R101, R102, R103, R104, R105: 33; R_0402_1005Metric
TP1, TP2, TP3: TestPoint; TestPoint_Pad_D0.75mm
U6: P25Q64SH-SSH-IR; SOP-8_3.76x4.96mm_P1.27mm
U13: H7P20N0L128-M3H1; LQFP-128_14x14mm_P0.4mm_pad

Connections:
/B1_IO16: J5.8, U13.117 (IO16_GCLK_1)
/B1_IO24: J5.9, U13.108 (IO24_GCLK_1)
/B1_IO25: J5.10, U13.106 (IO25_GCLK_2)
/B1_IO26_CDONE: J5.11, U13.105 (IO26_CDONE_2)
/B1_IO27: J5.12, U13.104 (IO27_GCLK_2)
/B9_IO2N: J5.27, U13.51 (IO2N_9)
/B9_IO2P: J5.28, U13.52 (IO2P_9)
/B9_IO4N: J5.30, U13.54 (IO4N_9)
/B9_IO4P: J5.31, U13.55 (IO4P_PCLK_9)
/B9_IO6N: J5.32, U13.56 (IO6N_9)
/B9_IO6P: J5.33, U13.57 (IO6P_9)
/B9_IO9N: J5.35, U13.60 (IO9N_9)
/B9_IO9P: J5.36, U13.61 (IO9P_PCLK_9)
/B9_IO12N: J5.38, U13.63 (IO12N_9)
/B9_IO12P: J5.39, U13.64 (IO12P_9)
/B10_IO2N: J5.14, U13.37 (IO2N_10)
/B10_IO2P: J5.15, U13.38 (IO2P_10)
/B10_IO4N: J5.17, U13.40 (IO4N_10)
/B10_IO4P: J5.18, U13.41 (IO4P_PCLK_10)
/B10_IO6N: J5.19, U13.42 (IO6N_10)
/B10_IO6P: J5.20, U13.43 (IO6P_10)
/B10_IO9N: J5.22, U13.46 (IO9N_10)
/B10_IO9P: J5.23, U13.47 (IO9P_PCLK_10)
/B10_IO12N: J5.25, U13.49 (IO12N_10)
/B10_IO12P: J5.26, U13.50 (IO12P_10)
/CH32H417_MCO: R83.1; also elsewhere on the board
/CH32_PA5: J101.1; also elsewhere on the board
/CH32_PC0: J101.3; also elsewhere on the board
/FPGA_CLK_IN: R83.2, U13.5 (IO12_GCLK_8)
/FPGA_CRSTN: R67.2, U13.114 (CRSTN); also elsewhere on the board
/FPGA_FLASH_CLK: R105.1, U6.6 (CLK), U13.116 (IO18_PCCLK_1)
/FPGA_FLASH_CS: R5.2, R101.2, U6.1 (~CS), U13.118 (IO12_CSN_1)
/FPGA_FLASH_MISO: R104.1, U6.2 (DO(IO1)), U13.115 (IO19_MISO1_1)
/FPGA_FLASH_MOSI: U6.5 (DI(IO0)), U13.119 (IO11_MOSI0_1)
/FPGA_JTAG_TCK: J1.2, U13.112 (IO21_TCK_1)
/FPGA_JTAG_TDI: J1.3, U13.113 (IO20_TDI_1)
/FPGA_JTAG_TDO: J1.5, U13.109 (IO23_TDO_1)
/FPGA_JTAG_TMS: J1.4, U13.110 (IO22_TMS_1)
/FPGA_OUT_26M: U13.85 (IO6_3); also elsewhere on the board
/LED_B: R9.1, U13.102 (IO33_MISO3_2)
/LED_G: R3.1, U13.101 (IO34_MISO2_2)
/LED_R: R2.1, U13.99 (IO24_3)
/UHSIF_CLK: U13.22 (IO12_GCLK_7); also elsewhere on the board
/UHSIF_D0: U13.20 (IO9_7); also elsewhere on the board
/UHSIF_D1: U13.19 (IO6_7); also elsewhere on the board
/UHSIF_D2: U13.18 (IO5_7); also elsewhere on the board
/UHSIF_D3: U13.16 (IO2_7); also elsewhere on the board
/UHSIF_D4: U13.15 (IO1_7); also elsewhere on the board
/UHSIF_D5: U13.14 (IO22_8); also elsewhere on the board
/UHSIF_D6: U13.13 (IO21_8); also elsewhere on the board
/UHSIF_D7: U13.11 (IO20_8); also elsewhere on the board
/UHSIF_D8: U13.10 (IO19_8); also elsewhere on the board
/UHSIF_D9: U13.9 (IO18_8); also elsewhere on the board
/UHSIF_D10: U13.8 (IO17_8); also elsewhere on the board
/UHSIF_D11: U13.65 (IO1_4); also elsewhere on the board
/UHSIF_D12: U13.66 (IO2_4); also elsewhere on the board
/UHSIF_D13: U13.68 (IO7_4); also elsewhere on the board
/UHSIF_D14: U13.69 (IO8_4); also elsewhere on the board
/UHSIF_D15: U13.71 (IO9_4); also elsewhere on the board
/UHSIF_D16: U13.72 (IO10_4); also elsewhere on the board
/UHSIF_D17: U13.73 (IO12_PCLK_4); also elsewhere on the board
/UHSIF_D18: U13.74 (IO13_GCLK_4); also elsewhere on the board
/UHSIF_D19: U13.75 (IO15_4); also elsewhere on the board
/UHSIF_D20: U13.76 (IO16_4); also elsewhere on the board
/UHSIF_D21: U13.77 (IO19_4); also elsewhere on the board
/UHSIF_D22: U13.78 (IO20_4); also elsewhere on the board
/UHSIF_D23: U13.80 (IO23_4); also elsewhere on the board
/UHSIF_D24: U13.81 (IO24_4); also elsewhere on the board
/UHSIF_D25: U13.126 (IO3_8); also elsewhere on the board
/UHSIF_D26: U13.127 (IO4_8); also elsewhere on the board
/UHSIF_D27: U13.23 (IO13_PCLK_7); also elsewhere on the board
/UHSIF_D28: U13.28 (IO17_7); also elsewhere on the board
/UHSIF_D29: U13.29 (IO18_7); also elsewhere on the board
/UHSIF_D30: U13.31 (IO21_7); also elsewhere on the board
/UHSIF_D31: U13.32 (IO22_7); also elsewhere on the board
/UHSIF_RDNE_SCK: R105.2; also elsewhere on the board
/UHSIF_SEL0: U13.2 (IO7_8); also elsewhere on the board
/UHSIF_SEL1_PC2: J102.2, U13.1 (IO6_8); also elsewhere on the board
/UHSIF_WRNF_CSN: R101.1; also elsewhere on the board
/UHSIF_~AE: U13.3 (IO10_8); also elsewhere on the board
/UHSIF_~AF_MOSI: R104.2; also elsewhere on the board
/UHSIF_~CS: U13.21 (IO10_7); also elsewhere on the board
/UHSIF_~EOP: U13.4 (IO11_8); also elsewhere on the board
/UHSIF_~OE: U13.25 (IO16_7); also elsewhere on the board
/UHSIF_~RD: U13.6 (IO13_PCLK_8); also elsewhere on the board
/UHSIF_~WR: U13.24 (IO15_7); also elsewhere on the board
/USB334x_CLK: U13.92 (IO13_GCLK_3); also elsewhere on the board
/USB334x_D0: U13.94 (IO18_3); also elsewhere on the board
/USB334x_D1: U13.95 (IO19_3); also elsewhere on the board
/USB334x_D2: U13.96 (IO20_3); also elsewhere on the board
/USB334x_D3: U13.98 (IO23_3); also elsewhere on the board
/USB334x_D4: U13.89 (IO9_3); also elsewhere on the board
/USB334x_D5: U13.86 (IO7_3); also elsewhere on the board
/USB334x_D6: U13.82 (IO3_3); also elsewhere on the board
/USB334x_D7: U13.83 (IO4_3); also elsewhere on the board
/USB334x_DIR: U13.91 (IO12_PCLK_3); also elsewhere on the board
/USB334x_NXT: U13.93 (IO17_3); also elsewhere on the board
/USB334x_STP: U13.90 (IO10_3); also elsewhere on the board
/VCCAUX: C44.2, C46.2, C48.2, C50.2, C52.2, U13.27 (VDDAUX), U13.44 (VDDAUX), U13.58 (VDDAUX), U13.87 (VDDAUX), U13.120 (VDDAUX); also elsewhere on the board
/VCC_3V3: C11.2, C56.2, D8.4 (A), J5.4, J5.5, J103.4, R5.1, R6.1, R19.1, TP2.1, U6.8 (VCC), U13.84 (VDDIO_3), U13.97 (VDDIO_3); also elsewhere on the board
/VCC_5V: J5.1, J5.2, J103.1, TP1.1; also elsewhere on the board
/VDDIO_1V8: C4.2, C45.2, C47.2, C49.2, C51.2, C53.2, C55.2, C57.2, C58.2, C60.2, C62.2, JP2.1 (A), JP101.1 (A), JP102.1 (A), R67.1, R102.1, R103.1, TP3.1, U13.12 (VDDIO_8), U13.17 (VDDIO_7), U13.30 (VDDIO_7), U13.33 (VDDIO_18), U13.35 (VDDIO_18), U13.39 (VDDIO_10), U13.48 (VDDIO_10), U13.53 (VDDIO_9), U13.62 (VDDIO_9), U13.67 (VDDIO_4), U13.79 (VDDIO_4), U13.103 (VDDIO_2), U13.107 (MSC), U13.111 (VDDIO_1), U13.123 (VDDIO_1), U13.128 (VDDIO_8); also elsewhere on the board
/VDD_CORE: C2.2, C12.2, C14.2, C15.2, C37.2, C38.2, C39.2, C40.2, C41.2, C42.2, C43.2, U13.7 (VDD_CORE), U13.26 (VDD_CORE), U13.36 (VDD_CORE), U13.45 (VDD_CORE), U13.59 (VDD_CORE), U13.70 (VDD_CORE), U13.88 (VDD_CORE), U13.100 (VDD_CORE), U13.121 (VDD_CORE); also elsewhere on the board
GND: C2.1, C4.1, C11.1, C12.1, C14.1, C15.1, C37.1, C38.1, C39.1, C40.1, C41.1, C42.1, C43.1, C44.1, C45.1, C46.1, C47.1, C48.1, C49.1, C50.1, C51.1, C52.1, C53.1, C55.1, C56.1, C57.1, C58.1, C60.1, C62.1, J1.1, J5.7, J5.13, J5.16, J5.21, J5.24, J5.29, J5.34, J5.37, J5.40, J101.2, J102.1, J103.2, J103.3, U6.4 (GND), U6.9 (EP), U13.34 (GND), U13.129 (GND); also elsewhere on the board
unnamed: D8.3 (BK), R9.2
unnamed: D8.2 (GK), R3.2
unnamed: D8.1 (RK), R2.2
unnamed: JP2.2 (B), U13.122 (IO10_MSEL0_1)
unnamed: JP101.2 (B), R103.2, U13.124 (IO4_MSEL1_1)
unnamed: JP102.2 (B), R102.2, U13.125 (IO2_MSEL2_1)
unnamed: R6.2, U6.3 (IO2)
unnamed: R19.2, U6.7 (IO3)

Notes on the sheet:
GND TCK TDI TMS TDO
PS模式，MSEL[2:0]：110

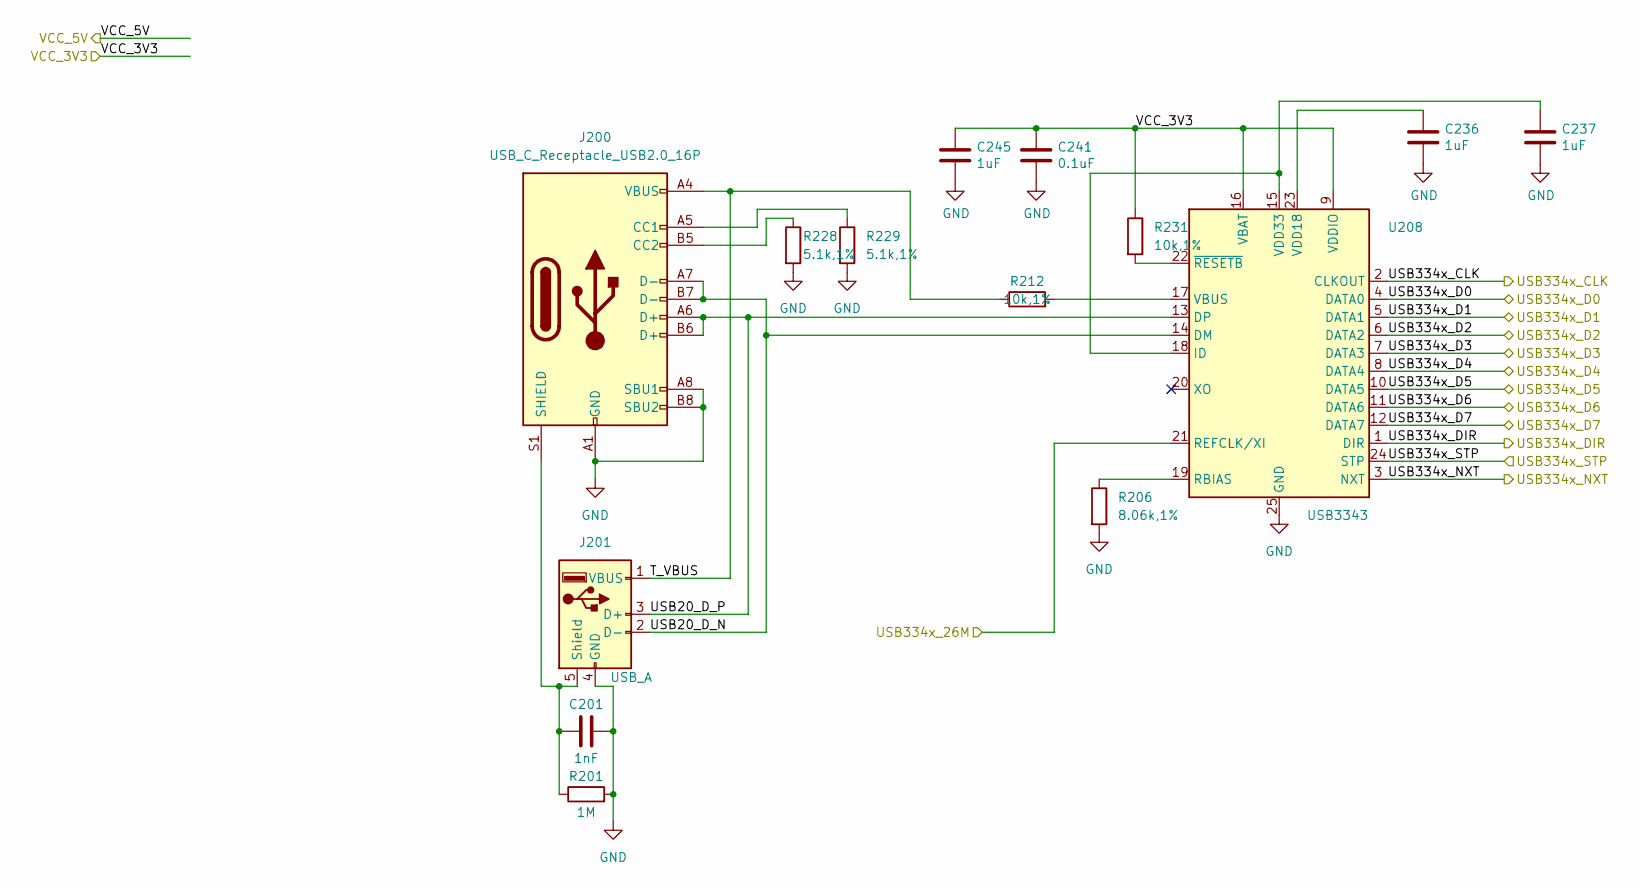
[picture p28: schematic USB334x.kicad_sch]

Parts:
C201: 1nF; C_1206_3216Metric
C236, C237, C245: 1uF; C_0402_1005Metric
C241: 0.1uF; C_0402_1005Metric
J200: USB_C_Receptacle_USB2.0_16P; USB_C_Receptacle_16P
J201: USB_A; USB_AF_SMT
R201: 1M; R_0603_1608Metric
R206: 8.06k,1%; R_0402_1005Metric
R212, R231: 10k,1%; R_0402_1005Metric
R228, R229: 5.1k,1%; R_0402_1005Metric
U208: USB3343; QFN-24-1EP_4x4mm_P0.5mm_EP2.6x2.6mm

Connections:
/FPGA_OUT_26M: U208.21 (REFCLK/XI); also elsewhere on the board
/USB334x/T_VBUS: J200.A4 (VBUS), J200.A9 (VBUS), J200.B4 (VBUS), J200.B9 (VBUS), J201.1 (VBUS), R212.1
/USB334x/USB20_D_N: J200.A7 (D-), J200.B7 (D-), J201.2 (D-), U208.14 (DM)
/USB334x/USB20_D_P: J200.A6 (D+), J200.B6 (D+), J201.3 (D+), U208.13 (DP)
/USB334x_CLK: U208.2 (CLKOUT); also elsewhere on the board
/USB334x_D0: U208.4 (DATA0); also elsewhere on the board
/USB334x_D1: U208.5 (DATA1); also elsewhere on the board
/USB334x_D2: U208.6 (DATA2); also elsewhere on the board
/USB334x_D3: U208.7 (DATA3); also elsewhere on the board
/USB334x_D4: U208.8 (DATA4); also elsewhere on the board
/USB334x_D5: U208.10 (DATA5); also elsewhere on the board
/USB334x_D6: U208.11 (DATA6); also elsewhere on the board
/USB334x_D7: U208.12 (DATA7); also elsewhere on the board
/USB334x_DIR: U208.1 (DIR); also elsewhere on the board
/USB334x_NXT: U208.3 (NXT); also elsewhere on the board
/USB334x_STP: U208.24 (STP); also elsewhere on the board
/VCC_3V3: C241.2, C245.2, R231.1, U208.9 (VDDIO), U208.16 (VBAT); also elsewhere on the board
GND: C201.2, C236.1, C237.1, C241.1, C245.1, J200.A1 (GND), J200.A8 (SBU1), J200.A12 (GND), J200.B1 (GND), J200.B8 (SBU2), J200.B12 (GND), J201.4 (GND), R201.2, R206.2, R228.2, R229.2, U208.25 (GND); also elsewhere on the board
unnamed: J200.A5 (CC1), R229.1
unnamed: J200.B5 (CC2), R228.1
unnamed: C201.1, J200.S1 (SHIELD), J201.5 (Shield), R201.1
unnamed: C237.2, U208.15 (VDD33), U208.18 (ID)
unnamed: R206.1, U208.19 (RBIAS)
unnamed: R212.2, U208.17 (VBUS)
unnamed: C236.2, U208.23 (VDD18)
unnamed: R231.2, U208.22 (~RESETB)

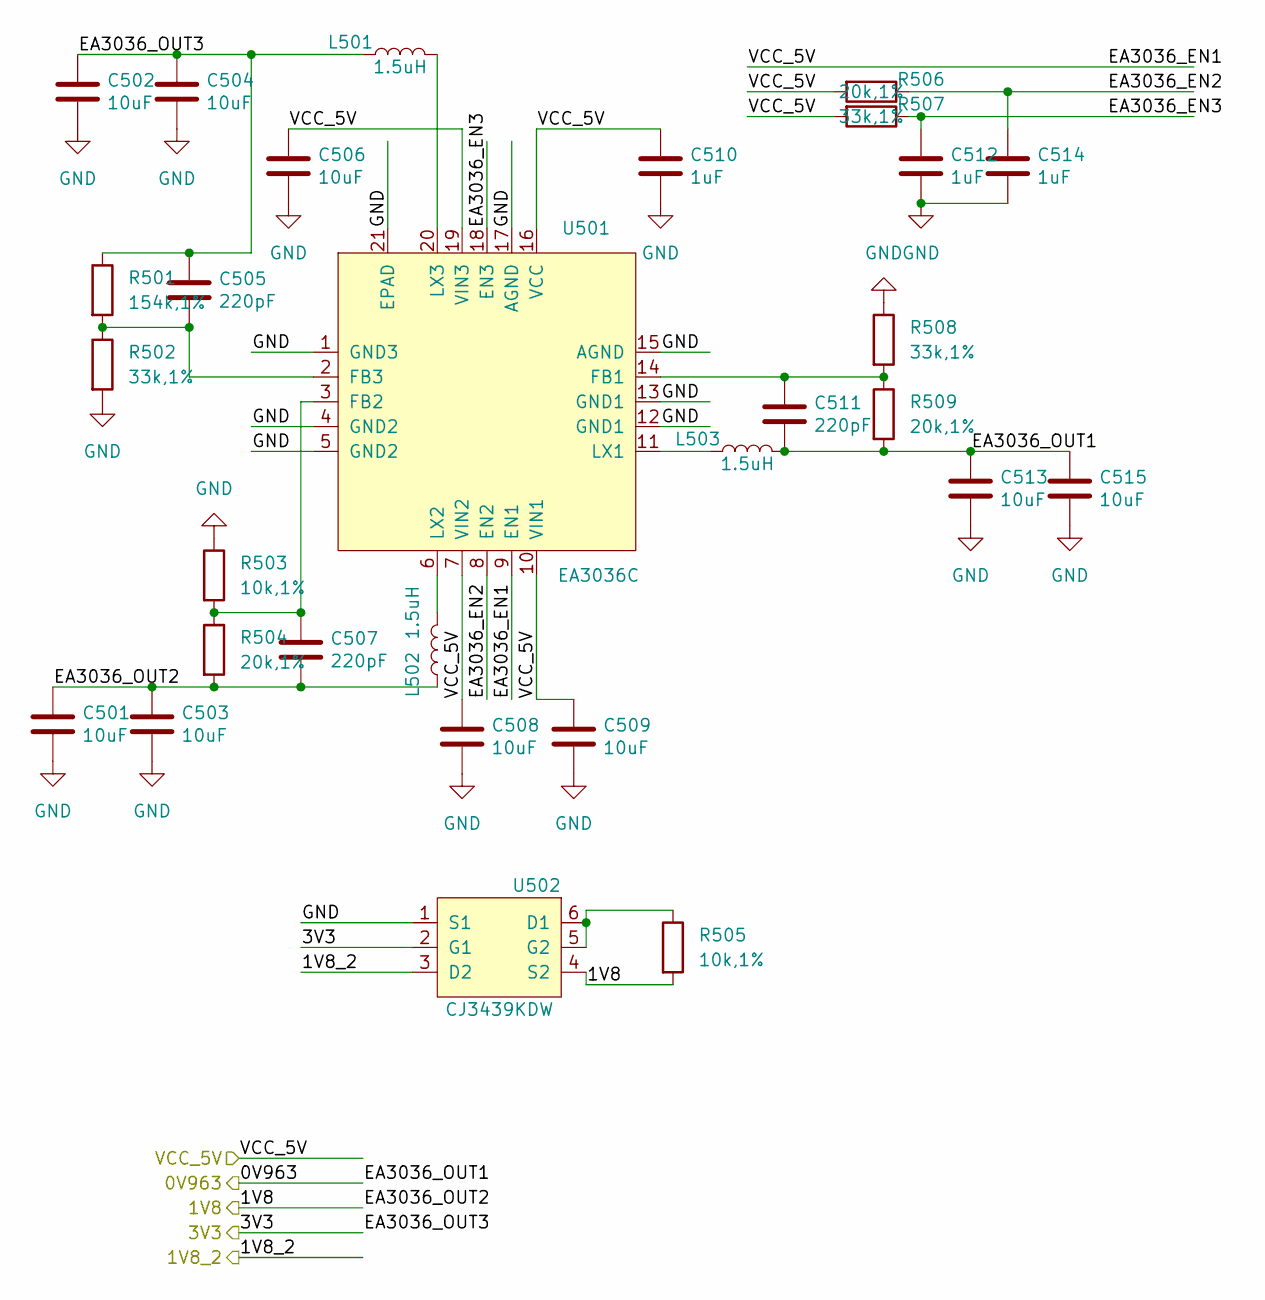
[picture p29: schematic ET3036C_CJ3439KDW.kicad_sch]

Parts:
C501, C502, C503, C504, C513, C515: 10uF; C_0402_1005Metric
C505, C507, C511: 220pF; C_0402_1005Metric
C506, C508, C509: 10uF; C_0603_1608Metric
C510, C512, C514: 1uF; C_0402_1005Metric
L501, L502, L503: 1.5uH; L_NR3015
R501: 154k,1%; R_0402_1005Metric
R502, R507, R508: 33k,1%; R_0402_1005Metric
R503, R505: 10k,1%; R_0402_1005Metric
R504, R506, R509: 20k,1%; R_0402_1005Metric
U501: EA3036C; QFN-20-1EP_3x3mm_P0.4mm_EP1.65x1.65mm
U502: CJ3439KDW; SOT-363_SC-70-6

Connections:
/ET3036C_CJ3439KDW/EA3036_EN2: C514.2, R506.1, U501.8 (EN2)
/ET3036C_CJ3439KDW/EA3036_EN3: C512.2, R507.1, U501.18 (EN3)
/VCCAUX: C501.2, C503.2, C507.1, L502.1, R504.2, R505.2, U502.4 (S2); also elsewhere on the board
/VCC_3V3: C502.2, C504.2, C505.2, L501.1, R501.1, U502.2 (G1); also elsewhere on the board
/VCC_5V: C506.2, C508.2, C509.2, C510.2, R506.2, R507.2, U501.7 (VIN2), U501.9 (EN1), U501.10 (VIN1), U501.16 (VCC), U501.19 (VIN3); also elsewhere on the board
/VDDIO_1V8: U502.3 (D2); also elsewhere on the board
/VDD_CORE: C511.1, C513.2, C515.2, L503.2, R509.2; also elsewhere on the board
GND: C501.1, C502.1, C503.1, C504.1, C506.1, C508.1, C509.1, C510.1, C512.1, C513.1, C514.1, C515.1, R502.2, R503.1, R508.1, U501.1 (GND3), U501.4 (GND2), U501.5 (GND2), U501.12 (GND1), U501.13 (GND1), U501.15 (AGND), U501.17 (AGND), U501.21 (EPAD), U502.1 (S1); also elsewhere on the board
unnamed: C511.2, R508.2, R509.1, U501.14 (FB1)
unnamed: C507.2, R503.2, R504.1, U501.3 (FB2)
unnamed: C505.1, R501.2, R502.1, U501.2 (FB3)
unnamed: L503.1, U501.11 (LX1)
unnamed: L502.2, U501.6 (LX2)
unnamed: L501.2, U501.20 (LX3)
unnamed: R505.1, U502.5 (G2), U502.6 (D1)

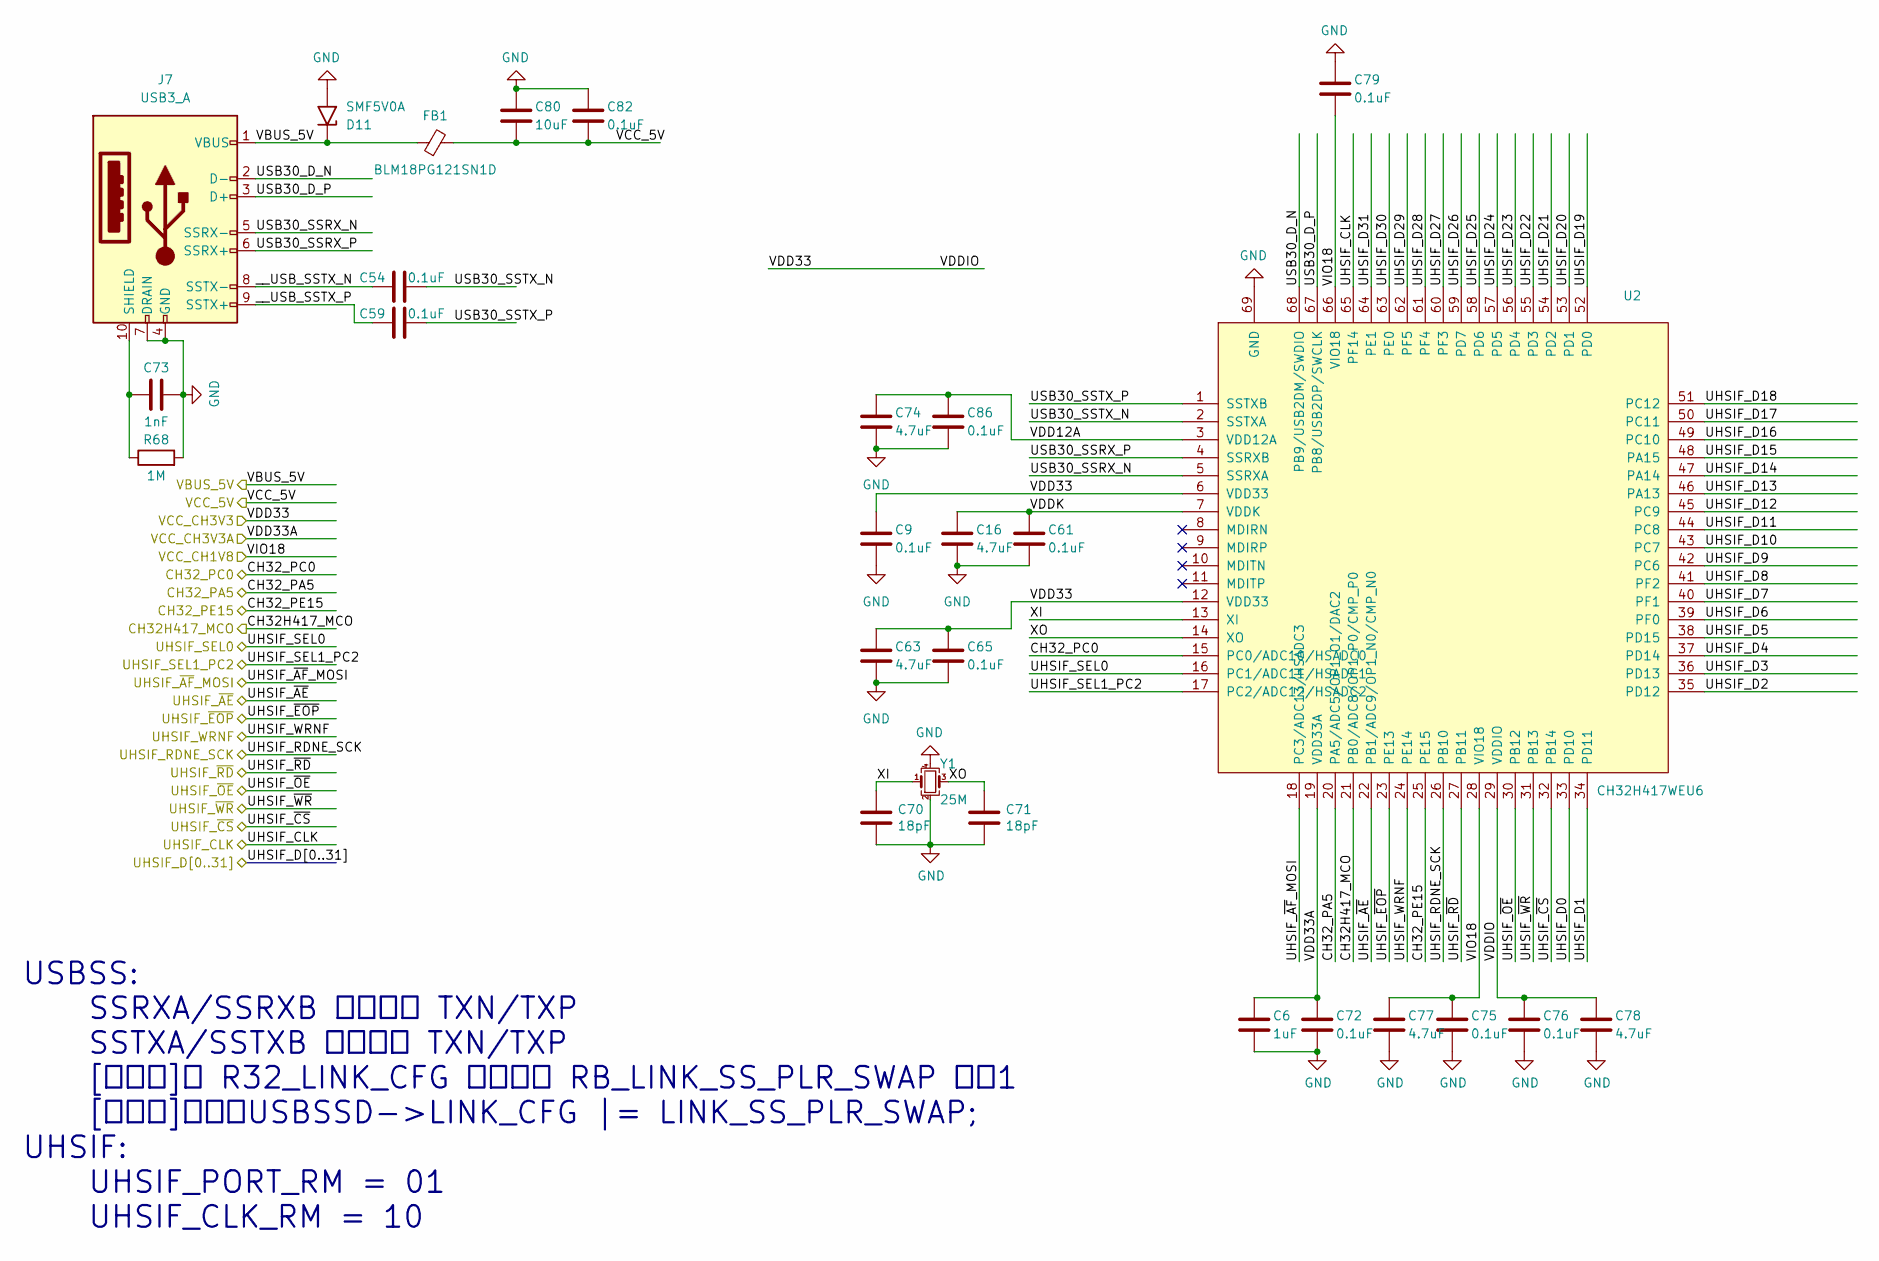
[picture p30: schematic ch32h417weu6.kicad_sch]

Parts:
C6: 1uF; C_0402_1005Metric
C9, C54, C59, C61, C65, C72, C75, C76, C79, C82, C86: 0.1uF; C_0402_1005Metric
C16, C63, C74, C77, C78: 4.7uF; C_0402_1005Metric
C70, C71: 18pF; C_0402_1005Metric
C73: 1nF; C_1206_3216Metric
C80: 10uF; C_0603_1608Metric
D11: SMF5V0A; D_SMF
FB1: BLM18PG121SN1D; L_0603_1608Metric
J7: USB3_A; USB_3.0_AF
R68: 1M; R_0603_1608Metric
U2: CH32H417WEU6; QFN-68-1EP_8x8mm_P0.4mm_EP5.2x5.2mm
Y1: 25M; OSC_3225

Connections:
/CH32H417_MCO: U2.21 (PB0/ADC8/OP1_P0/CMP_P0); also elsewhere on the board
/CH32_PA5: U2.20 (PA5/ADC5/OP1_O1/DAC2); also elsewhere on the board
/CH32_PC0: U2.15 (PC0/ADC10/HSADC0); also elsewhere on the board
/FPGA_CRSTN: U2.25 (PE15); also elsewhere on the board
/UHSIF_CLK: U2.65 (PF14); also elsewhere on the board
/UHSIF_D0: U2.33 (PD10); also elsewhere on the board
/UHSIF_D1: U2.34 (PD11); also elsewhere on the board
/UHSIF_D2: U2.35 (PD12); also elsewhere on the board
/UHSIF_D3: U2.36 (PD13); also elsewhere on the board
/UHSIF_D4: U2.37 (PD14); also elsewhere on the board
/UHSIF_D5: U2.38 (PD15); also elsewhere on the board
/UHSIF_D6: U2.39 (PF0); also elsewhere on the board
/UHSIF_D7: U2.40 (PF1); also elsewhere on the board
/UHSIF_D8: U2.41 (PF2); also elsewhere on the board
/UHSIF_D9: U2.42 (PC6); also elsewhere on the board
/UHSIF_D10: U2.43 (PC7); also elsewhere on the board
/UHSIF_D11: U2.44 (PC8); also elsewhere on the board
/UHSIF_D12: U2.45 (PC9); also elsewhere on the board
/UHSIF_D13: U2.46 (PA13); also elsewhere on the board
/UHSIF_D14: U2.47 (PA14); also elsewhere on the board
/UHSIF_D15: U2.48 (PA15); also elsewhere on the board
/UHSIF_D16: U2.49 (PC10); also elsewhere on the board
/UHSIF_D17: U2.50 (PC11); also elsewhere on the board
/UHSIF_D18: U2.51 (PC12); also elsewhere on the board
/UHSIF_D19: U2.52 (PD0); also elsewhere on the board
/UHSIF_D20: U2.53 (PD1); also elsewhere on the board
/UHSIF_D21: U2.54 (PD2); also elsewhere on the board
/UHSIF_D22: U2.55 (PD3); also elsewhere on the board
/UHSIF_D23: U2.56 (PD4); also elsewhere on the board
/UHSIF_D24: U2.57 (PD5); also elsewhere on the board
/UHSIF_D25: U2.58 (PD6); also elsewhere on the board
/UHSIF_D26: U2.59 (PD7); also elsewhere on the board
/UHSIF_D27: U2.60 (PF3); also elsewhere on the board
/UHSIF_D28: U2.61 (PF4); also elsewhere on the board
/UHSIF_D29: U2.62 (PF5); also elsewhere on the board
/UHSIF_D30: U2.63 (PE0); also elsewhere on the board
/UHSIF_D31: U2.64 (PE1); also elsewhere on the board
/UHSIF_RDNE_SCK: U2.26 (PB10); also elsewhere on the board
/UHSIF_SEL0: U2.16 (PC1/ADC11/HSADC1); also elsewhere on the board
/UHSIF_SEL1_PC2: U2.17 (PC2/ADC12/HSADC2); also elsewhere on the board
/UHSIF_WRNF_CSN: U2.24 (PE14); also elsewhere on the board
/UHSIF_~AE: U2.22 (PB1/ADC9/OP1_N0/CMP_N0); also elsewhere on the board
/UHSIF_~AF_MOSI: U2.18 (PC3/ADC13/HSADC3); also elsewhere on the board
/UHSIF_~CS: U2.32 (PB14); also elsewhere on the board
/UHSIF_~EOP: U2.23 (PE13); also elsewhere on the board
/UHSIF_~OE: U2.30 (PB12); also elsewhere on the board
/UHSIF_~RD: U2.27 (PB11); also elsewhere on the board
/UHSIF_~WR: U2.31 (PB13); also elsewhere on the board
/VBUS_5V: D11.1 (A1), FB1.1, J7.1 (VBUS)
/VCC_3V3: C6.1, C9.1, C63.1, C65.1, C72.1, C76.1, C78.1, U2.6 (VDD33), U2.12 (VDD33), U2.19 (VDD33A), U2.29 (VDDIO); also elsewhere on the board
/VCC_5V: C80.2, C82.2, FB1.2; also elsewhere on the board
/VDDIO_1V8: C75.1, C77.1, C79.2, U2.28 (VIO18), U2.66 (VIO18); also elsewhere on the board
/ch32h417weu6/USB30_D_N: J7.2 (D-), U2.68 (PB9/USB2DM/SWDIO)
/ch32h417weu6/USB30_D_P: J7.3 (D+), U2.67 (PB8/USB2DP/SWCLK)
/ch32h417weu6/USB30_SSRX_N: J7.5 (SSRX-), U2.5 (SSRXA)
/ch32h417weu6/USB30_SSRX_P: J7.6 (SSRX+), U2.4 (SSRXB)
/ch32h417weu6/USB30_SSTX_N: C54.2, U2.2 (SSTXA)
/ch32h417weu6/USB30_SSTX_P: C59.2, U2.1 (SSTXB)
/ch32h417weu6/VDD12A: C74.1, C86.1, U2.3 (VDD12A)
/ch32h417weu6/VDDK: C16.1, C61.1, U2.7 (VDDK)
/ch32h417weu6/XI: C70.2, U2.13 (XI), Y1.1
/ch32h417weu6/XO: C71.2, U2.14 (XO), Y1.3
/ch32h417weu6/__USB_SSTX_N: C54.1, J7.8 (SSTX-)
/ch32h417weu6/__USB_SSTX_P: C59.1, J7.9 (SSTX+)
GND: C6.2, C9.2, C16.2, C61.2, C63.2, C65.2, C70.1, C71.1, C72.2, C73.2, C74.2, C75.2, C76.2, C77.2, C78.2, C79.1, C80.1, C82.1, C86.2, D11.2 (A2), J7.4 (GND), J7.7 (DRAIN), R68.2, U2.69 (GND), Y1.2, Y1.4; also elsewhere on the board
unnamed: C73.1, J7.10 (SHIELD), R68.1

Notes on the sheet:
USBSS: SSRXA/SSRXB 交叉连接 TXN/TXP SSTXA/SSTXB 交叉连接 TXN/TXP [非必要]将 R32_LINK_CFG 寄存器的 RB_LINK_SS_PLR_SWAP 置为1 [非必要]代码：USBSSD->LINK_CFG |= LINK_SS_PLR_SWAP; UHSIF: UHSIF_PORT_RM = 01 UHSIF_CLK_RM = 10

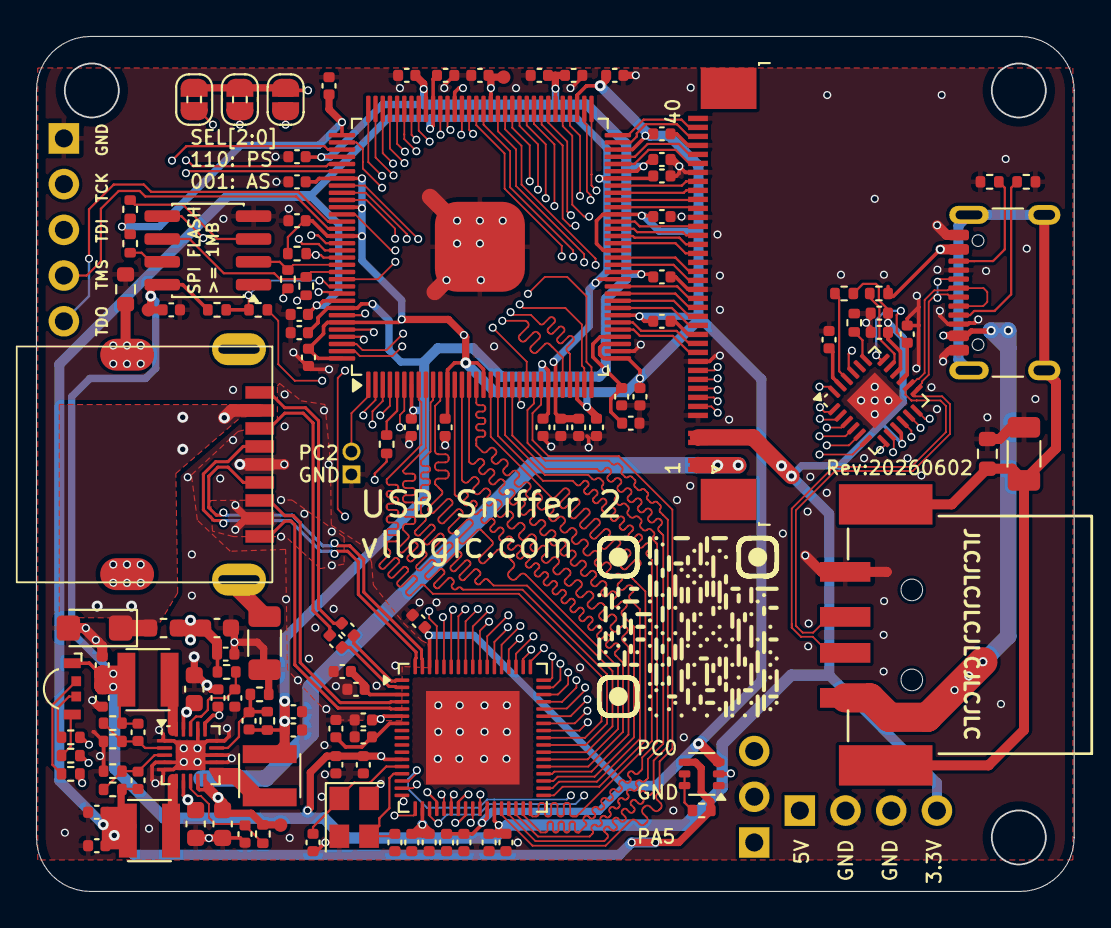
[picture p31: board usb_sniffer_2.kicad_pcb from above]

Board: 4 copper layers, 57.6 x 47.5 mm, 126 parts (0 on the bottom side), 146 nets.

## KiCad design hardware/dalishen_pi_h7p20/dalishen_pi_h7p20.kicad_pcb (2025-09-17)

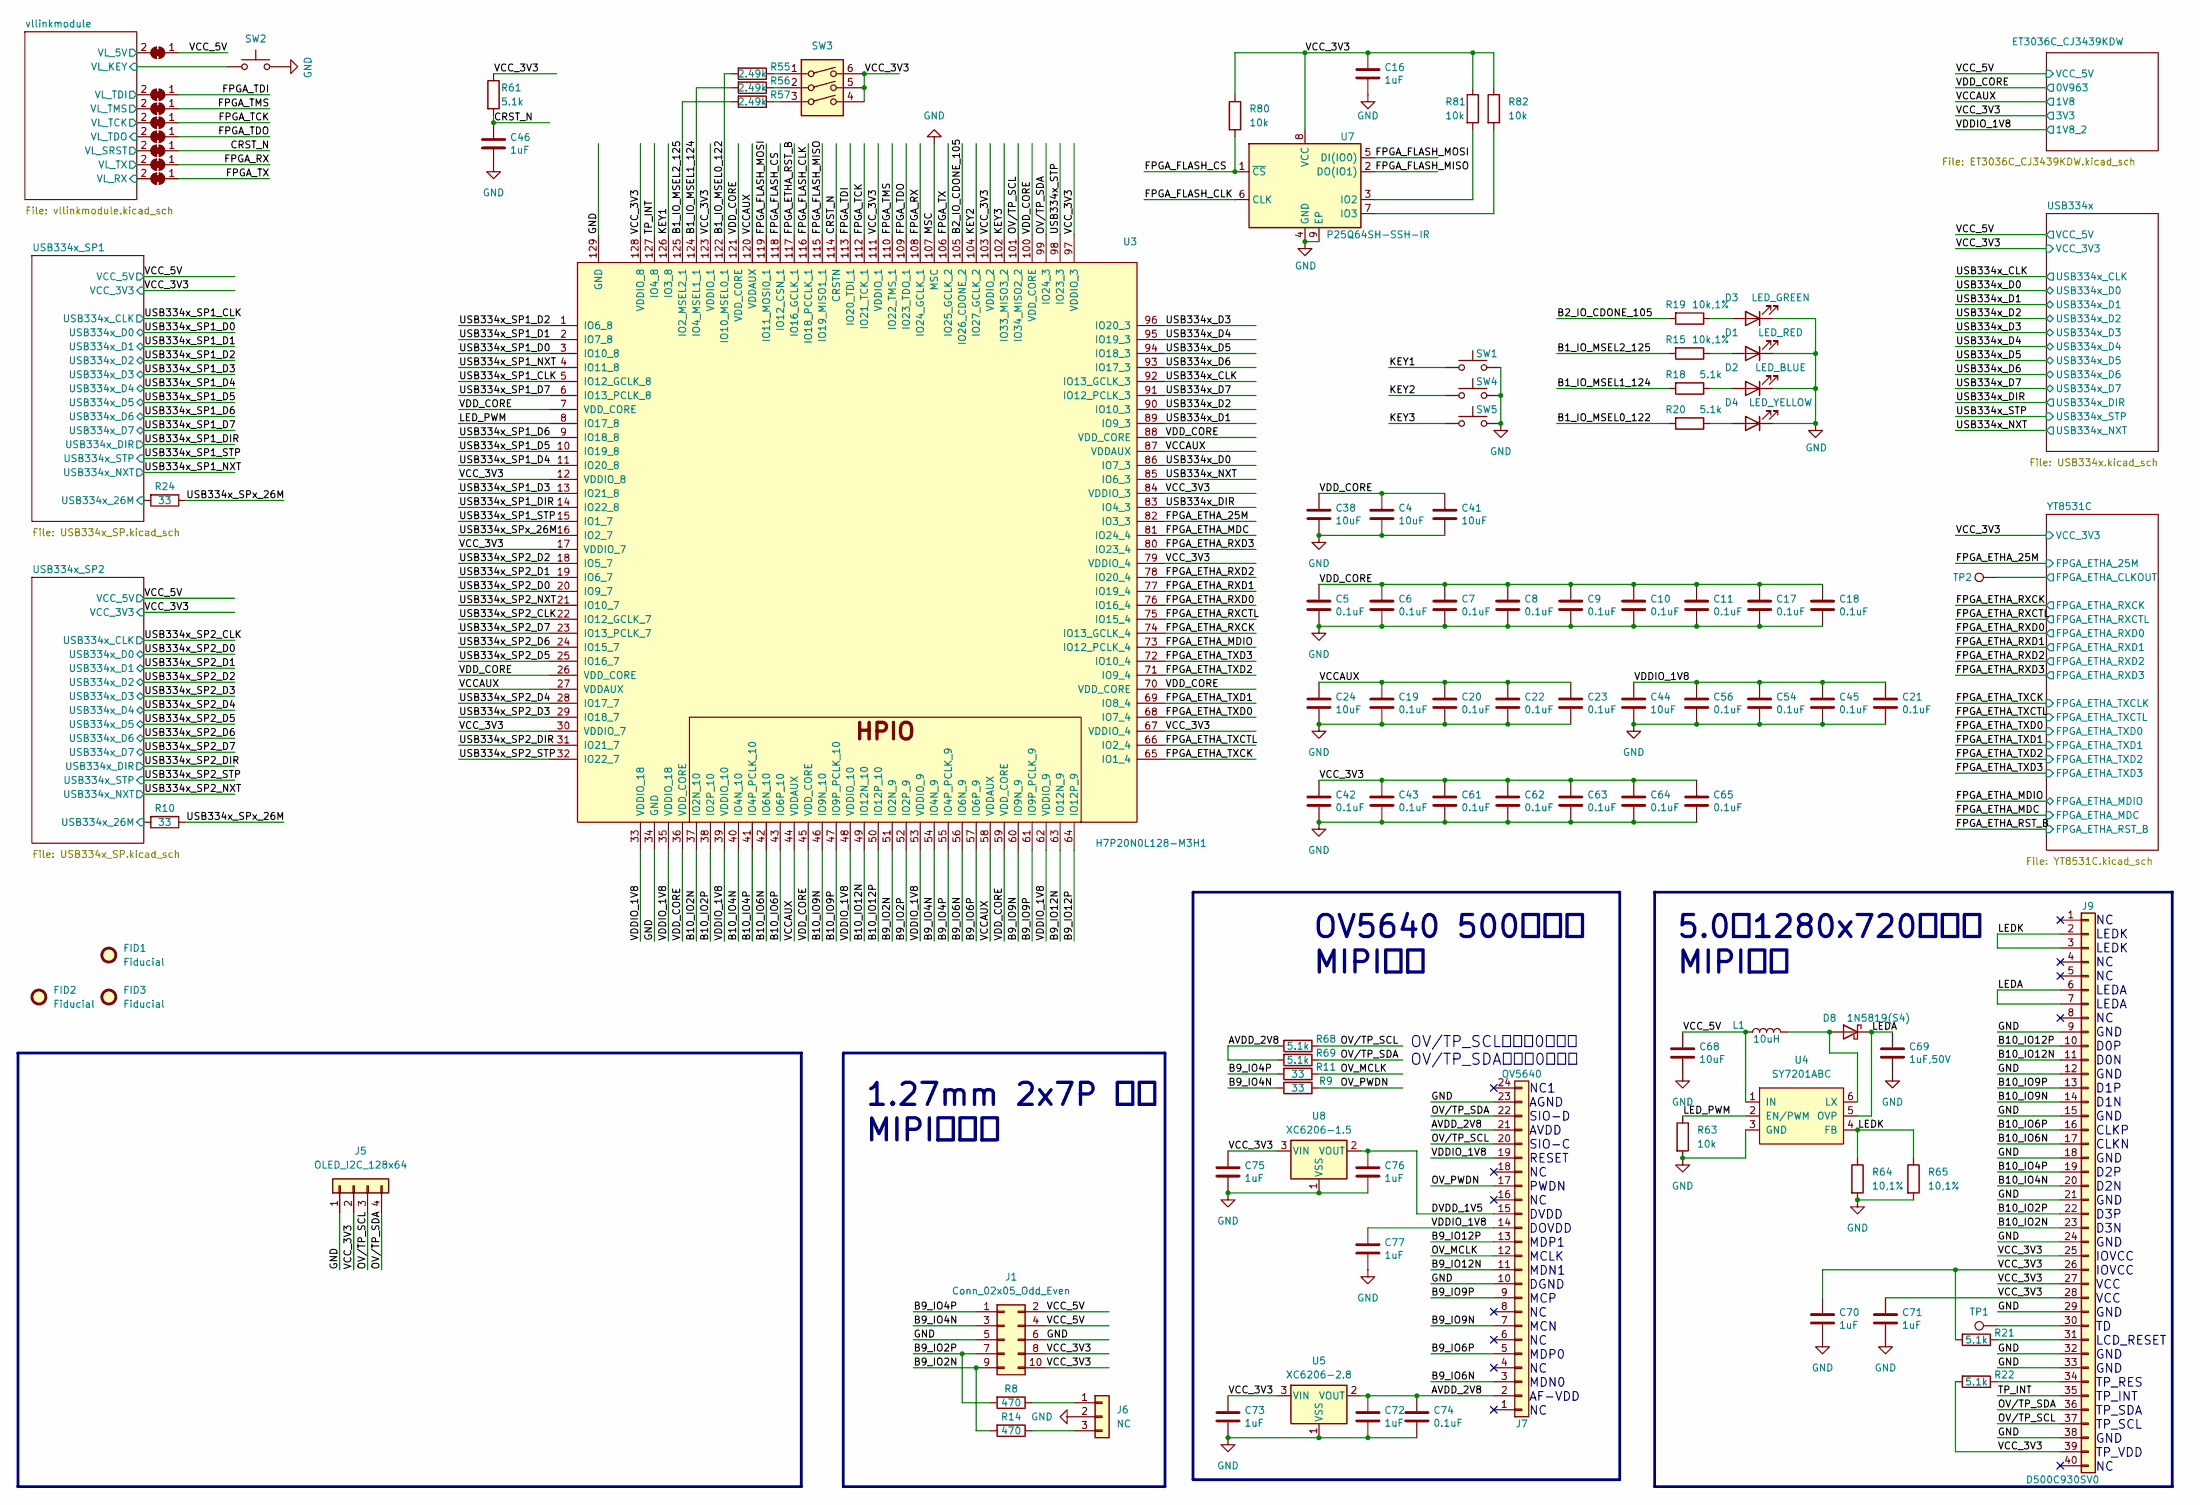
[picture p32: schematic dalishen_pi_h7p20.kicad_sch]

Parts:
C4, C24, C38, C41, C44, C68: 10uF; C_0402_1005Metric
C5, C6, C7, C8, C9, C10, C11, C17, C18, C19, C20, C21, C22, C23, C42, C43, C45, C54, C56, C61, C62, C63, C64, C65, C74: 0.1uF; C_0402_1005Metric
C16, C46, C70, C71, C72, C73, C75, C76, C77: 1uF; C_0402_1005Metric
C69: 1uF,50V; C_0603_1608Metric
D1: LED_RED; LED_0603_1608Metric
D2: LED_BLUE; LED_0603_1608Metric
D3: LED_GREEN; LED_0603_1608Metric
D4: LED_YELLOW; LED_0603_1608Metric
D8: 1N5819(S4); D_SOD-323_BAT60
FID1, FID2, FID3: Fiducial; Fiducial_1mm_Mask2mm
J1: Conn_02x05_Odd_Even; PinHeader_2x05_P1.27mm_Vertical_SMD
J5: OLED_I2C_128x64; PinSocket_1x04_P2.54mm_Vertical
J6: NC; PinHeader_1x03_P2.54mm_Horizontal
J7: OV5640; Hirose_FH12-24S-0.5SH_1x24-1MP_P0.50mm_Horizontal
J9: D500C930SV0; Hirose_FH12-40S-0.5SH_1x40-1MP_P0.50mm_Horizontal
JP2, JP3, JP4, JP5, JP6, JP7, JP8, JP9: SolderJumper_2_Bridged; SolderJumper-2_P1.3mm_Bridged_RoundedPad1.0x1.5mm
L1: 10uH; L_NR3015
R8, R14: 470; R_0402_1005Metric
R9, R10, R11, R24: 33; R_0402_1005Metric
R15, R19: 10k,1%; R_0402_1005Metric
R18, R20, R21, R22, R61, R68, R69: 5.1k; R_0402_1005Metric
R55, R56, R57: 2.49k; R_0402_1005Metric
R63, R80, R81, R82: 10k; R_0402_1005Metric
R64, R65: 10,1%; R_0402_1005Metric
SW1, SW2, SW4, SW5: SW_Push; SW-3x6mm_Hxx_SMD
SW3: SW_DIP_x03; SW_DIP_SPSTx03_Slide_6.7x9.18mm_W8.61mm_P2.54mm_LowProfile
TP1, TP2: TestPoint; PinHeader_1x01_P1.00mm_Vertical
U3: H7P20N0L128-M3H1; LQFP-128_14x14mm_P0.4mm_pad
U4: SY7201ABC; SOT-23-6
U5: XC6206-2.8; SOT-23
U7: P25Q64SH-SSH-IR; SOIC-8_P1.27mm_Common
U8: XC6206-1.5; SOT-23

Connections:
/AVDD_2V8: C72.2, C74.2, J7.2, J7.21, R68.2, R69.2, U5.2 (VOUT)
/B1_IO_MSEL0_122: R20.2, R55.2, U3.122 (IO10_MSEL0_1)
/B1_IO_MSEL1_124: R18.2, R56.2, U3.124 (IO4_MSEL1_1)
/B1_IO_MSEL2_125: R15.2, R57.2, U3.125 (IO2_MSEL2_1)
/B2_IO_CDONE_105: R19.2, U3.105 (IO26_CDONE_2)
/B9_IO2N: J1.9, R14.2, U3.51 (IO2N_9)
/B9_IO2P: J1.7, R8.2, U3.52 (IO2P_9)
/B9_IO4N: J1.3, R9.2, U3.54 (IO4N_9)
/B9_IO4P: J1.1, R11.2, U3.55 (IO4P_PCLK_9)
/B9_IO6N: J7.3, U3.56 (IO6N_9)
/B9_IO6P: J7.5, U3.57 (IO6P_9)
/B9_IO9N: J7.7, U3.60 (IO9N_9)
/B9_IO9P: J7.9, U3.61 (IO9P_PCLK_9)
/B9_IO12N: J7.11, U3.63 (IO12N_9)
/B9_IO12P: J7.13, U3.64 (IO12P_9)
/B10_IO2N: J9.23, U3.37 (IO2N_10)
/B10_IO2P: J9.22, U3.38 (IO2P_10)
/B10_IO4N: J9.20, U3.40 (IO4N_10)
/B10_IO4P: J9.19, U3.41 (IO4P_PCLK_10)
/B10_IO6N: J9.17, U3.42 (IO6N_10)
/B10_IO6P: J9.16, U3.43 (IO6P_10)
/B10_IO9N: J9.14, U3.46 (IO9N_10)
/B10_IO9P: J9.13, U3.47 (IO9P_PCLK_10)
/B10_IO12N: J9.11, U3.49 (IO12N_10)
/B10_IO12P: J9.10, U3.50 (IO12P_10)
/CRST_N: C46.2, JP9.1 (A), R61.2, U3.114 (CRSTN)
/DVDD_1V5: C76.2, J7.15, U8.2 (VOUT)
/FPGA_ETHA_25M: U3.82 (IO3_3); also elsewhere on the board
/FPGA_ETHA_MDC: U3.81 (IO24_4); also elsewhere on the board
/FPGA_ETHA_MDIO: U3.73 (IO12_PCLK_4); also elsewhere on the board
/FPGA_ETHA_RST_B: U3.117 (IO16_GCLK_1); also elsewhere on the board
/FPGA_ETHA_RXCK: U3.74 (IO13_GCLK_4); also elsewhere on the board
/FPGA_ETHA_RXCTL: U3.75 (IO15_4); also elsewhere on the board
/FPGA_ETHA_RXD0: U3.76 (IO16_4); also elsewhere on the board
/FPGA_ETHA_RXD1: U3.77 (IO19_4); also elsewhere on the board
/FPGA_ETHA_RXD2: U3.78 (IO20_4); also elsewhere on the board
/FPGA_ETHA_RXD3: U3.80 (IO23_4); also elsewhere on the board
/FPGA_ETHA_TXCK: U3.65 (IO1_4); also elsewhere on the board
/FPGA_ETHA_TXCTL: U3.66 (IO2_4); also elsewhere on the board
/FPGA_ETHA_TXD0: U3.68 (IO7_4); also elsewhere on the board
/FPGA_ETHA_TXD1: U3.69 (IO8_4); also elsewhere on the board
/FPGA_ETHA_TXD2: U3.71 (IO9_4); also elsewhere on the board
/FPGA_ETHA_TXD3: U3.72 (IO10_4); also elsewhere on the board
/FPGA_FLASH_CLK: U3.116 (IO18_PCCLK_1), U7.6 (CLK)
/FPGA_FLASH_CS: R80.2, U3.118 (IO12_CSN_1), U7.1 (~CS)
/FPGA_FLASH_MISO: U3.115 (IO19_MISO1_1), U7.2 (DO(IO1))
/FPGA_FLASH_MOSI: U3.119 (IO11_MOSI0_1), U7.5 (DI(IO0))
/FPGA_RX: JP7.1 (A), U3.108 (IO24_GCLK_1)
/FPGA_TCK: JP5.1 (A), U3.112 (IO21_TCK_1)
/FPGA_TDI: JP3.1 (A), U3.113 (IO20_TDI_1)
/FPGA_TDO: JP6.1 (A), U3.109 (IO23_TDO_1)
/FPGA_TMS: JP4.1 (A), U3.110 (IO22_TMS_1)
/FPGA_TX: JP8.1 (A), U3.106 (IO25_GCLK_2)
/KEY0: SW1.1, U3.126 (IO3_8)
/KEY1: SW4.1, U3.104 (IO27_GCLK_2)
/KEY2: SW5.1, U3.102 (IO33_MISO3_2)
/LEDA: C69.2, D8.1 (K), J9.6, J9.7, U4.5 (OVP)
/LEDK: J9.2, J9.3, R64.1, R65.1, U4.4 (FB)
/LED_PWM: R63.1, U3.8 (IO17_8), U4.2 (EN/PWM)
/OV_MCLK: J7.12, R11.1
/OV_PWDN: J7.17, R9.1
/OV/TP_SCL: J5.3, J7.20, J9.37, R68.1, U3.101 (IO34_MISO2_2)
/OV/TP_SDA: J5.4, J7.22, J9.36, R69.1, U3.99 (IO24_3)
/TP_INT: J9.35, U3.127 (IO4_8)
/USB334x_CLK: U3.92 (IO13_GCLK_3); also elsewhere on the board
/USB334x_D0: U3.86 (IO7_3); also elsewhere on the board
/USB334x_D1: U3.89 (IO9_3); also elsewhere on the board
/USB334x_D2: U3.90 (IO10_3); also elsewhere on the board
/USB334x_D3: U3.96 (IO20_3); also elsewhere on the board
/USB334x_D4: U3.95 (IO19_3); also elsewhere on the board
/USB334x_D5: U3.94 (IO18_3); also elsewhere on the board
/USB334x_D6: U3.93 (IO17_3); also elsewhere on the board
/USB334x_D7: U3.91 (IO12_PCLK_3); also elsewhere on the board
/USB334x_DIR: U3.83 (IO4_3); also elsewhere on the board
/USB334x_NXT: U3.85 (IO6_3); also elsewhere on the board
/USB334x_SP1/USB334x_26M: R24.2; also elsewhere on the board
/USB334x_SP1_CLK: U3.5 (IO12_GCLK_8); also elsewhere on the board
/USB334x_SP1_D0: U3.3 (IO10_8); also elsewhere on the board
/USB334x_SP1_D1: U3.2 (IO7_8); also elsewhere on the board
/USB334x_SP1_D2: U3.1 (IO6_8); also elsewhere on the board
/USB334x_SP1_D3: U3.13 (IO21_8); also elsewhere on the board
/USB334x_SP1_D4: U3.11 (IO20_8); also elsewhere on the board
/USB334x_SP1_D5: U3.10 (IO19_8); also elsewhere on the board
/USB334x_SP1_D6: U3.9 (IO18_8); also elsewhere on the board
/USB334x_SP1_D7: U3.6 (IO13_PCLK_8); also elsewhere on the board
/USB334x_SP1_DIR: U3.14 (IO22_8); also elsewhere on the board
/USB334x_SP1_NXT: U3.4 (IO11_8); also elsewhere on the board
/USB334x_SP1_STP: U3.15 (IO1_7); also elsewhere on the board
/USB334x_SP2/USB334x_26M: R10.2; also elsewhere on the board
/USB334x_SP2_CLK: U3.22 (IO12_GCLK_7); also elsewhere on the board
/USB334x_SP2_D0: U3.20 (IO9_7); also elsewhere on the board
/USB334x_SP2_D1: U3.19 (IO6_7); also elsewhere on the board
/USB334x_SP2_D2: U3.18 (IO5_7); also elsewhere on the board
/USB334x_SP2_D3: U3.29 (IO18_7); also elsewhere on the board
/USB334x_SP2_D4: U3.28 (IO17_7); also elsewhere on the board
/USB334x_SP2_D5: U3.25 (IO16_7); also elsewhere on the board
/USB334x_SP2_D6: U3.24 (IO15_7); also elsewhere on the board
/USB334x_SP2_D7: U3.23 (IO13_PCLK_7); also elsewhere on the board
/USB334x_SP2_DIR: U3.31 (IO21_7); also elsewhere on the board
/USB334x_SP2_NXT: U3.21 (IO10_7); also elsewhere on the board
/USB334x_SP2_STP: U3.32 (IO22_7); also elsewhere on the board
/USB334x_SPx_26M: R10.1, R24.1, U3.16 (IO2_7)
/USB334x_STP: U3.98 (IO23_3); also elsewhere on the board
/VCCAUX: C19.2, C20.2, C22.2, C23.2, C24.2, U3.27 (VDDAUX), U3.44 (VDDAUX), U3.58 (VDDAUX), U3.87 (VDDAUX), U3.120 (VDDAUX); also elsewhere on the board
/VCC_3V3: C16.2, C42.2, C43.2, C61.2, C62.2, C63.2, C64.2, C65.2, C70.2, C71.2, C73.2, C75.2, J1.8, J1.10, J5.2, J9.25, J9.26, J9.27, J9.28, J9.39, R21.2, R22.2, R61.1, R80.1, R81.1, R82.1, SW3.4, SW3.5, SW3.6, U3.12 (VDDIO_8), U3.17 (VDDIO_7), U3.30 (VDDIO_7), U3.67 (VDDIO_4), U3.79 (VDDIO_4), U3.84 (VDDIO_3), U3.97 (VDDIO_3), U3.103 (VDDIO_2), U3.111 (VDDIO_1), U3.123 (VDDIO_1), U3.128 (VDDIO_8), U5.3 (VIN), U7.8 (VCC), U8.3 (VIN); also elsewhere on the board
/VCC_5V: C68.2, J1.2, J1.4, JP2.1 (A), L1.1, U4.1 (IN); also elsewhere on the board
/VDDIO_1V8: C21.2, C44.2, C45.2, C54.2, C56.2, C77.2, J7.14, J7.19, U3.33 (VDDIO_18), U3.35 (VDDIO_18), U3.39 (VDDIO_10), U3.48 (VDDIO_10), U3.53 (VDDIO_9), U3.62 (VDDIO_9); also elsewhere on the board
/VDD_CORE: C4.2, C5.2, C6.2, C7.2, C8.2, C9.2, C10.2, C11.2, C17.2, C18.2, C38.2, C41.2, U3.7 (VDD_CORE), U3.26 (VDD_CORE), U3.36 (VDD_CORE), U3.45 (VDD_CORE), U3.59 (VDD_CORE), U3.70 (VDD_CORE), U3.88 (VDD_CORE), U3.100 (VDD_CORE), U3.121 (VDD_CORE); also elsewhere on the board
/YT8531C/FPGA_ETHA_CLKOUT: TP2.1; also elsewhere on the board
/vllinkmodule/5V: JP2.2 (B); also elsewhere on the board
/vllinkmodule/GPIOA0: JP5.2 (B); also elsewhere on the board
/vllinkmodule/GPIOA1: JP4.2 (B); also elsewhere on the board
/vllinkmodule/GPIOA2: JP6.2 (B); also elsewhere on the board
/vllinkmodule/GPIOA3: JP3.2 (B); also elsewhere on the board
/vllinkmodule/GPIOA5: SW2.2; also elsewhere on the board
/vllinkmodule/GPIOA6: JP8.2 (B); also elsewhere on the board
/vllinkmodule/GPIOA7: JP7.2 (B); also elsewhere on the board
/vllinkmodule/GPIOB2: JP9.2 (B); also elsewhere on the board
GND: C4.1, C5.1, C6.1, C7.1, C8.1, C9.1, C10.1, C11.1, C16.1, C17.1, C18.1, C19.1, C20.1, C21.1, C22.1, C23.1, C24.1, C38.1, C41.1, C42.1, C43.1, C44.1, C45.1, C46.1, C54.1, C56.1, C61.1, C62.1, C63.1, C64.1, C65.1, C68.1, C69.1, C70.1, C71.1, C72.1, C73.1, C74.1, C75.1, C76.1, C77.1, D1.1 (K), D2.1 (K), D3.1 (K), D4.1 (K), J1.5, J1.6, J5.1, J6.2, J7.10, J7.23, J9.9, J9.12, J9.15, J9.18, J9.21, J9.24, J9.29, J9.32, J9.33, J9.38, R63.2, R64.2, R65.2, SW1.2, SW2.1, SW4.2, SW5.2, U3.34 (GND), U3.107 (MSC), U3.129 (GND), U4.3 (GND), U5.1 (VSS), U7.4 (GND), U7.9 (EP), U8.1 (VSS); also elsewhere on the board
unnamed: D1.2 (A), R15.1
unnamed: D2.2 (A), R18.1
unnamed: D3.2 (A), R19.1
unnamed: D4.2 (A), R20.1
unnamed: D8.2 (A), L1.2, U4.6 (LX)
unnamed: J6.1, R8.1
unnamed: J6.3, R14.1
unnamed: J9.30, TP1.1
unnamed: J9.31, R21.1
unnamed: J9.34, R22.1
unnamed: R55.1, SW3.1
unnamed: R56.1, SW3.2
unnamed: R57.1, SW3.3
unnamed: R81.2, U7.3 (IO2)
unnamed: R82.2, U7.7 (IO3)

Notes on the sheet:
OV5640 500万像素 MIPI接口
NC LEDK LEDK NC NC LEDA LEDA NC GND D0P D0N GND D1P D1N GND CLKP CLKN GND D2P D2N GND D3P D3N GND IOVCC IOVCC VCC VCC GND TD LCD_RESET GND GND TP_RES TP_INT TP_SDA TP_SCL GND TP_VDD NC
NC1 AGND SIO-D AVDD SIO-C RESET NC PWDN NC DVDD DOVDD MDP1 MCLK MDN1 DGND MCP NC MCN NC MDP0 NC MDN0 AF-VDD NC
1.27mm 2x7P 双排 MIPI扩展口
5.0寸1280x720触摸屏 MIPI接口
OV/TP_SCL：可置0或高阻 OV/TP_SDA：可置0或高阻

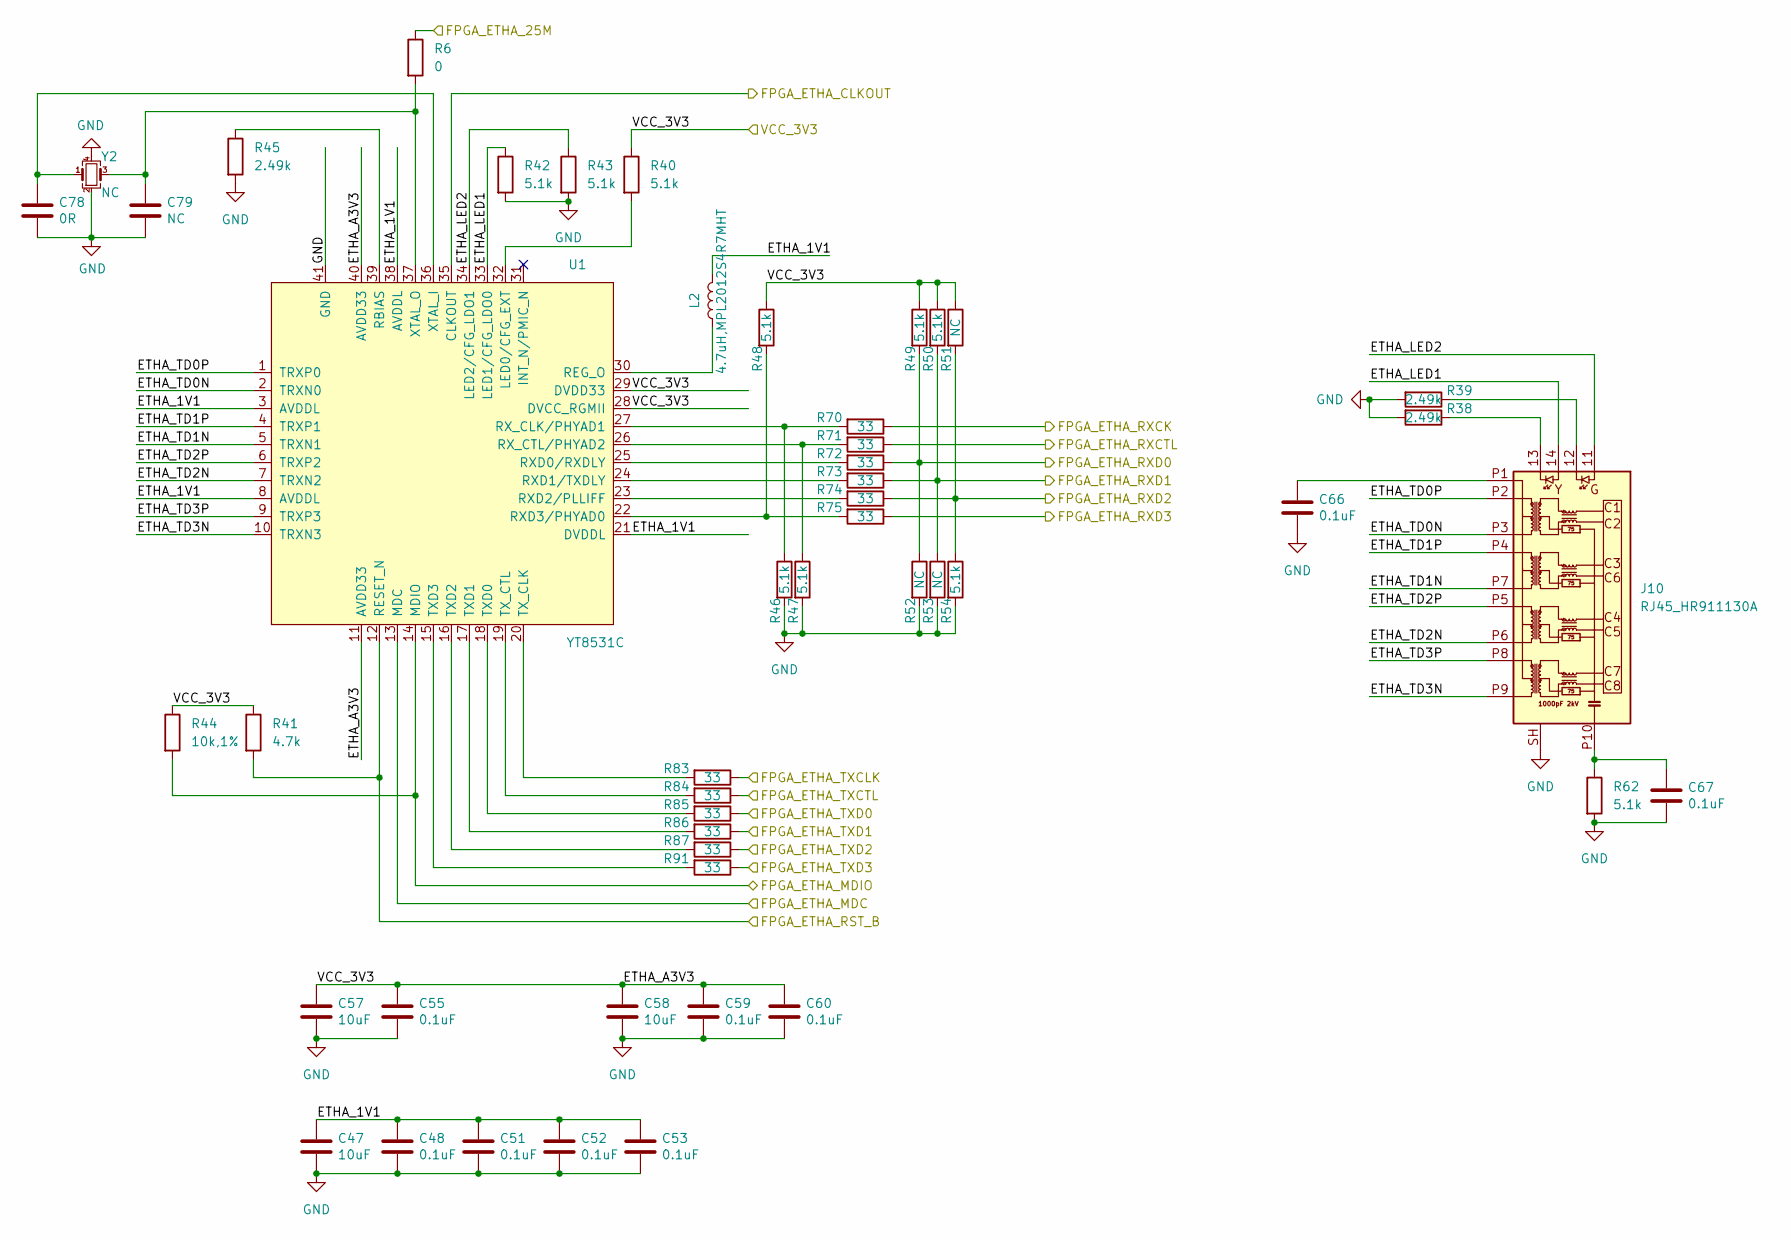
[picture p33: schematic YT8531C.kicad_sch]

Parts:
C47, C57, C58: 10uF; C_0402_1005Metric
C48, C51, C52, C53, C55, C59, C60, C66, C67: 0.1uF; C_0402_1005Metric
C78: 0R; C_0402_1005Metric
C79: NC; C_0402_1005Metric
J10: RJ45_HR911130A
L2: 4.7uH,MPL2012S4R7MHT; L_0805_2012Metric
R6: 0; R_0402_1005Metric
R38, R39, R45: 2.49k; R_0402_1005Metric
R40, R42, R43, R46, R47, R48, R49, R50, R54, R62: 5.1k; R_0402_1005Metric
R41: 4.7k; R_0402_1005Metric
R44: 10k,1%; R_0402_1005Metric
R51, R52, R53: NC; R_0402_1005Metric
R70, R71, R72, R73, R74, R75, R83, R84, R85, R86, R87, R91: 33; R_0402_1005Metric
U1: YT8531C; QFN-40-1EP_5x5mm_P0.4mm_EP3.6x3.6mm
Y2: NC; OSC_3225

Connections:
/FPGA_ETHA_25M: R6.1; also elsewhere on the board
/FPGA_ETHA_MDC: U1.13 (MDC); also elsewhere on the board
/FPGA_ETHA_MDIO: R44.2, U1.14 (MDIO); also elsewhere on the board
/FPGA_ETHA_RST_B: R41.2, U1.12 (RESET_N); also elsewhere on the board
/FPGA_ETHA_RXCK: R70.1; also elsewhere on the board
/FPGA_ETHA_RXCTL: R71.1; also elsewhere on the board
/FPGA_ETHA_RXD0: R49.2, R52.1, R72.1; also elsewhere on the board
/FPGA_ETHA_RXD1: R50.2, R53.1, R73.1; also elsewhere on the board
/FPGA_ETHA_RXD2: R51.2, R54.1, R74.1; also elsewhere on the board
/FPGA_ETHA_RXD3: R75.1; also elsewhere on the board
/FPGA_ETHA_TXCK: R83.1; also elsewhere on the board
/FPGA_ETHA_TXCTL: R84.1; also elsewhere on the board
/FPGA_ETHA_TXD0: R85.1; also elsewhere on the board
/FPGA_ETHA_TXD1: R86.1; also elsewhere on the board
/FPGA_ETHA_TXD2: R87.1; also elsewhere on the board
/FPGA_ETHA_TXD3: R91.1; also elsewhere on the board
/VCC_3V3: C55.2, C57.2, C58.2, C59.2, C60.2, R40.1, R41.1, R44.1, R48.1, R49.1, R50.1, R51.1, U1.11 (AVDD33), U1.28 (DVCC_RGMII), U1.29 (DVDD33), U1.40 (AVDD33); also elsewhere on the board
/YT8531C/ETHA_1V1: C47.2, C48.2, C51.2, C52.2, C53.2, L2.2, U1.3 (AVDDL), U1.8 (AVDDL), U1.21 (DVDDL), U1.38 (AVDDL)
/YT8531C/ETHA_LED1: J10.14, R42.1, U1.33 (LED1/CFG_LDO0)
/YT8531C/ETHA_LED2: J10.11, R43.1, U1.34 (LED2/CFG_LDO1)
/YT8531C/ETHA_TD0N: J10.P3 (TD1-), U1.2 (TRXN0)
/YT8531C/ETHA_TD0P: J10.P2 (TD1+), U1.1 (TRXP0)
/YT8531C/ETHA_TD1N: J10.P7 (TD2-), U1.5 (TRXN1)
/YT8531C/ETHA_TD1P: J10.P4 (TD2+), U1.4 (TRXP1)
/YT8531C/ETHA_TD2N: J10.P6 (TD3-), U1.7 (TRXN2)
/YT8531C/ETHA_TD2P: J10.P5 (TD3+), U1.6 (TRXP2)
/YT8531C/ETHA_TD3N: J10.P9 (TD4-), U1.10 (TRXN3)
/YT8531C/ETHA_TD3P: J10.P8 (TD4+), U1.9 (TRXP3)
/YT8531C/FPGA_ETHA_CLKOUT: U1.35 (CLKOUT); also elsewhere on the board
GND: C47.1, C48.1, C51.1, C52.1, C53.1, C55.1, C57.1, C58.1, C59.1, C60.1, C66.1, C67.1, C78.1, C79.1, J10.SH, R38.2, R39.2, R42.2, R43.2, R45.2, R46.2, R47.2, R52.2, R53.2, R54.2, R62.2, U1.41 (GND), Y2.2, Y2.4; also elsewhere on the board
unnamed: C66.2, J10.P1 (CT)
unnamed: C67.2, J10.P10 (GND), R62.1
unnamed: J10.12, R39.1
unnamed: J10.13, R38.1
unnamed: R40.2, U1.32 (LED0/CFG_EXT)
unnamed: R45.1, U1.39 (RBIAS)
unnamed: L2.1, U1.30 (REG_O)
unnamed: R72.2, U1.25 (RXD0/RXDLY)
unnamed: R73.2, U1.24 (RXD1/TXDLY)
unnamed: R74.2, U1.23 (RXD2/PLLIFF)
unnamed: R48.2, R75.2, U1.22 (RXD3/PHYAD0)
unnamed: R46.1, R70.2, U1.27 (RX_CLK/PHYAD1)
unnamed: R47.1, R71.2, U1.26 (RX_CTL/PHYAD2)
unnamed: R85.2, U1.18 (TXD0)
unnamed: R86.2, U1.17 (TXD1)
unnamed: R87.2, U1.16 (TXD2)
unnamed: R91.2, U1.15 (TXD3)
unnamed: R83.2, U1.20 (TX_CLK)
unnamed: R84.2, U1.19 (TX_CTL)
unnamed: C78.2, U1.36 (XTAL_I), Y2.1
unnamed: C79.2, R6.2, U1.37 (XTAL_O), Y2.3

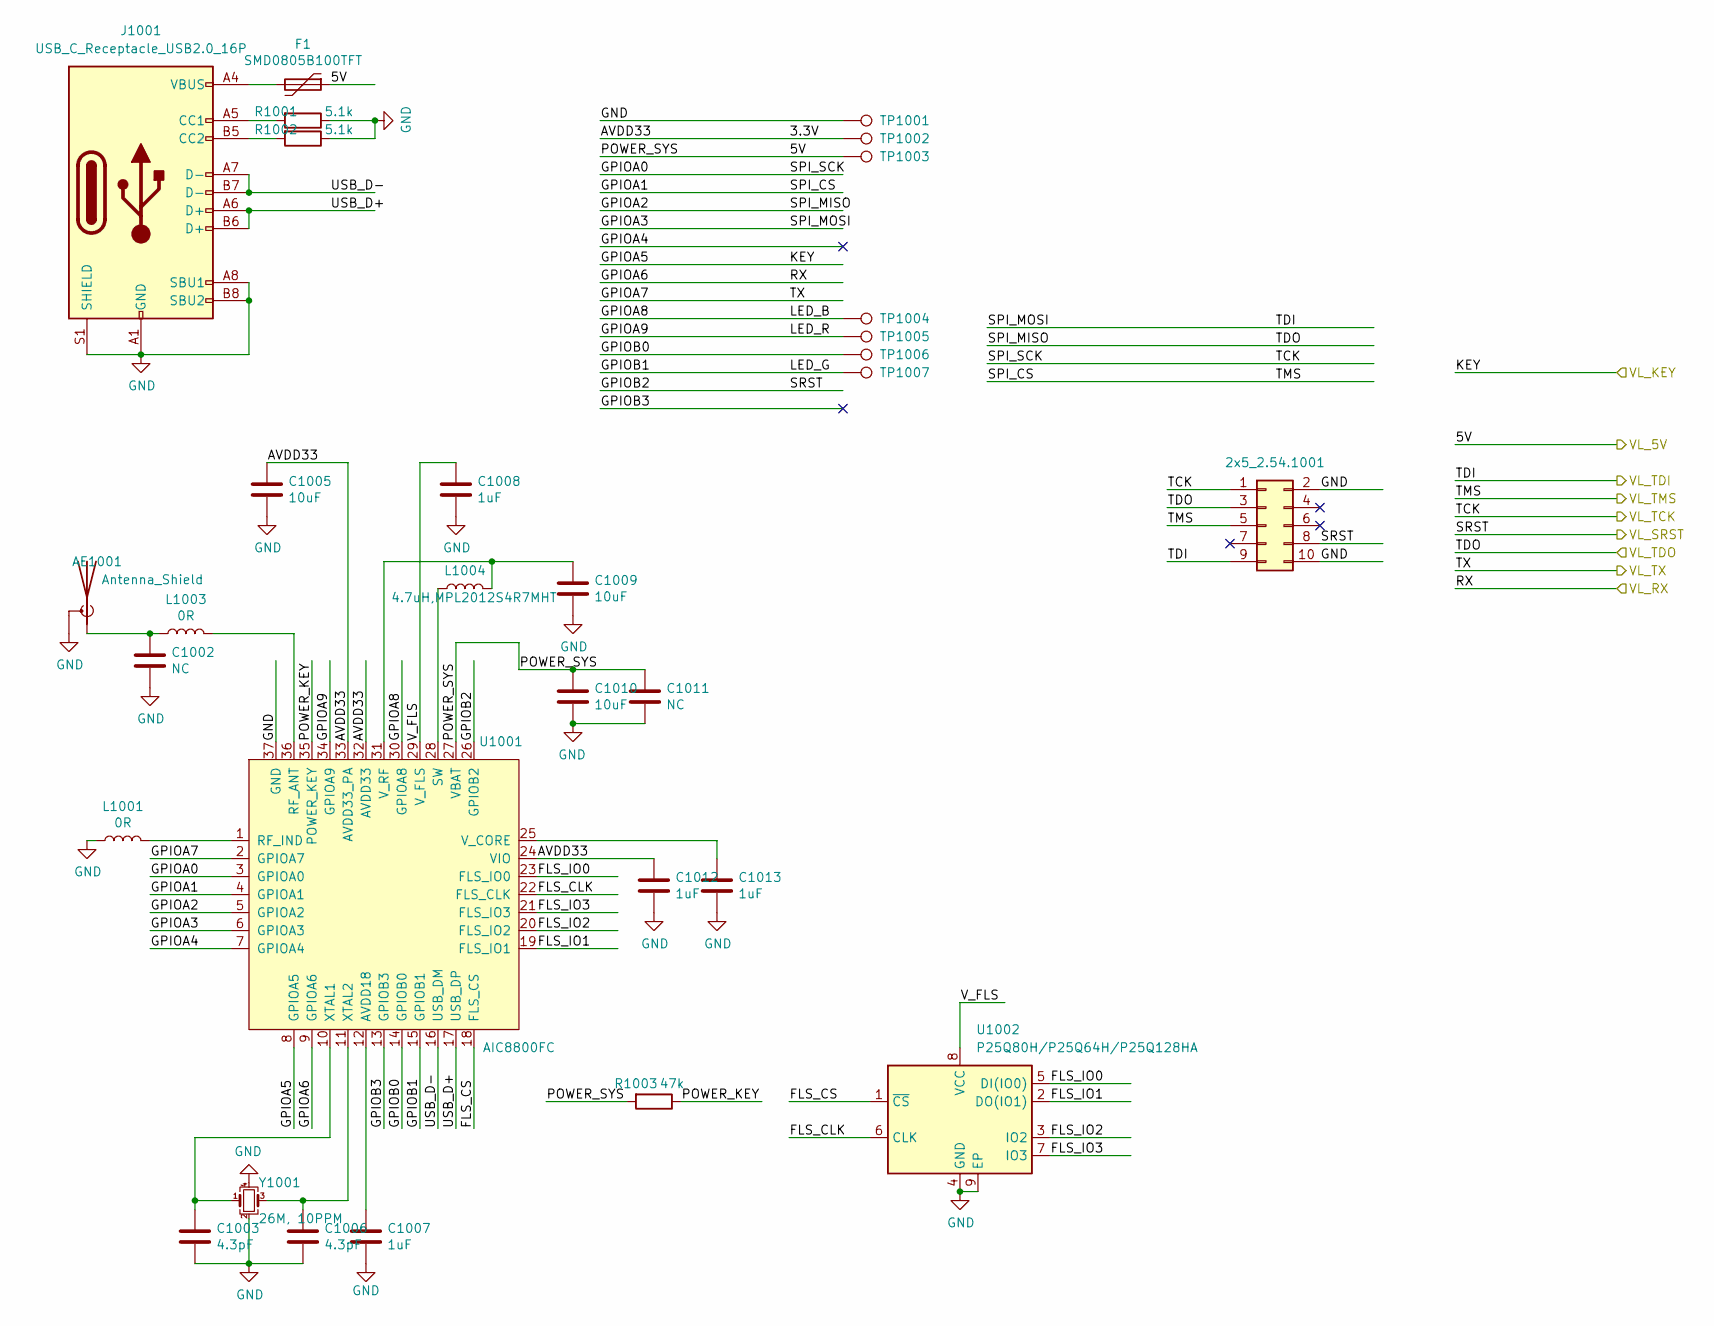
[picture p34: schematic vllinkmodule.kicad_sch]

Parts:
2x5_2.54.1001: NC; IDC-Header_2x05_P2.54mm_Vertical
AE1001: Antenna_Shield; Texas_SWRA117D_2.4GHz_Left
C1002: NC; C_0402_1005Metric
C1003, C1006: 4.3pF; C_0402_1005Metric
C1005, C1009: 10uF; C_0402_1005Metric
C1007, C1008: 1uF; C_0402_1005Metric
C1010: 10uF; C_0402_6mil
C1011: NC; C_0402_6mil
C1012, C1013: 1uF; C_0402_6mil
F1: SMD0805B100TFT; Fuse_0805_2012Metric
J1001: USB_C_Receptacle_USB2.0_16P; USB_C_Receptacle_GCT_USB4105-xx-A_16P_TopMnt_Horizontal
L1001, L1003: 0R; L_0402_1005Metric
L1004: 4.7uH,MPL2012S4R7MHT; L_0805_2012Metric
R1001, R1002: 5.1k; R_0402_1005Metric
R1003: 47k; R_0402_1005Metric
TP1001, TP1002, TP1003, TP1004, TP1005, TP1006, TP1007: TestPoint; TestPoint_Pad_D0.75mm
U1001: AIC8800FC; QFN-36-1EP_4x4mm_P0.35mm_EP2.5x2.5mm
U1002: P25Q80H/P25Q64H/P25Q128HA; USON-8-1EP_3x2mm_P0.5mm_EP1.6x02mm
Y1001: 26M, 10PPM; OSC_2016

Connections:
/vllinkmodule/3.3V: C1005.1, C1012.1, TP1002.1, U1001.24 (VIO), U1001.32 (AVDD33), U1001.33 (AVDD33_PA)
/vllinkmodule/5V: C1010.1, C1011.1, F1.1, R1003.2, TP1003.1, U1001.27 (VBAT); also elsewhere on the board
/vllinkmodule/FLS_CLK: U1001.22 (FLS_CLK), U1002.6 (CLK)
/vllinkmodule/FLS_CS: U1001.18 (FLS_CS), U1002.1 (~CS)
/vllinkmodule/FLS_IO0: U1001.23 (FLS_IO0), U1002.5 (DI(IO0))
/vllinkmodule/FLS_IO1: U1001.19 (FLS_IO1), U1002.2 (DO(IO1))
/vllinkmodule/FLS_IO2: U1001.20 (FLS_IO2), U1002.3 (IO2)
/vllinkmodule/FLS_IO3: U1001.21 (FLS_IO3), U1002.7 (IO3)
/vllinkmodule/GPIOA0: 2x5_2.54.1001.1, U1001.3 (GPIOA0); also elsewhere on the board
/vllinkmodule/GPIOA1: 2x5_2.54.1001.5, U1001.4 (GPIOA1); also elsewhere on the board
/vllinkmodule/GPIOA2: 2x5_2.54.1001.3, U1001.5 (GPIOA2); also elsewhere on the board
/vllinkmodule/GPIOA3: 2x5_2.54.1001.9, U1001.6 (GPIOA3); also elsewhere on the board
/vllinkmodule/GPIOA4: U1001.7 (GPIOA4)
/vllinkmodule/GPIOA5: U1001.8 (GPIOA5); also elsewhere on the board
/vllinkmodule/GPIOA6: U1001.9 (GPIOA6); also elsewhere on the board
/vllinkmodule/GPIOA7: U1001.2 (GPIOA7); also elsewhere on the board
/vllinkmodule/GPIOA8: TP1004.1, U1001.30 (GPIOA8)
/vllinkmodule/GPIOA9: TP1005.1, U1001.34 (GPIOA9)
/vllinkmodule/GPIOB0: TP1006.1, U1001.14 (GPIOB0)
/vllinkmodule/GPIOB1: TP1007.1, U1001.15 (GPIOB1)
/vllinkmodule/GPIOB2: 2x5_2.54.1001.8, U1001.26 (GPIOB2); also elsewhere on the board
/vllinkmodule/GPIOB3: U1001.13 (GPIOB3)
/vllinkmodule/POWER_KEY: R1003.1, U1001.35 (POWER_KEY)
/vllinkmodule/USB_D+: J1001.A6 (D+), J1001.B6 (D+), U1001.17 (USB_DP)
/vllinkmodule/USB_D-: J1001.A7 (D-), J1001.B7 (D-), U1001.16 (USB_DM)
/vllinkmodule/V_FLS: C1008.1, U1001.29 (V_FLS), U1002.8 (VCC)
GND: 2x5_2.54.1001.2, 2x5_2.54.1001.10, AE1001.2 (Shield), C1002.2, C1003.1, C1005.2, C1006.1, C1007.1, C1008.2, C1009.2, C1010.2, C1011.2, C1012.2, C1013.2, J1001.A1 (GND), J1001.A8 (SBU1), J1001.A12 (GND), J1001.B1 (GND), J1001.B8 (SBU2), J1001.B12 (GND), J1001.S1 (SHIELD), L1001.1, R1001.1, R1002.1, TP1001.1, U1001.37 (GND), U1002.4 (GND), U1002.9 (EP), Y1001.2, Y1001.4; also elsewhere on the board
unnamed: AE1001.1 (A), C1002.1, L1003.1
unnamed: F1.2, J1001.A4 (VBUS), J1001.A9 (VBUS), J1001.B4 (VBUS), J1001.B9 (VBUS)
unnamed: J1001.A5 (CC1), R1001.2
unnamed: J1001.B5 (CC2), R1002.2
unnamed: C1007.2, U1001.12 (AVDD18)
unnamed: L1003.2, U1001.36 (RF_ANT)
unnamed: L1001.2, U1001.1 (RF_IND)
unnamed: L1004.1, U1001.28 (SW)
unnamed: C1013.1, U1001.25 (V_CORE)
unnamed: C1009.1, L1004.2, U1001.31 (V_RF)
unnamed: C1003.2, U1001.10 (XTAL1), Y1001.1
unnamed: C1006.2, U1001.11 (XTAL2), Y1001.3

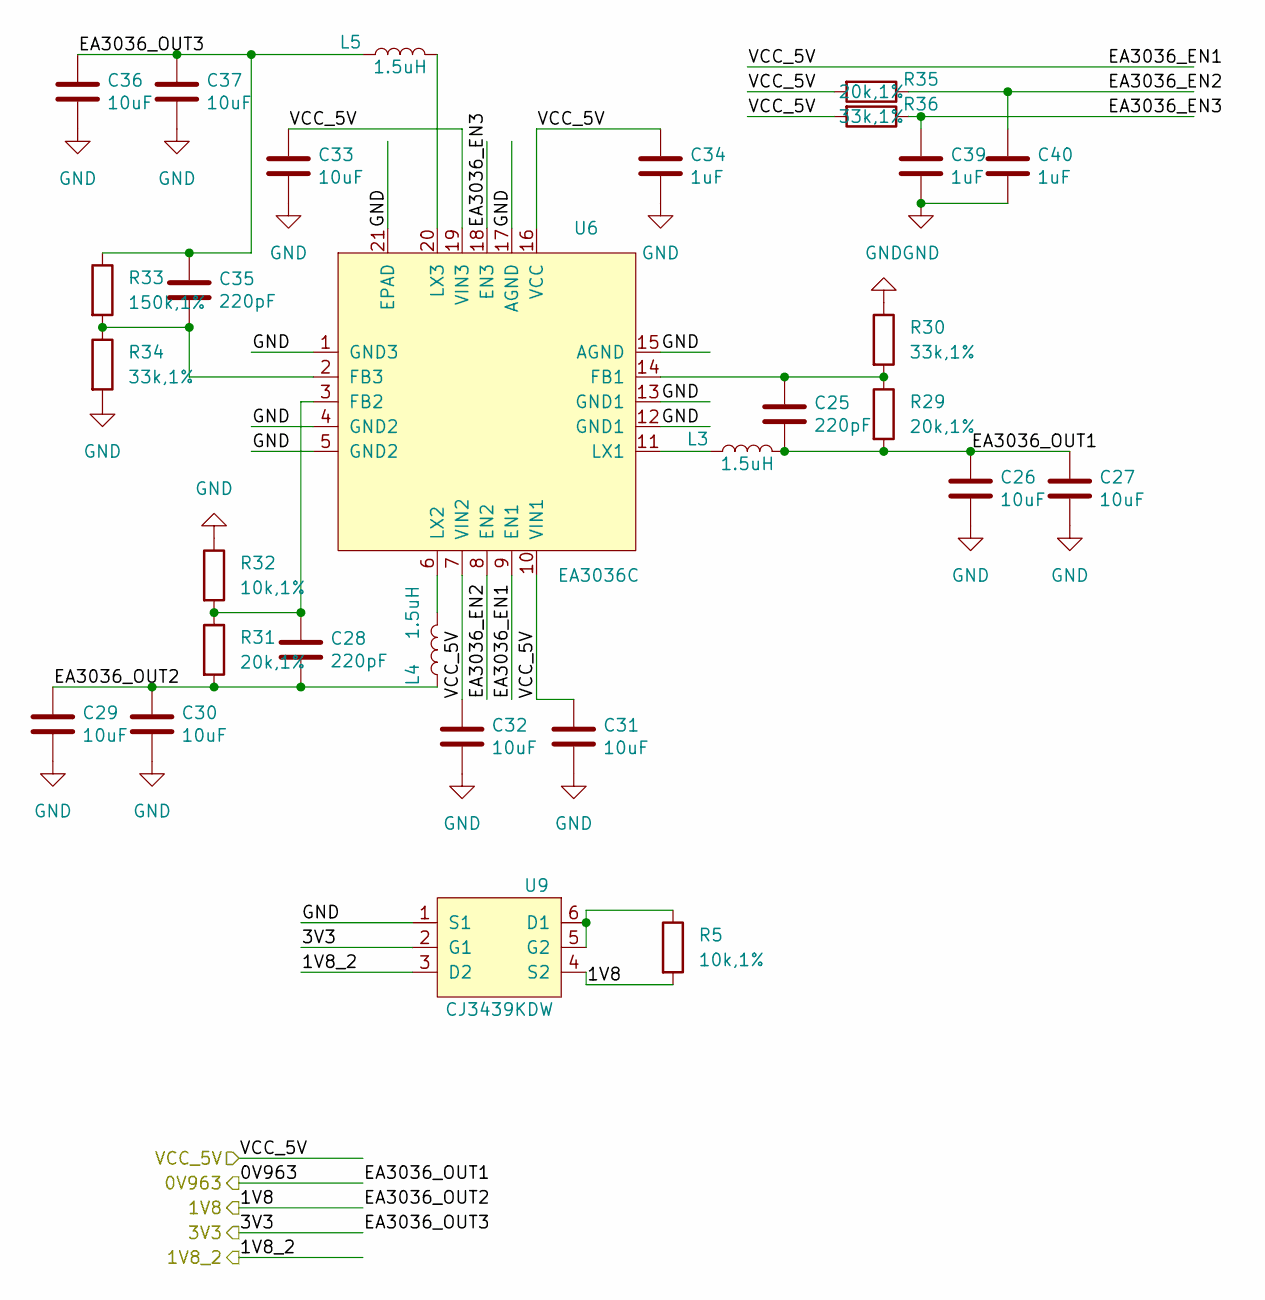
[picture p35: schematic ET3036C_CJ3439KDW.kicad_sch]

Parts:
C25, C28, C35: 220pF; C_0402_1005Metric
C26, C27, C29, C30, C31, C32, C33, C36, C37: 10uF; C_0402_1005Metric
C34, C39, C40: 1uF; C_0402_1005Metric
L3, L4, L5: 1.5uH; L_NR2520xx
R5, R32: 10k,1%; R_0402_1005Metric
R29, R31, R35: 20k,1%; R_0402_1005Metric
R30, R34, R36: 33k,1%; R_0402_1005Metric
R33: 150k,1%; R_0402_1005Metric
U6: EA3036C; QFN-20-1EP_3x3mm_P0.4mm_EP1.65x1.65mm
U9: CJ3439KDW; SOT-363_SC-70-6

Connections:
/ET3036C_CJ3439KDW/EA3036_EN2: C40.2, R35.1, U6.8 (EN2)
/ET3036C_CJ3439KDW/EA3036_EN3: C39.2, R36.1, U6.18 (EN3)
/VCCAUX: C28.1, C29.2, C30.2, L4.1, R5.2, R31.2, U9.4 (S2); also elsewhere on the board
/VCC_3V3: C35.2, C36.2, C37.2, L5.1, R33.1, U9.2 (G1); also elsewhere on the board
/VCC_5V: C31.2, C32.2, C33.2, C34.2, R35.2, R36.2, U6.7 (VIN2), U6.9 (EN1), U6.10 (VIN1), U6.16 (VCC), U6.19 (VIN3); also elsewhere on the board
/VDDIO_1V8: U9.3 (D2); also elsewhere on the board
/VDD_CORE: C25.1, C26.2, C27.2, L3.2, R29.2; also elsewhere on the board
GND: C26.1, C27.1, C29.1, C30.1, C31.1, C32.1, C33.1, C34.1, C36.1, C37.1, C39.1, C40.1, R30.1, R32.1, R34.2, U6.1 (GND3), U6.4 (GND2), U6.5 (GND2), U6.12 (GND1), U6.13 (GND1), U6.15 (AGND), U6.17 (AGND), U6.21 (EPAD), U9.1 (S1); also elsewhere on the board
unnamed: C25.2, R29.1, R30.2, U6.14 (FB1)
unnamed: C28.2, R31.1, R32.2, U6.3 (FB2)
unnamed: C35.1, R33.2, R34.1, U6.2 (FB3)
unnamed: L3.1, U6.11 (LX1)
unnamed: L4.2, U6.6 (LX2)
unnamed: L5.2, U6.20 (LX3)
unnamed: R5.1, U9.5 (G2), U9.6 (D1)

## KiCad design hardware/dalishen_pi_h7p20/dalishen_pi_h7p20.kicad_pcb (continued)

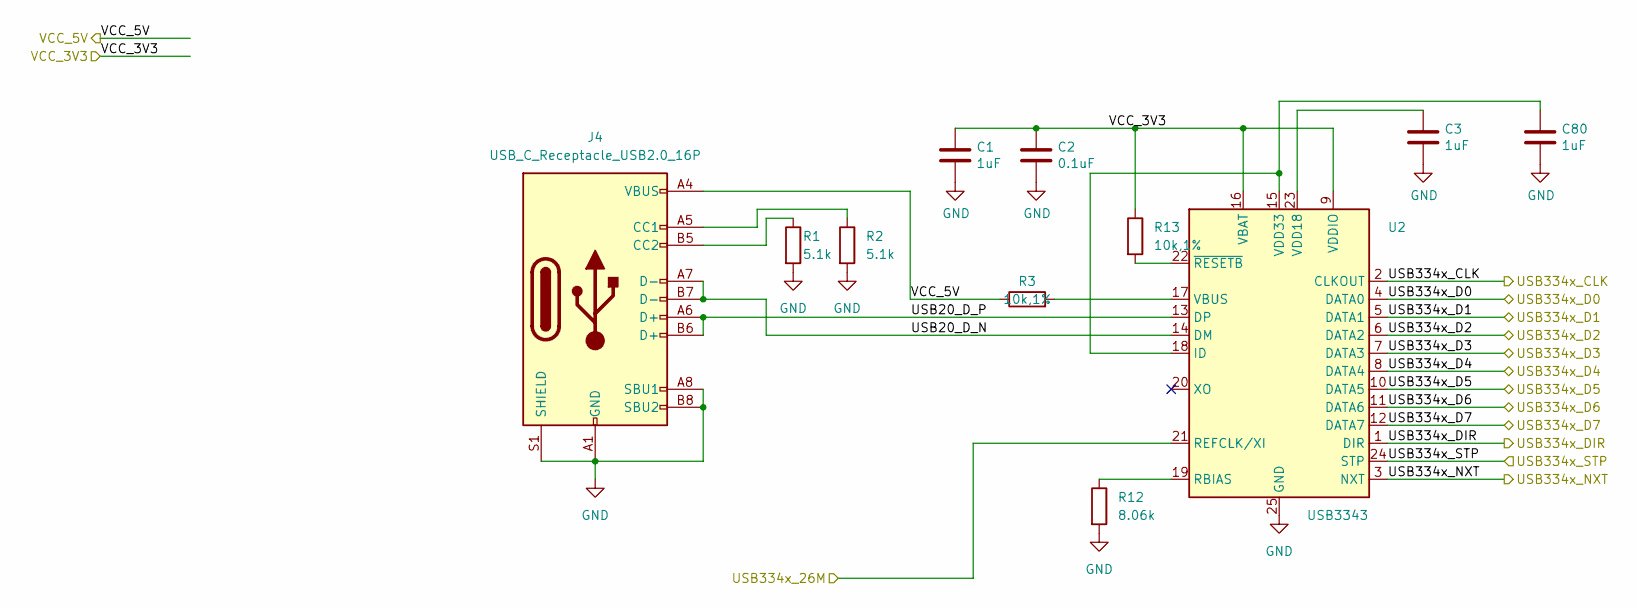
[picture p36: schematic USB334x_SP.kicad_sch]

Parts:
C1, C3, C80: 1uF; C_0402_1005Metric
C2: 0.1uF; C_0402_1005Metric
J4: USB_C_Receptacle_USB2.0_16P; USB_C_Receptacle_16P
R1, R2: 5.1k; R_0402_1005Metric
R3, R13: 10k,1%; R_0402_1005Metric
R12: 8.06k; R_0402_1005Metric
U2: USB3343; QFN-24-1EP_4x4mm_P0.5mm_EP2.6x2.6mm

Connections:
/USB334x_SP1/USB20_D_N: J4.A7 (D-), J4.B7 (D-), U2.14 (DM)
/USB334x_SP1/USB20_D_P: J4.A6 (D+), J4.B6 (D+), U2.13 (DP)
/USB334x_SP1/USB334x_26M: U2.21 (REFCLK/XI); also elsewhere on the board
/USB334x_SP1_CLK: U2.2 (CLKOUT); also elsewhere on the board
/USB334x_SP1_D0: U2.4 (DATA0); also elsewhere on the board
/USB334x_SP1_D1: U2.5 (DATA1); also elsewhere on the board
/USB334x_SP1_D2: U2.6 (DATA2); also elsewhere on the board
/USB334x_SP1_D3: U2.7 (DATA3); also elsewhere on the board
/USB334x_SP1_D4: U2.8 (DATA4); also elsewhere on the board
/USB334x_SP1_D5: U2.10 (DATA5); also elsewhere on the board
/USB334x_SP1_D6: U2.11 (DATA6); also elsewhere on the board
/USB334x_SP1_D7: U2.12 (DATA7); also elsewhere on the board
/USB334x_SP1_DIR: U2.1 (DIR); also elsewhere on the board
/USB334x_SP1_NXT: U2.3 (NXT); also elsewhere on the board
/USB334x_SP1_STP: U2.24 (STP); also elsewhere on the board
/VCC_3V3: C1.2, C2.2, R13.1, U2.9 (VDDIO), U2.16 (VBAT); also elsewhere on the board
/VCC_5V: J4.A4 (VBUS), J4.A9 (VBUS), J4.B4 (VBUS), J4.B9 (VBUS), R3.1; also elsewhere on the board
GND: C1.1, C2.1, C3.1, C80.1, J4.A1 (GND), J4.A8 (SBU1), J4.A12 (GND), J4.B1 (GND), J4.B8 (SBU2), J4.B12 (GND), J4.S1 (SHIELD), R1.2, R2.2, R12.2, U2.25 (GND); also elsewhere on the board
unnamed: J4.A5 (CC1), R2.1
unnamed: J4.B5 (CC2), R1.1
unnamed: C80.2, U2.15 (VDD33), U2.18 (ID)
unnamed: R12.1, U2.19 (RBIAS)
unnamed: R3.2, U2.17 (VBUS)
unnamed: C3.2, U2.23 (VDD18)
unnamed: R13.2, U2.22 (~RESETB)

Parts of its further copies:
C81, C83, C84: 1uF; C_0402_1005Metric
C82: 0.1uF; C_0402_1005Metric
J8: USB_C_Receptacle_USB2.0_16P; USB_C_Receptacle_16P
R16, R17: 5.1k; R_0402_1005Metric
R23, R26: 10k,1%; R_0402_1005Metric
R25: 8.06k; R_0402_1005Metric
U10: USB3343; QFN-24-1EP_4x4mm_P0.5mm_EP2.6x2.6mm

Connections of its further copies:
/USB334x_SP2/USB20_D_N: J8.A7 (D-), J8.B7 (D-), U10.14 (DM)
/USB334x_SP2/USB20_D_P: J8.A6 (D+), J8.B6 (D+), U10.13 (DP)
/USB334x_SP2/USB334x_26M: U10.21 (REFCLK/XI); also elsewhere on the board
/USB334x_SP2_CLK: U10.2 (CLKOUT); also elsewhere on the board
/USB334x_SP2_D0: U10.4 (DATA0); also elsewhere on the board
/USB334x_SP2_D1: U10.5 (DATA1); also elsewhere on the board
/USB334x_SP2_D2: U10.6 (DATA2); also elsewhere on the board
/USB334x_SP2_D3: U10.7 (DATA3); also elsewhere on the board
/USB334x_SP2_D4: U10.8 (DATA4); also elsewhere on the board
/USB334x_SP2_D5: U10.10 (DATA5); also elsewhere on the board
/USB334x_SP2_D6: U10.11 (DATA6); also elsewhere on the board
/USB334x_SP2_D7: U10.12 (DATA7); also elsewhere on the board
/USB334x_SP2_DIR: U10.1 (DIR); also elsewhere on the board
/USB334x_SP2_NXT: U10.3 (NXT); also elsewhere on the board
/USB334x_SP2_STP: U10.24 (STP); also elsewhere on the board
/VCC_3V3: C81.2, C82.2, R26.1, U10.9 (VDDIO), U10.16 (VBAT); also elsewhere on the board
/VCC_5V: J8.A4 (VBUS), J8.A9 (VBUS), J8.B4 (VBUS), J8.B9 (VBUS), R23.1; also elsewhere on the board
GND: C81.1, C82.1, C83.1, C84.1, J8.A1 (GND), J8.A8 (SBU1), J8.A12 (GND), J8.B1 (GND), J8.B8 (SBU2), J8.B12 (GND), J8.S1 (SHIELD), R16.2, R17.2, R25.2, U10.25 (GND); also elsewhere on the board
unnamed: J8.A5 (CC1), R17.1
unnamed: J8.B5 (CC2), R16.1
unnamed: C84.2, U10.15 (VDD33), U10.18 (ID)
unnamed: R25.1, U10.19 (RBIAS)
unnamed: R23.2, U10.17 (VBUS)
unnamed: C83.2, U10.23 (VDD18)
unnamed: R26.2, U10.22 (~RESETB)

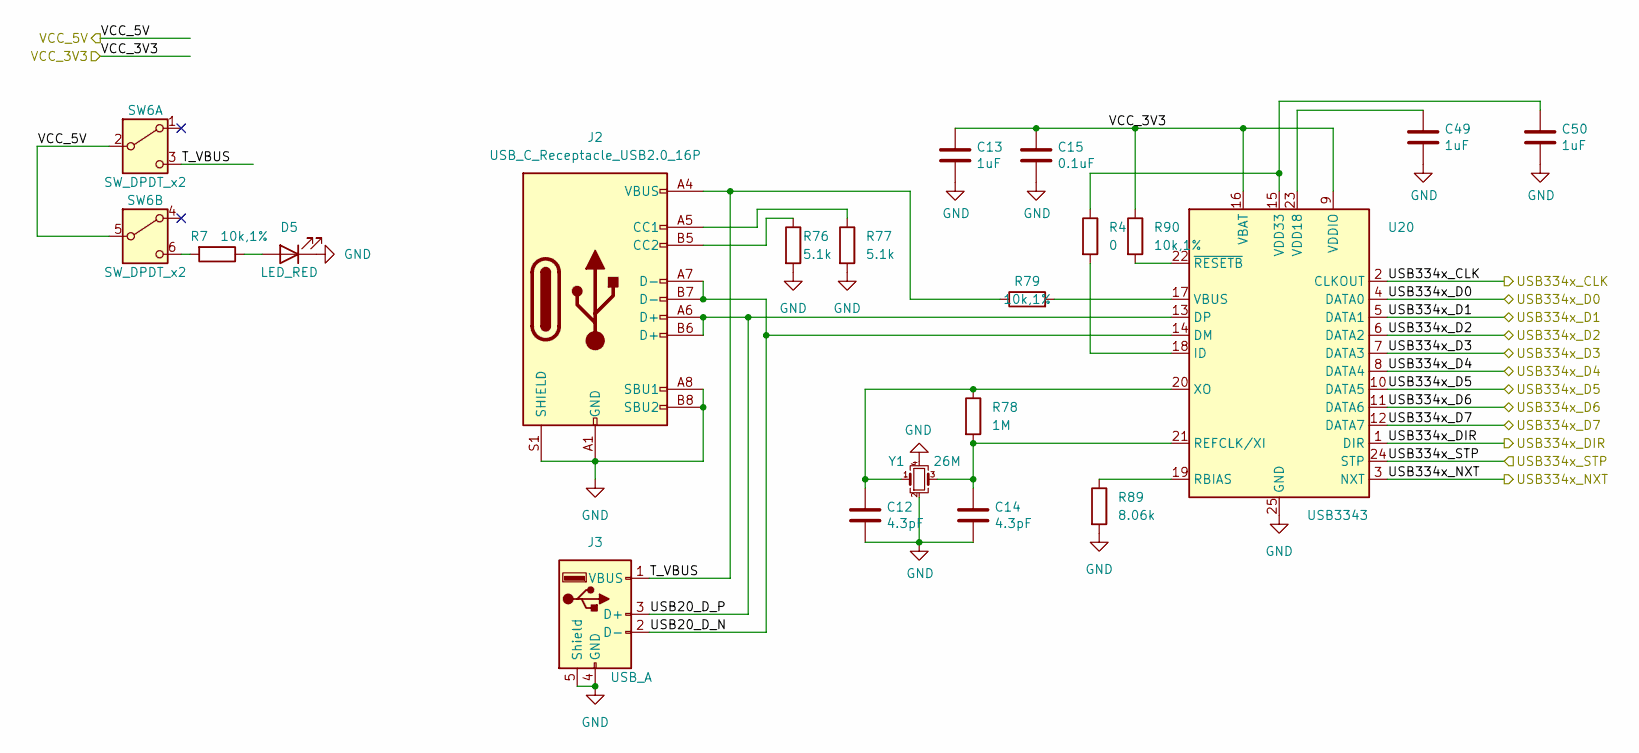
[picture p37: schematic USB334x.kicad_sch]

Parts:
C12, C14: 4.3pF; C_0402_6mil
C13, C49, C50: 1uF; C_0402_1005Metric
C15: 0.1uF; C_0402_1005Metric
D5: LED_RED; LED_0603_1608Metric
J2: USB_C_Receptacle_USB2.0_16P; USB_C_Receptacle_16P
J3: USB_A; USB_AF_SMT
R4: 0; R_0402_1005Metric
R7, R79, R90: 10k,1%; R_0402_1005Metric
R76, R77: 5.1k; R_0402_1005Metric
R78: 1M; R_0402_1005Metric
R89: 8.06k; R_0402_1005Metric
SW6: SW_DPDT_x2
U20: USB3343; QFN-24-1EP_4x4mm_P0.5mm_EP2.6x2.6mm
Y1: 26M; OSC_2016

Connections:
/USB334x/T_VBUS: J2.A4 (VBUS), J2.A9 (VBUS), J2.B4 (VBUS), J2.B9 (VBUS), J3.1 (VBUS), R79.1, SW6.3 (C)
/USB334x/USB20_D_N: J2.A7 (D-), J2.B7 (D-), J3.2 (D-), U20.14 (DM)
/USB334x/USB20_D_P: J2.A6 (D+), J2.B6 (D+), J3.3 (D+), U20.13 (DP)
/USB334x_CLK: U20.2 (CLKOUT); also elsewhere on the board
/USB334x_D0: U20.4 (DATA0); also elsewhere on the board
/USB334x_D1: U20.5 (DATA1); also elsewhere on the board
/USB334x_D2: U20.6 (DATA2); also elsewhere on the board
/USB334x_D3: U20.7 (DATA3); also elsewhere on the board
/USB334x_D4: U20.8 (DATA4); also elsewhere on the board
/USB334x_D5: U20.10 (DATA5); also elsewhere on the board
/USB334x_D6: U20.11 (DATA6); also elsewhere on the board
/USB334x_D7: U20.12 (DATA7); also elsewhere on the board
/USB334x_DIR: U20.1 (DIR); also elsewhere on the board
/USB334x_NXT: U20.3 (NXT); also elsewhere on the board
/USB334x_STP: U20.24 (STP); also elsewhere on the board
/VCC_3V3: C13.2, C15.2, R90.1, U20.9 (VDDIO), U20.16 (VBAT); also elsewhere on the board
GND: C12.1, C13.1, C14.1, C15.1, C49.1, C50.1, D5.1 (K), J2.A1 (GND), J2.A8 (SBU1), J2.A12 (GND), J2.B1 (GND), J2.B8 (SBU2), J2.B12 (GND), J2.S1 (SHIELD), J3.4 (GND), J3.5 (Shield), R76.2, R77.2, R89.2, U20.25 (GND), Y1.2, Y1.4; also elsewhere on the board
unnamed: D5.2 (A), R7.1
unnamed: J2.A5 (CC1), R77.1
unnamed: J2.B5 (CC2), R76.1
unnamed: SW6.2 (B), SW6.5 (B)
unnamed: R7.2, SW6.6 (C)
unnamed: R4.2, U20.18 (ID)
unnamed: R89.1, U20.19 (RBIAS)
unnamed: C14.2, R78.2, U20.21 (REFCLK/XI), Y1.3
unnamed: R79.2, U20.17 (VBUS)
unnamed: C49.2, U20.23 (VDD18)
unnamed: C50.2, R4.1, U20.15 (VDD33)
unnamed: C12.2, R78.1, U20.20 (XO), Y1.1
unnamed: R90.2, U20.22 (~RESETB)

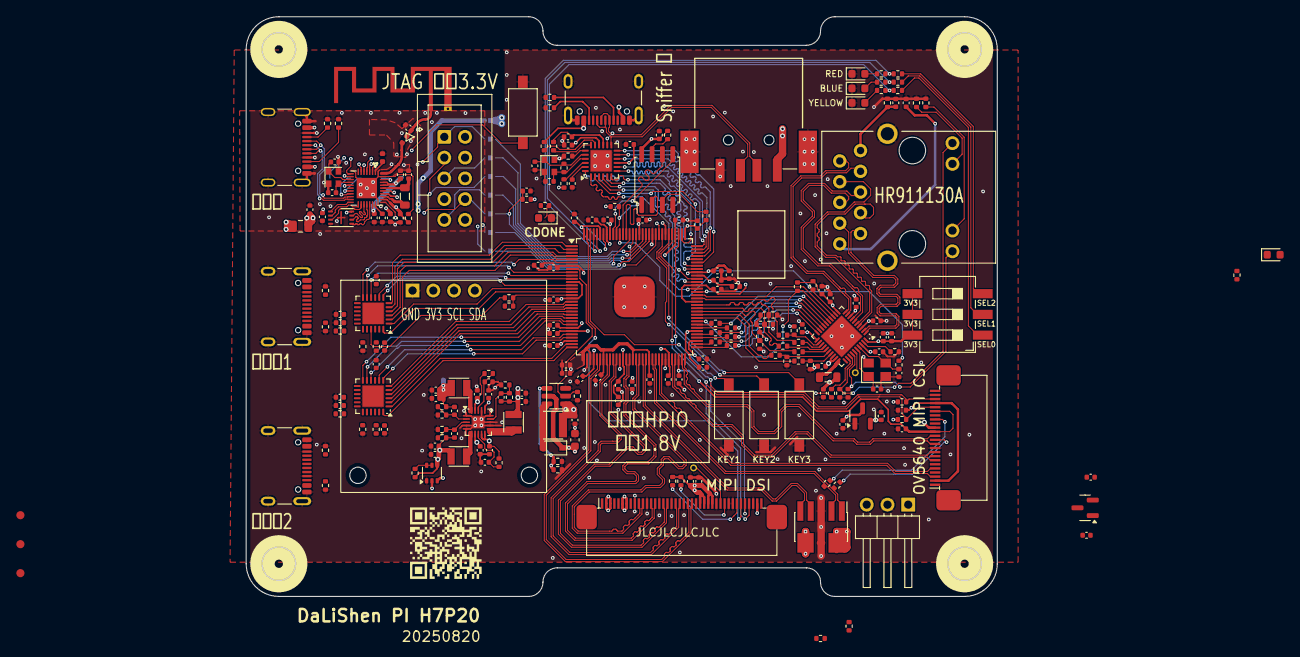
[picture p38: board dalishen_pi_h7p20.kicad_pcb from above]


Board: 4 copper layers, 92.0 x 71.0 mm, 249 parts (15 on the bottom side), 234 nets.

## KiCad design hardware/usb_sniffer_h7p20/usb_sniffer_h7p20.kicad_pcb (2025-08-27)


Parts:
C2, C11: 1uF; C_0402_1005Metric
C4, C14, C15, C16, C18, C28, C29, C33, C34, C35, C41, C42, C43, C44, C45, C46, C47, C48, C49, C50, C51, C52, C53, C55, C57, C58, C59, C60, C61: 0.1uF; C_0402_1005Metric
C12, C13, C27, C62: 10uF; C_0402_1005Metric
C19, C54, C56: NC; C_0402_1005Metric
C31, C32: 12pF; C_0402_1005Metric
D1: CESD5V0D5; D_SOD-523
D3: LED_ABGR; LED_RGB_Everlight_EASV3015RGBA0_Horizontal
F1: SMD0805B100TFT; Fuse_0805_2012Metric
J1: FPGA_JTAG; PinHeader_1x05_P2.54mm_Vertical
J4: USB_C_Receptacle_USB2.0_16P; USB_C_Receptacle_16P
J5: FFC-40P-0.5mm,NC; TE_4-1734839-0_1x40-1MP_P0.5mm_Horizontal
J6: Trigger; PinHeader_1x02_P2.54mm_Vertical
JP2: SolderJumper_2_Bridged; SolderJumper-2_P1.3mm_Bridged_RoundedPad1.0x1.5mm
JP3, JP4: SolderJumper_2_Open; SolderJumper-2_P1.3mm_Open_RoundedPad1.0x1.5mm
R2, R3, R4, R13, R18: 5.1k,1%; R_0402_1005Metric
R5, R6, R12, R19, R24: 10k,1%; R_0402_1005Metric
R7: 470; R_0402_1005Metric
R8, R9: 4.7k,1%; R_0402_1005Metric
R15, R16, R17: 4.7k; R_0402_1005Metric
TP1, TP2, TP3, TP4, TP14, TP15: TestPoint; PinHeader_1x01_P1.00mm_Vertical
TP5, TP6, TP16, TP17, TP18, TP20, TP21: TestPoint; TestPoint_Pad_D0.3mm
TP7, TP8, TP9, TP10, TP11, TP12, TP13, TP19: TestPoint; TestPoint_Pad_D0.75mm
U1: H7P20N0L128-M3H1; LQFP-128_14x14mm_P0.4mm_pad
U6: P25Q64SH-SSH-IR; SOP-8_3.9x4.9mm_P1.27mm
U7: CY7C68013A-56LTX; QFN-56-1EP_8x8mm_P0.5mm_EP4.5x5.2mm
U8: 24C32; SOP-8_3.9x4.9mm_P1.27mm
U9: CJ3439KDW; SOT-363_SC-70-6
Y2: 24M; OSC_3225

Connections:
/B9_IO2N: J5.24, U1.51 (IO2N_9)
/B9_IO2P: J5.23, U1.52 (IO2P_9)
/B9_IO4N: J5.21, U1.54 (IO4N_9)
/B9_IO4P: J5.20, U1.55 (IO4P_PCLK_9)
/B9_IO6N: J5.18, U1.56 (IO6N_9)
/B9_IO6P: J5.17, U1.57 (IO6P_9)
/B9_IO9N: J5.15, U1.60 (IO9N_9)
/B9_IO9P: J5.14, U1.61 (IO9P_PCLK_9)
/B9_IO12N: J5.12, U1.63 (IO12N_9)
/B9_IO12P: J5.11, U1.64 (IO12P_9)
/B10_IO2N: J5.39, U1.37 (IO2N_10)
/B10_IO2P: J5.38, U1.38 (IO2P_10)
/B10_IO4N: J5.36, U1.40 (IO4N_10)
/B10_IO4P: J5.35, U1.41 (IO4P_PCLK_10)
/B10_IO6N: J5.33, U1.42 (IO6N_10)
/B10_IO6P: J5.32, U1.43 (IO6P_10)
/B10_IO9N: J5.30, U1.46 (IO9N_10)
/B10_IO9P: J5.29, U1.47 (IO9P_PCLK_10)
/B10_IO12N: J5.27, U1.49 (IO12N_10)
/B10_IO12P: J5.26, U1.50 (IO12P_10)
/Boot: R15.1, TP15.1, U8.2 (A1)
/CRST_N: C2.2, R13.2, TP1.1, TP8.1, U1.114 (CRSTN)
/CY_CLKOUT: U1.6 (IO13_PCLK_8), U7.54 (CLKOUT)
/CY_FD_0: U1.13 (IO21_8), U7.18 (PB0/FD0)
/CY_FD_1: U1.14 (IO22_8), U7.19 (PB1/FD1)
/CY_FD_2: U1.15 (IO1_7), U7.20 (PB2/FD2)
/CY_FD_3: U1.16 (IO2_7), U7.21 (PB3/FD3)
/CY_FD_4: U1.18 (IO5_7), U7.22 (PB4/FD4)
/CY_FD_5: U1.19 (IO6_7), U7.23 (PB5/FD5)
/CY_FD_6: U1.20 (IO9_7), U7.24 (PB6/FD6)
/CY_FD_7: U1.21 (IO10_7), U7.25 (PB7/FD7)
/CY_FD_8: U1.74 (IO13_GCLK_4), U7.45 (PD0/FD8)
/CY_FD_9: U1.75 (IO15_4), U7.46 (PD1/FD9)
/CY_FD_10: U1.76 (IO16_4), U7.47 (PD2/FD10)
/CY_FD_11: U1.77 (IO19_4), U7.48 (PD3/FD11)
/CY_FD_12: U1.78 (IO20_4), U7.49 (PD4/FD12)
/CY_FD_13: U1.80 (IO23_4), U7.50 (PD5/FD13)
/CY_FD_14: U1.81 (IO24_4), U7.51 (PD6/FD14)
/CY_FD_15: U1.82 (IO3_3), U7.52 (PD7/FD15)
/CY_FIOADDR0: U1.10 (IO19_8), U7.37 (PA4/FIOADDR0)
/CY_FIOADDR1: U1.11 (IO20_8), U7.38 (PA5/FIOADDR1)
/CY_FLAGA: U1.22 (IO12_GCLK_7), U7.29 (CTL0/FLAGA)
/CY_FLAGB: U1.23 (IO13_PCLK_7), U7.30 (CTL1/FLAGB)
/CY_FLAGC: U1.24 (IO15_7), U7.31 (CTL2/FLAGC)
/CY_FLAGD: U1.73 (IO12_PCLK_4), U7.40 (PA7/FLAGD/~SLCS)
/CY_IFCLK: U1.5 (IO12_GCLK_8), U7.13 (IFCLK)
/CY_INT0: U1.4 (IO11_8), U7.33 (PA0/~INT0)
/CY_INT1: U1.8 (IO17_8), U7.34 (PA1/~INT1)
/CY_PKTEND: U1.72 (IO10_4), U7.39 (PA6/PKTEND)
/CY_SCL: R17.2, U7.15 (SCL), U8.6 (SCL)
/CY_SDA: R16.2, U7.16 (SDA), U8.5 (SDA)
/CY_SLOE: U1.25 (IO16_7), U7.35 (PA2/SLOE)
/CY_SLRD: U1.126 (IO3_8), U7.1 (RDY0/SLRD)
/CY_SLWR: U1.127 (IO4_8), U7.2 (RDY1/SLWR)
/CY_WU2: U1.9 (IO18_8), U7.36 (PA3/WU2)
/FPGA_CDONE: D3.1 (A), TP18.1, U1.105 (IO26_CDONE_2)
/FPGA_FLASH_CLK: U1.116 (IO18_PCCLK_1), U6.6 (CLK)
/FPGA_FLASH_CS: R5.2, U1.118 (IO12_CSN_1), U6.1 (~CS)
/FPGA_FLASH_MISO: U1.115 (IO19_MISO1_1), U6.2 (DO(IO1))
/FPGA_FLASH_MOSI: U1.119 (IO11_MOSI0_1), U6.5 (DI(IO0))
/FPGA_MSEL0: JP2.1 (A), U1.122 (IO10_MSEL0_1)
/FPGA_MSEL1: JP3.1 (A), U1.124 (IO4_MSEL1_1)
/FPGA_MSEL2: JP4.1 (A), U1.125 (IO2_MSEL2_1)
/FPGA_OUT_26M: U1.104 (IO27_GCLK_2); also elsewhere on the board
/FPGA_TCK: J1.2, TP10.1, U1.112 (IO21_TCK_1)
/FPGA_TDI: J1.3, TP9.1, U1.113 (IO20_TDI_1)
/FPGA_TDO: J1.5, TP12.1, U1.109 (IO23_TDO_1)
/FPGA_TMS: J1.4, TP11.1, U1.110 (IO22_TMS_1)
/IN: R7.1, U1.91 (IO12_PCLK_3)
/LED_BLUE: R9.2, U1.28 (IO17_7)
/LED_GREEN: R12.2, U1.29 (IO18_7)
/LED_RED: R8.2, U1.31 (IO21_7)
/USB20_DM_CMP1: U1.68 (IO7_4); also elsewhere on the board
/USB20_DM_CMP2: U1.69 (IO8_4); also elsewhere on the board
/USB20_DM_CMP3: U1.108 (IO24_GCLK_1); also elsewhere on the board
/USB20_DP_CMP1: U1.71 (IO9_4); also elsewhere on the board
/USB20_DP_CMP2: U1.102 (IO33_MISO3_2); also elsewhere on the board
/USB20_DP_CMP3: U1.106 (IO25_GCLK_2); also elsewhere on the board
/USB334x_CLK: U1.92 (IO13_GCLK_3); also elsewhere on the board
/USB334x_D0: U1.94 (IO18_3); also elsewhere on the board
/USB334x_D1: U1.96 (IO20_3); also elsewhere on the board
/USB334x_D2: U1.95 (IO19_3); also elsewhere on the board
/USB334x_D3: U1.90 (IO10_3); also elsewhere on the board
/USB334x_D4: U1.89 (IO9_3); also elsewhere on the board
/USB334x_D5: U1.86 (IO7_3); also elsewhere on the board
/USB334x_D6: U1.85 (IO6_3); also elsewhere on the board
/USB334x_D7: U1.83 (IO4_3); also elsewhere on the board
/USB334x_DIR: U1.98 (IO23_3); also elsewhere on the board
/USB334x_NXT: U1.93 (IO17_3); also elsewhere on the board
/USB334x_STP: U1.99 (IO24_3); also elsewhere on the board
/USB_D_N: J4.A7 (D-), J4.B7 (D-), U7.9 (D-)
/USB_D_P: J4.A6 (D+), J4.B6 (D+), U7.8 (D+)
/VCCAUX: C13.2, C16.2, C41.2, C44.2, C50.2, C60.2, J5.7, J5.8, R24.2, U1.27 (VDDAUX), U1.44 (VDDAUX), U1.58 (VDDAUX), U1.87 (VDDAUX), U1.120 (VDDAUX), U9.4 (S2); also elsewhere on the board
/VCC_3V3: C4.2, C11.2, C14.2, C18.2, C27.2, C28.2, C29.2, C33.2, C34.2, C42.2, C45.2, C48.2, C51.2, J5.4, J5.5, JP2.2 (B), JP3.2 (B), JP4.2 (B), R4.1, R5.1, R6.1, R13.1, R16.1, R17.1, R18.1, R19.1, TP14.1, TP19.1, U1.12 (VDDIO_8), U1.17 (VDDIO_7), U1.30 (VDDIO_7), U1.67 (VDDIO_4), U1.79 (VDDIO_4), U1.84 (VDDIO_3), U1.97 (VDDIO_3), U1.103 (VDDIO_2), U1.111 (VDDIO_1), U1.123 (VDDIO_1), U1.128 (VDDIO_8), U6.8 (VCC), U7.3 (AVCC), U7.7 (AVCC), U7.11 (VCC), U7.17 (VCC), U7.27 (VCC), U7.32 (VCC), U7.43 (VCC), U7.55 (VCC), U8.1 (A0), U8.8 (VCC), U9.2 (G1); also elsewhere on the board
/VCC_5V: D1.1 (K), F1.1, J5.1, J5.2, TP13.1; also elsewhere on the board
/VDDIO_1V8: C47.2, C53.2, C58.2, C62.2, U1.33 (VDDIO_18), U1.35 (VDDIO_18), U1.39 (VDDIO_10), U1.48 (VDDIO_10), U1.53 (VDDIO_9), U1.62 (VDDIO_9), U9.3 (D2)
/VDD_CORE: C12.2, C15.2, C19.2, C43.2, C46.2, C49.2, C52.2, C54.2, C55.2, C56.2, C57.2, C59.2, C61.2, U1.7 (VDD_CORE), U1.26 (VDD_CORE), U1.36 (VDD_CORE), U1.45 (VDD_CORE), U1.59 (VDD_CORE), U1.70 (VDD_CORE), U1.88 (VDD_CORE), U1.100 (VDD_CORE), U1.121 (VDD_CORE); also elsewhere on the board
GND: C2.1, C4.1, C11.1, C12.1, C13.1, C14.1, C15.1, C16.1, C18.1, C19.1, C27.1, C28.1, C29.1, C31.1, C32.1, C33.1, C34.1, C35.1, C41.1, C42.1, C43.1, C44.1, C45.1, C46.1, C47.1, C48.1, C49.1, C50.1, C51.1, C52.1, C53.1, C54.1, C55.1, C56.1, C57.1, C58.1, C59.1, C60.1, C61.1, C62.1, D1.2 (A), J1.1, J4.A1 (GND), J4.A8 (SBU1), J4.A12 (GND), J4.B1 (GND), J4.B8 (SBU2), J4.B12 (GND), J4.S1 (SHIELD), J5.10, J5.13, J5.16, J5.19, J5.22, J5.25, J5.28, J5.31, J5.34, J5.37, J5.40, J6.2, R2.1, R3.1, R15.2, TP2.1, TP3.1, TP7.1, U1.34 (GND), U1.107 (MSC), U1.129 (GND), U6.4 (GND), U6.9 (EP), U7.6 (AGND), U7.10 (AGND), U7.12 (GND), U7.14 (RESERVED), U7.26 (GND), U7.28 (GND), U7.41 (GND), U7.53 (GND), U7.56 (GND), U7.57 (EP), U8.3 (A2), U8.4 (GND), U8.7 (WP), U9.1 (S1), Y2.2, Y2.4; also elsewhere on the board
unnamed: D3.2 (BK), R9.1
unnamed: D3.3 (GK), R12.1
unnamed: D3.4 (RK), R8.1
unnamed: F1.2, J4.A4 (VBUS), J4.A9 (VBUS), J4.B4 (VBUS), J4.B9 (VBUS)
unnamed: J4.A5 (CC1), R2.2
unnamed: J4.B5 (CC2), R3.2
unnamed: J6.1, R7.2
unnamed: TP21.1, U1.65 (IO1_4)
unnamed: TP20.1, U1.66 (IO2_4)
unnamed: TP16.1, U1.1 (IO6_8)
unnamed: TP17.1, U1.117 (IO16_GCLK_1)
unnamed: TP5.1, U1.32 (IO22_7)
unnamed: TP6.1, U1.101 (IO34_MISO2_2)
unnamed: R6.2, U6.3 (IO2)
unnamed: R19.2, U6.7 (IO3)
unnamed: R18.2, U7.44 (WAKEUP)
unnamed: C31.2, U7.5 (XTALIN), Y2.1
unnamed: C32.2, U7.4 (XTALOUT), Y2.3
unnamed: C35.2, R4.2, TP4.1, U7.42 (~RESET)
unnamed: R24.1, U9.5 (G2), U9.6 (D1)

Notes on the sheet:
CJ3439KDW原理示意图
GND TCK TDI TMS TDO
上电顺序：VCC_5V --- 0R >>> OUT1(0.95V) --- 10k 1uF RC >>> OUT2(VCCAUX) --- 20k 1uF RC >>> OUT3(3.3V) CJ3439KDW在3.3V上电后，导通VCCAUX到VDDIO_1V8


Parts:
C17, C20, C22, C24, C25, C37, C39: 10uF; C_0402_1005Metric
C21, C23, C30: 220pF; C_0402_1005Metric
C26, C36, C38: 1uF; C_0402_1005Metric
L2, L3: 4.7uH,MPL2012S4R7MHT; L_0805_2012Metric
L5: 1.5uH; L_NR2520xx
R32: 150k,1%; R_0402_1005Metric
R33, R38, R39: 33k,1%; R_0402_1005Metric
R34: 10k,1%; R_0402_1005Metric
R35, R37, R40: 20k,1%; R_0402_1005Metric
U11: EA3036C; QFN-20-1EP_3x3mm_P0.4mm_EP1.65x1.65mm

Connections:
/ET3036C/EA3036_EN2: C38.2, R37.1, U11.8 (EN2)
/ET3036C/EA3036_EN3: C36.2, R38.1, U11.18 (EN3)
/VCCAUX: C17.2, C23.1, L3.1, R35.2; also elsewhere on the board
/VCC_3V3: C20.2, C21.2, L2.1, R32.1; also elsewhere on the board
/VCC_5V: C22.2, C24.2, C25.2, C26.2, R37.2, R38.2, U11.7 (VIN2), U11.9 (EN1), U11.10 (VIN1), U11.16 (VCC), U11.19 (VIN3); also elsewhere on the board
/VDD_CORE: C30.1, C37.2, C39.2, L5.2, R40.2; also elsewhere on the board
GND: C17.1, C20.1, C22.1, C24.1, C25.1, C26.1, C36.1, C37.1, C38.1, C39.1, R33.2, R34.1, R39.1, U11.1 (GND3), U11.4 (GND2), U11.5 (GND2), U11.12 (GND1), U11.13 (GND1), U11.15 (AGND), U11.17 (AGND), U11.21 (EPAD); also elsewhere on the board
unnamed: C30.2, R39.2, R40.1, U11.14 (FB1)
unnamed: C23.2, R34.2, R35.1, U11.3 (FB2)
unnamed: C21.1, R32.2, R33.1, U11.2 (FB3)
unnamed: L5.1, U11.11 (LX1)
unnamed: L3.2, U11.6 (LX2)
unnamed: L2.2, U11.20 (LX3)


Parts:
C1, C3, C8: 0.1uF; C_0402_1005Metric
C6, C9, C10: 1uF; C_0402_1005Metric
J2: USB_C_Receptacle_USB2.0_16P; USB_C_Receptacle_16P
J3: USB_A; USB-AF_YIJIAN
R20, R28, R31: 10k,1%; R_0402_1005Metric
R21: 33k,1%; R_0402_1005Metric
R22, R23: 4.7k; R_0402_1005Metric
R25, R26: 5.1k,1%; R_0402_1005Metric
R30: 8.06k,1%; R_0402_1005Metric
U2, U3, U4: GSV332-MR; MSOP-8_3x3mm_P0.65mm
U5: USB3343; QFN-24-1EP_4x4mm_P0.5mm_EP2.6x2.6mm

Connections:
/FPGA_OUT_26M: U5.21 (REFCLK/XI); also elsewhere on the board
/USB20_DM_CMP1: U2.7; also elsewhere on the board
/USB20_DM_CMP2: U3.7; also elsewhere on the board
/USB20_DM_CMP3: U4.7; also elsewhere on the board
/USB20_DP_CMP1: U2.1; also elsewhere on the board
/USB20_DP_CMP2: U3.1; also elsewhere on the board
/USB20_DP_CMP3: U4.1; also elsewhere on the board
/USB334x/CMP_REF_1: R22.2, R23.1, U2.2 (-), U2.6 (-)
/USB334x/CMP_REF_2: R21.2, R22.1, U3.2 (-), U3.6 (-)
/USB334x/CMP_REF_3: R20.2, R21.1, U4.2 (-), U4.6 (-)
/USB334x/T_VBUS: J2.A4 (VBUS), J2.A9 (VBUS), J2.B4 (VBUS), J2.B9 (VBUS), J3.1 (VBUS), R28.1
/USB334x/USB20_D_N: J2.A7 (D-), J2.B7 (D-), J3.2 (D-), U2.5 (+), U3.5 (+), U4.5 (+), U5.14 (DM)
/USB334x/USB20_D_P: J2.A6 (D+), J2.B6 (D+), J3.3 (D+), U2.3 (+), U3.3 (+), U4.3 (+), U5.13 (DP)
/USB334x_CLK: U5.2 (CLKOUT); also elsewhere on the board
/USB334x_D0: U5.4 (DATA0); also elsewhere on the board
/USB334x_D1: U5.5 (DATA1); also elsewhere on the board
/USB334x_D2: U5.6 (DATA2); also elsewhere on the board
/USB334x_D3: U5.7 (DATA3); also elsewhere on the board
/USB334x_D4: U5.8 (DATA4); also elsewhere on the board
/USB334x_D5: U5.10 (DATA5); also elsewhere on the board
/USB334x_D6: U5.11 (DATA6); also elsewhere on the board
/USB334x_D7: U5.12 (DATA7); also elsewhere on the board
/USB334x_DIR: U5.1 (DIR); also elsewhere on the board
/USB334x_NXT: U5.3 (NXT); also elsewhere on the board
/USB334x_STP: U5.24 (STP); also elsewhere on the board
/VCC_3V3: C1.2, C3.2, C6.2, C8.2, R20.1, R31.1, U2.8 (V+), U3.8 (V+), U4.8 (V+), U5.9 (VDDIO), U5.16 (VBAT); also elsewhere on the board
GND: C1.1, C3.1, C6.1, C8.1, C9.1, C10.1, J2.A1 (GND), J2.A8 (SBU1), J2.A12 (GND), J2.B1 (GND), J2.B8 (SBU2), J2.B12 (GND), J2.S1 (SHIELD), J3.4 (GND), J3.5 (Shield), R23.2, R25.2, R26.2, R30.2, U2.4 (V-), U3.4 (V-), U4.4 (V-), U5.25 (GND); also elsewhere on the board
unnamed: J2.A5 (CC1), R26.1
unnamed: J2.B5 (CC2), R25.1
unnamed: C10.2, U5.15 (VDD33), U5.18 (ID)
unnamed: R30.1, U5.19 (RBIAS)
unnamed: R28.2, U5.17 (VBUS)
unnamed: C9.2, U5.23 (VDD18)
unnamed: R31.2, U5.22 (~RESETB)

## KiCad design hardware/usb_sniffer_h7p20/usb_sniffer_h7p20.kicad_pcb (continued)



Board: 4 copper layers, 47.5 x 47.5 mm, 139 parts (12 on the bottom side), 139 nets.

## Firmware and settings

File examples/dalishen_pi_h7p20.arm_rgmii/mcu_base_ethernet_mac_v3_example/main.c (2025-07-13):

#include <stdio.h>
#include <string.h>
#include "hme_includes.h"
#include "hme_uart.h"
#include "hme_retarget.h"

#define RAM_REG_WORD_WRITE(base, offset, data) *(volatile uint32_t *)((base) + (offset)) = (data)
#define RAM_REG_WORD_READ(base, offset) (*(volatile uint32_t *)((base) + (offset)))
	
#define RAM_BASE	((uint32_t)0xa0000000)
#define RAM			  ((RAM_TYPE *)RAM_BASE)
#define RAM_TEST_SIZE    256
#define SRC_MAC_ADDR_BD  0xDA0102030405    //default src mac addr 0xDA0102030405
#define DEST_MAC_ADDR_BD 0x00E04CA80352    //default dest mac addr, !!! Yor PC MAC
#define SRC_IP_ADDR_BD   0xC0A8010B        //default src ip addr 0xC0A8010B
#define DEST_IP_ADDR_BD  0xC0A8010A        //default dest ip addr 0xC0A8010A

#define SRC_MAC_ADDR_LD  0x0504030201DA
#define DEST_MAC_ADDR_LD 0x5203A84CE000		// base DEST_MAC_ADDR_BD
#define SRC_IP_ADDR_LD   0x0B01A8C0
#define DEST_IP_ADDR_LD  0x0A01A8C0 

void Delay(int n) 
{
	int i,j;
	for (i=0; i<=n; i++)
		for (j=0; j<=100; j++);
}

uint32_t Splice(uint16_t a, uint16_t b)
{
	
    uint32_t result = (a << 16) | b; 
    return result;
}	

uint16_t SwapEndian16(uint16_t value) {
    return (value >> 8) | (value << 8);
}
uint32_t SwapEndian32(uint32_t value) {
    return ((value >> 24) & 0x000000FF) |
           ((value >> 8)  & 0x0000FF00) |
           ((value << 8)  & 0x00FF0000) |
           (value << 24);
}

void Split32BitToTwo16Bits(uint32_t input32, uint16_t *output16_1, uint16_t *output16_2) {
    *output16_1 = (input32 >> 16) & 0x0000FFFF; 
    *output16_2 = input32 & 0x0000FFFF;         
}

uint16_t CalculateIpCheckSum(const uint16_t *buffer, size_t length) {
    uint32_t sum = 0;
    size_t i;

    for (i = 0; i < length; i++) {
        sum += buffer[i]; 
    }

    while (sum >> 16) {
        sum = (sum & 0xFFFF) + (sum >> 16);
    }

    return ~(uint16_t)sum;
}
void RxFifoStatus(void)
{
	uint32_t cnt;
	uint32_t mem_ctrl_stat;
	uint32_t mem_ctrl_stat_mask;
	uint32_t rx_fifo_enable;
	
	
	    cnt = 0x00000000;
	    rx_fifo_enable = 0x00000000;
			mem_ctrl_stat_mask = 0x00000020;
	    
			while(rx_fifo_enable != 0x00000020){
				cnt = cnt + 1;
			  mem_ctrl_stat = RAM_REG_WORD_READ(RAM_BASE,0x00001044);	
				rx_fifo_enable = mem_ctrl_stat & mem_ctrl_stat_mask;
			};
			printf("Time is : %x    ",cnt);

}

void SelectRamArea(uint32_t *select_ram,uint32_t *transmitte)

{
	if (*select_ram == 0x00000000){
		*select_ram = 0x00000010;
		*transmitte = 0x00000041;
	}
	else{
		*select_ram = 0x00000000;
		*transmitte = 0x00000031;
	}
}

void ReadData(uint32_t mem_rx_data[],uint32_t *mem_ctrl_rx_len,uint32_t *mem_ctrl_rx_len_div4)
{
	int i;

		*mem_ctrl_rx_len = RAM_REG_WORD_READ(RAM_BASE,0x0000104C); 
	
		if (*mem_ctrl_rx_len%4 == 0)
			*mem_ctrl_rx_len_div4 = *mem_ctrl_rx_len/4;
		else 
			*mem_ctrl_rx_len_div4 = *mem_ctrl_rx_len/4 + 1;
		
		for(i=0;i<*mem_ctrl_rx_len_div4;i++){
			mem_rx_data[i] = RAM_REG_WORD_READ(RAM_BASE, 0x00000800);
		};
		
		RAM_REG_WORD_WRITE(RAM_BASE, 0x00001040, 0x00000051); 
}

uint32_t FrameType(uint32_t mem_rx_data[])
{
	uint32_t result;
	uint32_t addr0 = (uint32_t)(SRC_MAC_ADDR_LD & 0xFFFFFFFF);
  uint32_t broad_addr1 = (uint32_t)((DEST_MAC_ADDR_LD << 16) | 0xFFFF);
	uint32_t icmp_addr1 = ((uint16_t)((SRC_MAC_ADDR_LD >> 32)) & 0xFFFF)|((uint32_t)((DEST_MAC_ADDR_LD & 0xFFFF) << 16));
	uint32_t addr2 = (uint32_t)(DEST_MAC_ADDR_LD >> 16);

	
  if (mem_rx_data[0] == 0xFFFFFFFF && mem_rx_data[1] == broad_addr1 && mem_rx_data[2] == addr2)
  //if (mem_rx_data[0] == 0xFFFFFFFF && mem_rx_data[1] == 0x3C6CFFFF && mem_rx_data[2] == 0x59532A8C)
		result = 0x00000001;
	else if (mem_rx_data[0] == addr0 && mem_rx_data[1] == icmp_addr1 && mem_rx_data[2] == addr2 && mem_rx_data[5] != 0x01800000)
	//else if (mem_rx_data[0] == 0x030201DA && mem_rx_data[1] == 0x3C6C0504 && mem_rx_data[2] == 0x59532A8C && mem_rx_data[5] != 0x01800000)
		result = 0x00000001;
	else if (mem_rx_data[0] == addr0 && mem_rx_data[1] == icmp_addr1 && mem_rx_data[2] == addr2 && mem_rx_data[5] == 0x01800000)
		result = 0x00000002;
  else 
		result = 0x00000000;
		
	return result; 	
}

void BroadcastReplay(uint32_t mem_tx_data[],uint32_t *mem_ctrl_tx_len_div4,uint32_t *mem_ctrl_tx_len,uint32_t *select_ram,uint32_t *transmitte)
{ 
	
	int i;

	uint16_t high_addr0;
	uint16_t low_addr0;
  uint16_t high_addr1;
	uint16_t low_addr1;
	uint32_t high_addr2;
	uint32_t low_addr2;
	uint16_t high_addr3;
	uint16_t low_addr3;
	
	uint32_t addr0;
	uint32_t addr1;
	uint32_t addr2;
	
		low_addr0  = mem_tx_data[1] >> 16;
		high_addr0 = mem_tx_data[2]; 
		
		low_addr1  = mem_tx_data[2] >> 16;
		high_addr1 = 0x01DA; 		
		addr0 = Splice(high_addr0,low_addr0);
		addr1 = Splice(high_addr1,low_addr1);
		addr2 = SRC_MAC_ADDR_LD >> 16;
		//addr2 = 0x05040302;
			
		//high_addr3 = 0x01DA;
		high_addr3 = SRC_MAC_ADDR_LD & 0xFFFF;
	  low_addr3  = 0x0200;
			
		mem_tx_data[0] = addr0;
		mem_tx_data[1] = addr1;
		mem_tx_data[2] = addr2;
		mem_tx_data[5] = Splice(high_addr3,low_addr3);
		//mem_tx_data[6] = 0x05040302;
		mem_tx_data[6] = addr2;
		mem_tx_data[7] = SRC_IP_ADDR_LD;
		//mem_tx_data[7] = 0x0B01A8C0;

		RAM_REG_WORD_WRITE(RAM_BASE, 0x00001044, *select_ram);          //Select RAM0 to Store Data
		//RAM_REG_WORD_WRITE(RAM_BASE, 0x00001040, *transmitte);          //indicating TX memory 0 contains a frame to be transmitte
		RAM_REG_WORD_WRITE(RAM_BASE, 0x00000000, *mem_ctrl_tx_len);   	//Write Frame LEN to RAM0			
		
		for (i=0;i<*mem_ctrl_tx_len_div4;i++){
			RAM_REG_WORD_WRITE(RAM_BASE, 4*(i+1), mem_tx_data[i]);        //Write Frame Data to RAM0  mac frame head 0x2A8C3C6C 0x01DA5953
		};
		//RAM_REG_WORD_WRITE(RAM_BASE, 0x00001044, *select_ram);          //Select RAM0 to Store Data	
		RAM_REG_WORD_WRITE(RAM_BASE, 0x00001040, *transmitte);          //indicating TX memory 0 contains a frame to be transmitte
    
}

void IcmpEchoReplay(uint32_t mem_rx_data[],uint32_t *mem_ctrl_rx_len_div4,uint32_t *mem_ctrl_rx_len,uint32_t *select_ram,uint32_t *transmitte)
{
	int i;
	uint32_t mem_ctrl_stat;
	uint32_t mem_ctrl_rx_status;
	
	uint16_t high_addr0;
	uint16_t low_addr0;
  uint16_t high_addr1;
	uint16_t low_addr1;
	uint32_t high_addr2;
	uint32_t low_addr2;
	uint16_t high_addr3;
	uint16_t low_addr3;
	

	uint16_t sum;
	uint16_t sum_t;
	uint32_t mem[11];
	uint16_t mem16[20];
	uint32_t src_ip_addr;
	uint32_t dest_ip_addr;
	uint16_t mem_rx_data6;
	
	uint32_t addr0;
	uint32_t addr1;
	uint32_t addr2;
		
			low_addr0  = mem_rx_data[1] >> 16;
			high_addr0 = mem_rx_data[2]; 
				
		  low_addr1  = mem_rx_data[2] >> 16;
			high_addr1 = mem_rx_data[0]; 
				
			low_addr2  = mem_rx_data[0] >> 16;
			high_addr2 = mem_rx_data[1]; 
				
			addr0 = Splice(high_addr0,low_addr0);
			addr1 = Splice(high_addr1,low_addr1);
			addr2 = Splice(high_addr2,low_addr2);
			
		  mem_rx_data6 = mem_rx_data[6];
			
			dest_ip_addr = (mem_rx_data[7]<<16)|(mem_rx_data[6]>>16);  //0a01a8c0
			src_ip_addr = (mem_rx_data[8]<<16)|(mem_rx_data[7]>>16);   //0b01a8c0
			
			mem_rx_data[0] = addr0;
			mem_rx_data[1] = addr1;
			mem_rx_data[2] = addr2;

			for (i=9;i<21;i++){
				mem[i-9] = SwapEndian32(mem_rx_data[i]);
			}
			
			
			for(i=0;i<20;i=i+2){
				Split32BitToTwo16Bits(mem[i/2], &mem16[i], &mem16[i+1]);
			}
			
			mem16[0] = 0x0000;
			mem16[19] = 0x0000;
			for (i=0;i<20;i++){
				sum = CalculateIpCheckSum(mem16, 20);
			}

			sum = SwapEndian16(sum); 

			mem_rx_data[6] = Splice(src_ip_addr, mem_rx_data6);   
			mem_rx_data[7] = Splice(src_ip_addr,src_ip_addr>>16); 
			mem_rx_data[8] = Splice(0x0000,dest_ip_addr>>16);
			mem_rx_data[9] = Splice(mem_rx_data[9]>>16,sum);	

		  RAM_REG_WORD_WRITE(RAM_BASE, 0x00001044, *select_ram);  //Select RAM0 to Store Data
			//RAM_REG_WORD_WRITE(RAM_BASE, 0x00001040, *transmitte);  //indicating TX memory 0 contains a frame to be transmitte
			//RAM_REG_WORD_WRITE(RAM_BASE, 0x00000000, 0x0000004A);   //Write Frame LEN to RAM0	
			RAM_REG_WORD_WRITE(RAM_BASE, 0x00000000, *mem_ctrl_rx_len);   //Write Frame LEN to RAM0		
			//for (i=0;i<20;i++){
			for (i=0;i<*mem_ctrl_rx_len_div4;i++){
				RAM_REG_WORD_WRITE(RAM_BASE, 4*(i+1), mem_rx_data[i]);   //Write Frame Data to RAM0  mac frame head 0x2A8C3C6C 0x01DA5953
				//printf("squence num : %d data : %8x\n",mem16[2],mem_rx_data[i]);
			}
			//RAM_REG_WORD_WRITE(RAM_BASE, 0x00001044, *select_ram);   //Select RAM0 to Store Data	
			RAM_REG_WORD_WRITE(RAM_BASE, 0x00001040, *transmitte);   //indicating TX memory 0 contains a frame to be transmitte
			
			

}

void PhyConfig(uint32_t BASE_ADDR)
{ 
	
	  RAM_REG_WORD_WRITE(BASE_ADDR, 0x0000100C, 0x0000A001);   //PHY0 Config data  //1.8V
		RAM_REG_WORD_WRITE(BASE_ADDR, 0x00001008, 0x00001E87);   //PHY0 Config addr  phy0_addr 0x01  phy1_addr 0x03
	  RAM_REG_WORD_WRITE(BASE_ADDR, 0x0000100C, 0x00000100);   //PHY0 Config data  
		RAM_REG_WORD_WRITE(BASE_ADDR, 0x00001008, 0x00001F87);   //PHY0 Config addr      
	
	  RAM_REG_WORD_WRITE(BASE_ADDR, 0x0000100C, 0x0000A003);   //PHY0 Config data  
		RAM_REG_WORD_WRITE(BASE_ADDR, 0x00001008, 0x00001E87);   //PHY0 Config addr 
	  RAM_REG_WORD_WRITE(BASE_ADDR, 0x0000100C, 0x000000f1);   //PHY0 Config data  
		RAM_REG_WORD_WRITE(BASE_ADDR, 0x00001008, 0x00001F87);   //PHY0 Config addr    
	
		RAM_REG_WORD_WRITE(BASE_ADDR, 0x0000100C, 0x00000054);   //PHY0 Config data  
		RAM_REG_WORD_WRITE(BASE_ADDR, 0x00001008, 0x00001E87);   //PHY0 Config addr  
	  RAM_REG_WORD_WRITE(BASE_ADDR, 0x0000100C, 0x0000c000);   //PHY0 Config data  
		RAM_REG_WORD_WRITE(BASE_ADDR, 0x00001008, 0x00001F87);   //PHY0 Config addr    
	
		RAM_REG_WORD_WRITE(BASE_ADDR, 0x0000100C, 0x0000a012);   //PHY0 Config data  
		RAM_REG_WORD_WRITE(BASE_ADDR, 0x00001008, 0x00001E87);   //PHY0 Config addr  
	  RAM_REG_WORD_WRITE(BASE_ADDR, 0x0000100C, 0x000000c8);   //PHY0 Config data  
		RAM_REG_WORD_WRITE(BASE_ADDR, 0x00001008, 0x00001F87);   //PHY0 Config addr   	
	
		RAM_REG_WORD_WRITE(BASE_ADDR, 0x0000100C, 0x00000027);   //PHY0 Config data  
		RAM_REG_WORD_WRITE(BASE_ADDR, 0x00001008, 0x00001E87);   //PHY0 Config addr  
	  RAM_REG_WORD_WRITE(BASE_ADDR, 0x0000100C, 0x00006812);   //PHY0 Config data  
		RAM_REG_WORD_WRITE(BASE_ADDR, 0x00001008, 0x00001F87);   //PHY0 Config addr 	
	
		RAM_REG_WORD_WRITE(BASE_ADDR, 0x0000100C, 0x0000A006);   //PHY0 Config data  
		RAM_REG_WORD_WRITE(BASE_ADDR, 0x00001008, 0x00001E87);   //PHY0 Config addr  
	  RAM_REG_WORD_WRITE(BASE_ADDR, 0x0000100C, 0x0000008D);   //PHY0 Config data  
		RAM_REG_WORD_WRITE(BASE_ADDR, 0x00001008, 0x00001F87);   //PHY0 Config addr 
		
		RAM_REG_WORD_WRITE(BASE_ADDR, 0x0000100C, 0x00000052);   //PHY0 Config data  
		RAM_REG_WORD_WRITE(BASE_ADDR, 0x00001008, 0x00001E87);   //PHY0 Config addr  
	  RAM_REG_WORD_WRITE(BASE_ADDR, 0x0000100C, 0x0000A37D);   //PHY0 Config data  
		RAM_REG_WORD_WRITE(BASE_ADDR, 0x00001008, 0x00001F87);   //PHY0 Config addr 	
		
		RAM_REG_WORD_WRITE(BASE_ADDR, 0x0000100C, 0x000000DD);   //PHY0 Config data  
		RAM_REG_WORD_WRITE(BASE_ADDR, 0x00001008, 0x00001E87);   //PHY0 Config addr  
	  RAM_REG_WORD_WRITE(BASE_ADDR, 0x0000100C, 0x0000856e);   //PHY0 Config data  
		RAM_REG_WORD_WRITE(BASE_ADDR, 0x00001008, 0x00001F87);   //PHY0 Config addr 
		
		RAM_REG_WORD_WRITE(BASE_ADDR, 0x0000100C, 0x00000051);   //PHY0 Config data  
		RAM_REG_WORD_WRITE(BASE_ADDR, 0x00001008, 0x00001E87);   //PHY0 Config addr  
	  RAM_REG_WORD_WRITE(BASE_ADDR, 0x0000100C, 0x000014f6);   //PHY0 Config data  
		RAM_REG_WORD_WRITE(BASE_ADDR, 0x00001008, 0x00001F87);   //PHY0 Config addr 	

	  RAM_REG_WORD_WRITE(BASE_ADDR, 0x0000100C, 0x00000029);   //PHY0 Config data  
		RAM_REG_WORD_WRITE(BASE_ADDR, 0x00001008, 0x00001E87);   //PHY0 Config addr  
	  RAM_REG_WORD_WRITE(BASE_ADDR, 0x0000100C, 0x0000000d);   //PHY0 Config data  
		RAM_REG_WORD_WRITE(BASE_ADDR, 0x00001008, 0x00001F87);   //PHY0 Config addr 	
		
	  RAM_REG_WORD_WRITE(BASE_ADDR, 0x0000100C, 0x000000A0);   //PHY0 Config data  
		RAM_REG_WORD_WRITE(BASE_ADDR, 0x00001008, 0x00001E87);   //PHY0 Config addr  
	  RAM_REG_WORD_WRITE(BASE_ADDR, 0x0000100C, 0x0000A8D0);   //PHY0 Config data  
		RAM_REG_WORD_WRITE(BASE_ADDR, 0x00001008, 0x00001F87);   //PHY0 Config addr 
		
		RAM_REG_WORD_WRITE(BASE_ADDR, 0x0000100C, 0x0000080c);   //PHY0 Config data  
		RAM_REG_WORD_WRITE(BASE_ADDR, 0x00001008, 0x00001487);   //PHY0 Config addr  	
		
		RAM_REG_WORD_WRITE(BASE_ADDR, 0x0000100C, 0x00001C01);   //PHY0 Config data  
		RAM_REG_WORD_WRITE(BASE_ADDR, 0x00001008, 0x00000487);   //PHY0 Config addr  		
		
		RAM_REG_WORD_WRITE(BASE_ADDR, 0x0000100C, 0x00004140);   //PHY0 Config data  
		RAM_REG_WORD_WRITE(BASE_ADDR, 0x00001008, 0x00000087);   //PHY0 Config addr   
		
		
    RAM_REG_WORD_WRITE(BASE_ADDR, 0x0000100C, 0x0000A001);   //PHY0 Config data  //1.8V
		RAM_REG_WORD_WRITE(BASE_ADDR, 0x00001008, 0x00000E87);   //PHY0 Config addr  phy0_addr 0x01  phy1_addr 0x03
	  RAM_REG_WORD_WRITE(BASE_ADDR, 0x0000100C, 0x00000100);   //PHY0 Config data  
		RAM_REG_WORD_WRITE(BASE_ADDR, 0x00001008, 0x00000F87);   //PHY0 Config addr      
	
	  RAM_REG_WORD_WRITE(BASE_ADDR, 0x0000100C, 0x0000A003);   //PHY0 Config data  
		RAM_REG_WORD_WRITE(BASE_ADDR, 0x00001008, 0x00000E87);   //PHY0 Config addr 
	  RAM_REG_WORD_WRITE(BASE_ADDR, 0x0000100C, 0x000000f1);   //PHY0 Config data  
		RAM_REG_WORD_WRITE(BASE_ADDR, 0x00001008, 0x00000F87);   //PHY0 Config addr    
	
		RAM_REG_WORD_WRITE(BASE_ADDR, 0x0000100C, 0x00000054);   //PHY0 Config data  
		RAM_REG_WORD_WRITE(BASE_ADDR, 0x00001008, 0x00000E87);   //PHY0 Config addr  
	  RAM_REG_WORD_WRITE(BASE_ADDR, 0x0000100C, 0x0000c000);   //PHY0 Config data  
		RAM_REG_WORD_WRITE(BASE_ADDR, 0x00001008, 0x00000F87);   //PHY0 Config addr    
	
		RAM_REG_WORD_WRITE(BASE_ADDR, 0x0000100C, 0x0000a012);   //PHY0 Config data  
		RAM_REG_WORD_WRITE(BASE_ADDR, 0x00001008, 0x00000E87);   //PHY0 Config addr  
	  RAM_REG_WORD_WRITE(BASE_ADDR, 0x0000100C, 0x000000c8);   //PHY0 Config data  
		RAM_REG_WORD_WRITE(BASE_ADDR, 0x00001008, 0x00000F87);   //PHY0 Config addr   	
	
		RAM_REG_WORD_WRITE(BASE_ADDR, 0x0000100C, 0x00000027);   //PHY0 Config data  
		RAM_REG_WORD_WRITE(BASE_ADDR, 0x00001008, 0x00000E87);   //PHY0 Config addr  
	  RAM_REG_WORD_WRITE(BASE_ADDR, 0x0000100C, 0x00006812);   //PHY0 Config data  
		RAM_REG_WORD_WRITE(BASE_ADDR, 0x00001008, 0x00000F87);   //PHY0 Config addr 	
	
		RAM_REG_WORD_WRITE(BASE_ADDR, 0x0000100C, 0x0000A006);   //PHY0 Config data  
		RAM_REG_WORD_WRITE(BASE_ADDR, 0x00001008, 0x00000E87);   //PHY0 Config addr  
	  RAM_REG_WORD_WRITE(BASE_ADDR, 0x0000100C, 0x0000008D);   //PHY0 Config data  
		RAM_REG_WORD_WRITE(BASE_ADDR, 0x00001008, 0x00000F87);   //PHY0 Config addr 
		
		RAM_REG_WORD_WRITE(BASE_ADDR, 0x0000100C, 0x00000052);   //PHY0 Config data  
		RAM_REG_WORD_WRITE(BASE_ADDR, 0x00001008, 0x00000E87);   //PHY0 Config addr  
	  RAM_REG_WORD_WRITE(BASE_ADDR, 0x0000100C, 0x0000A37D);   //PHY0 Config data  
		RAM_REG_WORD_WRITE(BASE_ADDR, 0x00001008, 0x00000F87);   //PHY0 Config addr 	
		
		RAM_REG_WORD_WRITE(BASE_ADDR, 0x0000100C, 0x000000DD);   //PHY0 Config data  
		RAM_REG_WORD_WRITE(BASE_ADDR, 0x00001008, 0x00000E87);   //PHY0 Config addr  
	  RAM_REG_WORD_WRITE(BASE_ADDR, 0x0000100C, 0x0000856e);   //PHY0 Config data  
		RAM_REG_WORD_WRITE(BASE_ADDR, 0x00001008, 0x00000F87);   //PHY0 Config addr 
		
		RAM_REG_WORD_WRITE(BASE_ADDR, 0x0000100C, 0x00000051);   //PHY0 Config data  
		RAM_REG_WORD_WRITE(BASE_ADDR, 0x00001008, 0x00000E87);   //PHY0 Config addr  
	  RAM_REG_WORD_WRITE(BASE_ADDR, 0x0000100C, 0x000014f6);   //PHY0 Config data  
		RAM_REG_WORD_WRITE(BASE_ADDR, 0x00001008, 0x00000F87);   //PHY0 Config addr 	

	  RAM_REG_WORD_WRITE(BASE_ADDR, 0x0000100C, 0x00000029);   //PHY0 Config data  
		RAM_REG_WORD_WRITE(BASE_ADDR, 0x00001008, 0x00000E87);   //PHY0 Config addr  
	  RAM_REG_WORD_WRITE(BASE_ADDR, 0x0000100C, 0x0000000d);   //PHY0 Config data  
		RAM_REG_WORD_WRITE(BASE_ADDR, 0x00001008, 0x00000F87);   //PHY0 Config addr 	
		
	  RAM_REG_WORD_WRITE(BASE_ADDR, 0x0000100C, 0x000000A0);   //PHY0 Config data  
		RAM_REG_WORD_WRITE(BASE_ADDR, 0x00001008, 0x00000E87);   //PHY0 Config addr  
	  RAM_REG_WORD_WRITE(BASE_ADDR, 0x0000100C, 0x0000A8D0);   //PHY0 Config data  
		RAM_REG_WORD_WRITE(BASE_ADDR, 0x00001008, 0x00000F87);   //PHY0 Config addr 
		
		RAM_REG_WORD_WRITE(BASE_ADDR, 0x0000100C, 0x0000080c);   //PHY0 Config data  
		RAM_REG_WORD_WRITE(BASE_ADDR, 0x00001008, 0x00000487);   //PHY0 Config addr  	
		
		RAM_REG_WORD_WRITE(BASE_ADDR, 0x0000100C, 0x00001C01);   //PHY0 Config data  
		RAM_REG_WORD_WRITE(BASE_ADDR, 0x00001008, 0x00001E07);   //PHY0 Config addr  		
		
		RAM_REG_WORD_WRITE(BASE_ADDR, 0x0000100C, 0x00004140);   //PHY0 Config data  
		RAM_REG_WORD_WRITE(BASE_ADDR, 0x00001008, 0x00001A07);   //PHY0 Config addr   

}

void MacConfig(uint32_t BASE_ADDR){
	
	  RAM_REG_WORD_WRITE(BASE_ADDR, 0x00001000, 0x0100080C);                                                              //Config Register Setting
	  //RAM_REG_WORD_WRITE(RAM_BASE, 0x00001004, 0x000000C0);  //Frame Filter Setting
		//RAM_REG_WORD_WRITE(RAM_BASE, 0x00001004, 0x00000010);  //Frame Filter Setting
	  RAM_REG_WORD_WRITE(BASE_ADDR, 0x00001004, 0x80000000);   //Frame Filter Setting
	  RAM_REG_WORD_WRITE(BASE_ADDR, 0x00001010, 0x00000000);   //Flow Control 
	  RAM_REG_WORD_WRITE(BASE_ADDR, 0x00001014, 0x00000000);   //VLAN Tag Setting
	  RAM_REG_WORD_WRITE(BASE_ADDR, 0x0000101C, 0x8000DA01);   //Local MAC Address Setting H
	  RAM_REG_WORD_WRITE(BASE_ADDR, 0x00001020, 0x02030405);   //Local MAC Address Setting L
		                                                           
	  RAM_REG_WORD_WRITE(BASE_ADDR, 0x00001044, 0x00000080);   //Config Mmeory Control Register Setting
}

int main(void)
{
	uint32_t mem_rx_data[128];
	uint32_t mem_ctrl_rx_len;
	uint32_t mem_ctrl_rx_status;
	uint32_t mem_ctrl_rx_len_div4;

  uint32_t select_ram       = 0x00000000;
  uint32_t transmitte       = 0x00000031;
	uint32_t frame_type       = 0x00000000;
  uint32_t broadcast_replay = 0x00000001;
	uint32_t icmp_echo_replay = 0x00000002;
	
	  HME_UART_InitTypeDef init;
    HME_UART_DeInit(UART0);
    HME_UART_StructInit(&init);
    HME_UART_Init(UART0, &init);
    printf("sys start \n");
	  
	  PhyConfig(RAM_BASE);
    MacConfig(RAM_BASE);
    Delay(100);
		
	  while(1){
 			RxFifoStatus();
			ReadData(mem_rx_data,&mem_ctrl_rx_len,&mem_ctrl_rx_len_div4);
			mem_ctrl_rx_status = RAM_REG_WORD_READ(RAM_BASE,0x00001050);
			frame_type = FrameType(mem_rx_data);	
			if (frame_type == broadcast_replay){
				BroadcastReplay(mem_rx_data,&mem_ctrl_rx_len_div4,&mem_ctrl_rx_len,&select_ram,&transmitte);
				SelectRamArea(&select_ram,&transmitte);
      }
			else if (frame_type == icmp_echo_replay){
				IcmpEchoReplay(mem_rx_data,&mem_ctrl_rx_len_div4,&mem_ctrl_rx_len,&select_ram,&transmitte);
				SelectRamArea(&select_ram,&transmitte);
			}
			else{};
	  }
		
		Delay(100);
	return 0;
}


	
//	  RAM_REG_WORD_WRITE(RAM_BASE, 0x00000004, 0x6C3C8C2A);   //Write Frame Data to RAM0  mac frame head 
//	  RAM_REG_WORD_WRITE(RAM_BASE, 0x00000008, 0x5359DA01);   //Write Frame Data to RAM0
//	  RAM_REG_WORD_WRITE(RAM_BASE, 0x0000000C, 0x02030405);   //Write Frame Data to RAM0
//	  RAM_REG_WORD_WRITE(RAM_BASE, 0x00000010, 0x08000102);   //Write Frame Data to RAM0
//	  RAM_REG_WORD_WRITE(RAM_BASE, 0x00000014, 0x03040506);   //Write Frame Data to RAM0
//	  RAM_REG_WORD_WRITE(RAM_BASE, 0x00000018, 0x0708090A);   //Write Frame Data to RAM0
//	  RAM_REG_WORD_WRITE(RAM_BASE, 0x0000001C, 0x0B0C0D0E);   //Write Frame Data to RAM0
//	  RAM_REG_WORD_WRITE(RAM_BASE, 0x00000020, 0x0F101112);   //Write Frame Data to RAM0
//		RAM_REG_WORD_WRITE(RAM_BASE, 0x00000024, 0x13141516);   //Write Frame Data to RAM0
//		RAM_REG_WORD_WRITE(RAM_BASE, 0x00000028, 0x1718191A);   //Write Frame Data to RAM0
//		RAM_REG_WORD_WRITE(RAM_BASE, 0x0000002C, 0x1B1C1D1E);   //Write Frame Data to RAM0
//		RAM_REG_WORD_WRITE(RAM_BASE, 0x00000030, 0x1F202122);   //Write Frame Data to RAM0
//		RAM_REG_WORD_WRITE(RAM_BASE, 0x00000034, 0x23242526);   //Write Frame Data to RAM0
//		RAM_REG_WORD_WRITE(RAM_BASE, 0x00000038, 0x2728292A);   //Write Frame Data to RAM0
//		RAM_REG_WORD_WRITE(RAM_BASE, 0x0000003C, 0x2B2C2D2E);   //Write Frame Data to RAM0
//		RAM_REG_WORD_WRITE(RAM_BASE, 0x00000040, 0x2F303132);   //Write Frame Data to RAM0 

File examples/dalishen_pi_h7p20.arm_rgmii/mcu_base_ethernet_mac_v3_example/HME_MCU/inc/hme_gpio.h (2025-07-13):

/*
 * @file     hme_gpio.h
 * @brief   HME HeaderFile
 * @version  0.1
 * @date     01. March 2021
 */

#ifndef __HME_GPIO_H__
#define __HME_GPIO_H__

#ifdef __cplusplus
extern "C" {
#endif

#include "hme_conf.h"

/**
 * @addtogroup HME
 * @{
 */

/**
 * @addtogroup HME_GPIO
 * @{
 */

/*****************************************************************************/

/**
 * \~english @defgroup GPIO_PINS GPIO Pins
 * \~chinese @defgroup GPIO_PINS GPIO 引脚
 * \~ @{
 */
#define GPIO_PIN0  (1 << 0) /* Pin 0 selected */
#define GPIO_PIN1  (1 << 1)
#define GPIO_PIN2  (1 << 2)
#define GPIO_PIN3  (1 << 3)
#define GPIO_PIN4  (1 << 4)
#define GPIO_PIN5  (1 << 5)
#define GPIO_PIN6  (1 << 6)
#define GPIO_PIN7  (1 << 7)
#define GPIO_PIN8  (1 << 8)
#define GPIO_PIN9  (1 << 9)
#define GPIO_PIN10 (1 << 10)
#define GPIO_PIN11 (1 << 11)
#define GPIO_PIN12 (1 << 12)
#define GPIO_PIN13 (1 << 13)
#define GPIO_PIN14 (1 << 14)
#define GPIO_PIN15 (1 << 15)
#define GPIO_PIN16 (1 << 16)
#define GPIO_PIN17 (1 << 17)
#define GPIO_PIN18 (1 << 18)
#define GPIO_PIN19 (1 << 19)
#define GPIO_PIN20 (1 << 20)
#define GPIO_PIN21 (1 << 21)
#define GPIO_PIN22 (1 << 22)
#define GPIO_PIN23 (1 << 23)
#define GPIO_PIN24 (1 << 24)
#define GPIO_PIN25 (1 << 25)
#define GPIO_PIN26 (1 << 26)
#define GPIO_PIN27 (1 << 27)
#define GPIO_PIN28 (1 << 28)
#define GPIO_PIN29 (1 << 29)
#define GPIO_PIN30 (1 << 30)
#define GPIO_PIN31 (1 << 31)
/**
 * \\~ @}
 */

/**
 * \~english @defgroup GPIO_EXIT_MODE GPIO External Interrupt
 * \~chinese @defgroup GPIO_EXIT_MODE GPIO 外部中断
 * \~ @{
 */
/*!< \~english GPIO Ex */
/*!< \~chinese GPIO GPIO_Pins @ref GPIO_PINS */
#define GPIO_EXIT_MODE_ACTIVE_LOW   (0x0)
#define GPIO_EXIT_MODE_FALLING_EDGE (0x1)
#define GPIO_EXIT_MODE_ACTIVE_HIGH  (0x2)
#define GPIO_EXIT_MODE_RISING_EDGE  (0x3)
/**
 * \\~ @}
 */

/**
 * \~english @defgroup HME_GPIO_Mode GPIO Mode, Include Hareware/Software(INPUT, OUTPUT)
 * \~chinese @defgroup HME_GPIO_Mode GPIO 模式，包括输入模式、输出模式、硬件模式
 * \~ @{
 */
typedef enum HME_GPIO_Mode {
    /*! \~english GPIO Software Input Mode */
    /*! \~chinese GPIO 软件输入模式 */
    PIN_MODE_INPUT = 0x0,

    /*! \~english GPIO Software Output Mode */
    /*! \~chinese GPIO 软件输出模式 */
    PIN_MODE_OUTPUT,

    /*! \~english GPIO Hardware Mode */
    /*! \~chinese GPIO 硬件模式 */
    PIN_MODE_HARTWARE,
} HME_GPIO_Mode;
/**
 * \~ @}
 */

/**
 * \~english @defgroup HME_GPIO_InitTypeDef GPIO Init structure definition
 * \~chinese @defgroup HME_GPIO_InitTypeDef GPIO 初始化结构体
 * \~ @{
 */
typedef struct {
    uint32_t Pins; /*!< \~english GPIO GPIO_Pins @ref GPIO_PINS */
                   /*!< \~chinese GPIO 引脚 @ref GPIO_PINS 使用或的方式支持多个引脚 */
    /*! \~english GPIO Mode @ref GPIO_MODE */
    /*! \~chinese GPIO 模式 @ref GPIO_MODE */
    uint32_t Mode;
} HME_GPIO_InitTypeDef;
/**
 * \~ @}
 */

/**
 * \~english @defgroup HME_GPIOA_ExitITTypeDef GPIO Exit Interrupt Structure Definition
 * \~chinese @defgroup HME_GPIOA_ExitITTypeDef GPIO 外部中断结构体定义
 * \~ @{
 */
typedef struct {
    uint32_t Mode; /*!< TODO */
    bool Debounce; /*!< TODO */
    bool Enable;   /*!< TODO */
} HME_GPIOA_ExitITTypeDef;
/**
 * \~ @}
 */

/**
 * \~ @}
 */

/*****************************************************************************/

/**
 * \~english @brief Deinitializes the GPIO registers to their default reset values.
 * \~english @note This function is optional.
 * \~english @retval None
 *
 * \~chinese @brief 将 GPIO 寄存器复位成默认值。
 * \~chinese @note 这个函数是可选的。
 * \~chinese @retval 无
 */
extern void HME_GPIO_DeInit(GPIO_Type* GPIOx);

/**
 * \~english @brief Initialize GPIO
 * \~english @param[in] GPIO_PORT: GPIO group, which is a value of @ref GPIO_PORT
 * \~english @param[in] GPIO_Init : A pointer to structure HME_GPIO_InitTypeDef that contains
 * \~english @retval None
 *
 * \~chinese @brief 初始化 GPIO
 * \~chinese @param[in] GPIO_PORT: GPIO group, which is a value of @ref GPIO_PORT
 * \~chinese @param[in] GPIO_Init : 结构体 @ref HME_GPIO_InitTypeDef 的指针
 * \~chinese @retval 无
 */
extern void HME_GPIO_Init(GPIO_Type* GPIOx, HME_GPIO_InitTypeDef * Init);

/**
 * \~english @brief Fills each @ref HME_GPIO_InitTypeDef member with its default value.
 * \~english @param[in] GPIO_Init: A pointer to structure HME_GPIO_InitTypeDef which will be initialized.
 * \~english @retval None
 *
 * \~chinese @brief 填充结构体 @ref HME_GPIO_InitTypeDef 的成员
 * \~chinese @param[in] GPIO_Init: 已初始化的结构体 @ref HME_GPIO_InitTypeDef 的指针
 * \~chinese @retval 无
 */
extern void HME_GPIO_StructInit(HME_GPIO_InitTypeDef *GPIO_Init);
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

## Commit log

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2025-06-02 修正摄像头链接
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2025-06-02 dalishen_pi_h7p20硬件图纸，开发中，仅备份
    [ET3036C.kicad_sch, USB334x.kicad_sch, YT8531C.kicad_sch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]
2025-06-02 更新硬件图
    [ET3036C.kicad_sch, USB334x.kicad_sch, USB_A_Molex_67643_Horizontal.step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]
2025-06-04 硬件：usb_sniffer_h7p20，初稿，未审查
    [ET3036C.kicad_sch, USB334x.kicad_sch, USB_A_Molex_67643_Horizontal.step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]
2025-06-04 增加辅助电路和优化焊盘工艺
    [ET3036C.kicad_sch, USB334x.kicad_sch, usb_sniffer_h7p20.kicad_pcb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]
2025-06-06 调整上电顺序为 5V -> core 0.95V -> vccaux 1.8V -> vccio
    [BOM-usb_sniffer_h7p20.csv, BOM-usb_sniffer_h7p20.forJLC.csv, ET3036C.kicad_sch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]
2025-06-06 更新丝印
    [usb_sniffer_h7p20.kicad_pcb]
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2025-06-07 [usb_sniffer_h7p20]增加JTAG排针，增加产品页二维码
    [BOM-usb_sniffer_h7p20.csv, BOM-usb_sniffer_h7p20.forJLC.csv, ET3036C.kicad_sch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]
2025-06-15 [usb_sniffer_h7p20] 结构优化与验证
    [ET3036C.kicad_sch, USB334x.kicad_sch, dalishen_pi_h7p20.kicad_pcb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]
2025-06-16 [usb_sniffer_h7p20] 修复USB3343参考时钟电路错误；修复USB3343 RESET脚上拉错误
    [USB334x.kicad_sch, usb_sniffer_h7p20.kicad_pcb, usb_sniffer_h7p20.kicad_sch]
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2025-06-16 [usb_sniffer_h7p20] 68013的eeprom增加boot点，用于二次更新68013固件
    [usb_sniffer_h7p20.kicad_pcb, usb_sniffer_h7p20.kicad_sch]
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2025-06-17 [usb_sniffer_h7p20] 预留外部触发接口，优化布局，支持M4隔离柱
    [usb_sniffer_h7p20.kicad_pcb, usb_sniffer_h7p20.kicad_sch]
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2025-06-18 [usb_sniffer_h7p20] 使用USB5V驱动LM2903
    [USB334x.kicad_sch, usb_sniffer_h7p20.kicad_pcb]
2025-06-19 [usb_sniffer_h7p20] 移除NC器件，更换LM2903A-VR，双螺丝孔固定
    [USB334x.kicad_sch, usb_sniffer_h7p20.kicad_pcb, usb_sniffer_h7p20.kicad_sch]
2025-06-20 [usb_sniffer_h7p20] 优化USB封装精度，优化定位孔精度
    [USB334x.kicad_sch, usb_sniffer_h7p20.kicad_pcb, usb_sniffer_h7p20.kicad_sch]
2025-06-20 [usb_sniffer_h7p20] production_files.2025620
    [BOM-usb_sniffer_h7p20.csv, BOM-usb_sniffer_h7p20.forJLC.csv, USB334x.kicad_sch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]
2025-06-21 [dalishen_pi_h7p20] backup
    [ET3036C.kicad_sch, USB334x.kicad_sch, YT8531C.kicad_sch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]
2025-06-21 [usb_sniffer_h7p20] 优化上电
    [BOM-usb_sniffer_h7p20.csv, BOM-usb_sniffer_h7p20.forJLC.csv, ET3036C.kicad_sch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]
2025-06-22 [usb_sniffer_h7p20] USB3343兼容CH132F，作相关调整
    [BOM-usb_sniffer_h7p20.csv, BOM-usb_sniffer_h7p20.forJLC.csv, USB334x.kicad_sch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]
2025-06-22 [dalishen_pi_h7p20] 原理图初稿
    [ET3036C.kicad_sch, ET3036C_CJ3439KDW.kicad_sch, USB334x.kicad_sch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]
2025-06-23 [dalishen_pi_h7p20] 原理图预审
    [USB334x.kicad_sch, dalishen_pi_h7p20.kicad_pcb, dalishen_pi_h7p20.kicad_sch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]
2025-06-23 [dalishen_pi_h7p20] CRST电容增大、MIPI CSI使用同一bank
    [dalishen_pi_h7p20.kicad_pcb, dalishen_pi_h7p20.kicad_sch]
2025-06-24 [dalishen_pi_h7p20] layout done
    [YT8531C.kicad_sch, dalishen_pi_h7p20.kicad_sch]
2025-06-24 [dalishen_pi_h7p20] 样板
    [BOM-dalishen_pi_h7p20.csv, YT8531C.kicad_sch, dalishen_pi_h7p20.kicad_sch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]
2025-06-25 [usb_sniffer_h7p20] 优化局部走线
    [usb_sniffer_h7p20.kicad_pcb]
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2025-07-07 [dalishen_pi_h7p20] YT8531C需增加一个电感；需从XO引入时钟，XI接地； 剩余样板需换贴YC8531DC或者手工割线加电感。千兆协商通过。 LAYOUT优化
    [ET3036C_CJ3439KDW.kicad_sch, USB334x.kicad_sch, YT8531C.kicad_sch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]
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2025-07-11 [dalishen_pi_h7p20] production_files.20250711 不贴片，仅用于电源排查
    [dalishen_pi_h7p20.kicad_pcb]
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2025-07-13 [dalishen_pi_h7p20] 两个双排针的VCC脚通过短接点连接3.3V，预留给其他扩展模块供电的能力。
    [dalishen_pi_h7p20.kicad_pcb, dalishen_pi_h7p20.kicad_sch]
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2025-07-17 [dalishen_pi_h7p20] 优化LAYOUT
    [dalishen_pi_h7p20.kicad_pcb]
2025-08-08 将USB3343替换为CH132C，ULPI时钟由FPGA产生
    [ET3036C.kicad_sch, USB334x.kicad_sch, usb_sniffer_h7p20.kicad_pcb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]
2025-08-11 [dalishen_pi_h7p20] 使用无工艺边设计
    [dalishen_pi_h7p20.kicad_pcb]
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2025-08-12 [usb_sniffer_h7p20] 适配铝合金外壳、更换CH132C
    [ET3036C.kicad_sch, USB334x.kicad_sch, usb_sniffer_h7p20.kicad_pcb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]
2025-08-13 [usb_sniffer_h7p20] 待审查
    [usb_sniffer_h7p20.kicad_pcb, usb_sniffer_h7p20.kicad_sch]
2025-08-13 [usb_sniffer_h7p20] 20250813 打样
    [BOM-usb_sniffer_h7p20.csv, BOM-usb_sniffer_h7p20.forJLC.csv, usb_sniffer_h7p20.kicad_pcb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]
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2025-08-18 [usb_sniffer_h7p20] CH132C测试无数据，回退USB3343
    [BOM-usb_sniffer_h7p20.csv, BOM-usb_sniffer_h7p20.forJLC.csv, ET3036C.kicad_sch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]
2025-08-18 [usb_sniffer_h7p20] 统一使用P25Q64SH-SSH-IR
    [BOM-usb_sniffer_h7p20.csv, BOM-usb_sniffer_h7p20.forJLC.csv, usb_sniffer_h7p20.kicad_pcb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]
2025-08-19 [dalishen_pi_h7p20] 备份
    [dalishen_pi_h7p20.kicad_pcb, dalishen_pi_h7p20.kicad_sch]
2025-08-21 [dalishen_pi_h7p20] production_files.20250820
    [BOM-dalishen_pi_h7p20.csv, ET3036C_CJ3439KDW.kicad_sch, dalishen_pi_h7p20.kicad_sch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]
2025-08-22 [dalishen_pi_h7p20] production_files.20250820 新增保险丝
    [dalishen_pi_h7p20.kicad_sch, vllinkmodule.kicad_sch]
2025-08-24 [usb_sniffer_h7p20] 换GSV332-MR，待测试
    [USB334x.kicad_sch, usb_sniffer_h7p20.kicad_pcb]
2025-08-27 [usb_sniffer_h7p20] production_files.20250828
    [BOM-usb_sniffer_h7p20.csv, BOM-usb_sniffer_h7p20.forJLC.csv, usb_sniffer_h7p20.kicad_pcb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]
2025-09-14 [dalishen_pi_h7p20] A母换SMT型号
    [USB334x.kicad_sch]
2025-09-16 [dalishen_pi_h7p20] 68013替换为双USB3343
    [USB334x.kicad_sch, USB334x_SP.kicad_sch, dalishen_pi_h7p20.kicad_sch]
2025-09-16 [dalishen_pi_h7p20] 增加I2C小屏，增加两个测试IO
    [USB334x.kicad_sch, dalishen_pi_h7p20.kicad_sch]
2025-09-17 [dalishen_pi_h7p20] 待review
    [USB334x.kicad_sch, USB334x_SP.kicad_sch, dalishen_pi_h7p20.kicad_sch]
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2025-09-22 [dalishen_pi_h7p20]自锁开关脚位修正
    [USB334x.kicad_sch]
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
